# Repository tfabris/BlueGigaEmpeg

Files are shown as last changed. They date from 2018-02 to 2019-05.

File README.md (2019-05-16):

BlueGigaEmpeg
==============================================================================
&copy; 2018 by Tony Fabris

https://github.com/tfabris/BlueGigaEmpeg

BlueGigaEmpeg is a project to use a Silicon Labs BlueGiga WT32i Bluetooth
chip, combined with an Arduino Mega board, to act as an interface between an
empeg Car Mk2/2a MP3 player and a modern Bluetooth-equipped car.

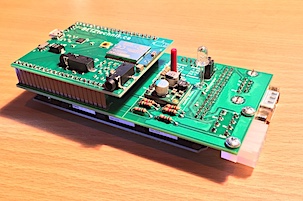
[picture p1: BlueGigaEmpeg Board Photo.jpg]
Board
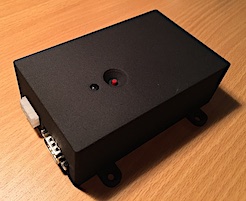
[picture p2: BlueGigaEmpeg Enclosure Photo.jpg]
Enclosure
 

------------------------------------------------------------------------------

Table of Contents
==============================================================================

- [Introduction                                                                    ](#introduction)
- [Installation                                                                    ](#installation)
- [Usage                                                                           ](#usage)
- [Troubleshooting                                                                 ](#troubleshooting)
- [Updating firmware                                                               ](#updating-firmware)
- [Technical Data                                                                  ](#technical-data)

------------------------------------------------------------------------------

Introduction
==============================================================================
- [Project Information                                                             ](#project-information)
- [Caveats                                                                         ](#caveats)
- [Acknowledgments                                                                 ](#acknowledgments)

Project Information
------------------------------------------------------------------------------
The empeg Car (small "e") player, also sold as the Rio Car, is an amazing
in-dash MP3 player made from 1999-2001 whose features are still, nearly 20
years later, better than any other in-car MP3 solution available. However, the
empeg Car didn't have Bluetooth since it wasn't in common use yet at the time.

Modern cars are becoming increasingly difficult to install aftermarket stereos
into, due to the car touchscreen dashboards and the high level of integration
of the stereo system into the other car systems. For owners of the empeg Car
player, it's a problem, because it makes it hard to install our beloved player
into our new cars. This project helps to solve this issue by adding digital
Bluetooth output to the empeg Car player, allowing it to be connected to a
modern car's factory stereo system, and integrate with its controls, in the
same way that you would connect a smartphone to your car.

The BlueGigaEmpeg interface works in two ways:

1. Bluetooth A2DP connection allows high quality digital audio from the empeg
   Car player to play on the modern car's stereo speakers without needing an
   Aux Input on the car stereo. This is useful because many cars no longer have
   an Aux Input available, yet most new cars have Bluetooth. 

2. Bluetooth AVRCP connection allows the empeg Car to receive commands such as
   "next", "previous", "pause", etc. from the Bluetooth connection, allowing
   the car stereo's touchscreen and steering wheel controls to be able to
   change tracks and control playback on the empeg. In addition, the same AVRCP
   channel allows track title and artist information to be displayed on the car
   stereo's touchscreen.

Demo video: https://www.youtube.com/watch?v=XS9U_ALc634

Some modification of the empeg Car is required in order for this to work. The
Molex connector on the empeg docking sled's wiring harness, which is normally
used for an external AM/FM tuner module, must be converted into a digital
audio interface for sending audio data to the BlueGigaEmpeg module. Make sure
to perform all modifications listed in the [Installation](#installation)
section of this document.

Caveats
------------------------------------------------------------------------------
- This project only works with the empeg Car Mk2 or the Rio Car player. It
  will not work with the empeg Car Mk1 player.

- At the time of this writing, I have tested this project on a very limited set
  of Bluetooth gear. So far, I have only tested it on:
  - My Honda Accord 2017 factory stereo.
  - Kenwood KDC-BT318U car stereo.
  - Plantronics Voyager Edge Bluetooth headset.
  - Onkyo TX-SR33 home stereo with Bluetooth input.
  - Etekcity EA-TR1 standalone Bluetooth receiver.
  - iHome Li-B33E7 toy Stardestroyer with a Bluetooth speaker.

- Some Bluetooth stereo playback devices do not have full functionality. For
  example, The Onkyo listed above does not display AVRCP track titles, and my
  2017 Honda does not have controls for Shuffle, Fast Forward, or Rewind. As
  far as I can tell, these are limitations of the devices themselves, not
  problems with the BlueGigaEmpeg: These same limitations exist when those
  devices are paired with smartphones, too.

- This implementation uses the default codec for A2DP audio, SBC (Sub Band
  Codec). This introduces a slight delay in the audio, meaning that the music
  coming out of your car stereo speakers will be slightly delayed from the
  visuals on the empeg screen.

- There are differences in Bluetooth implementation on various audio gear, and
  so there still might be bugs when using the BlueGigaEmpeg on your particular
  car stereo. This project is open source on GitHub, so that I can accept bug
  reports and code fixes from people with other brands of Bluetooth gear.

- This is not intended to replace the empeg front panel user interface. This
  only allows you to do things like press Next Track, Pause, and Play on your
  car stereo. The full menu and user interface of the empeg is still needed
  for all other features of the empeg, such as selecting playlists. So this
  module won't let you mount the empeg in your trunk, unless you also have a
  display extender kit from Eutronix.com as well, which would allow you to
  reach the empeg front panel from the driver's seat. Unfortunately,
  Eutronix.com isn't selling display extenders any more. I was lucky to get a
  display extender several years ago when they were still being sold, so I'm
  able to mount my empeg in my trunk with this. But if you don't have a
  display extender kit, you will still have to mount your empeg someplace
  where you can reach it from the driver's seat.
  - By the way, don't try rolling your own display extender by simply
    extending the wires. Special buffer circuitry is required in order to
    safely extend the empeg display, or you run the risk of damaging the empeg
    or its display.

Acknowledgments
------------------------------------------------------------------------------
Many thanks to the members of the empegBBS who helped with this so much. The
initial chip suggestion was by BBS member Elperepat, and even though I ended
up not using the particular chip that he suggested (I had trouble with that
chip), it was his suggestion that started me experimenting with Bluetooth. Big
thanks to Shonky who had many helpful suggestions and who pointed out the
WT32i chip that is the one that finally got used in this particular design.
Also particular thanks to Stuart Euans of Eutronix.com who created the empeg
Display Extender board, which was critical to me being able to get my empeg
mounted cleanly in my new Honda, since it doesn't have dash space for the
whole empeg. Big thanks to Peter Betz of Betztechnik, who made a convenient
and perfectly-sized breakout board containing the chip I wanted to work with,
and who was very helpful and responsive in emails, and even made another
manufacturing run with an updated design for me. And massive thanks to Mark
Lord who assisted me in countless ways with the design and implementation,
taught me a ton of important things, found my bugs, fixed issues with the
Arduino compiler, modified his Hijack kernel to support this project, and
pointed out all of my EE design flaws. And last but not least, thanks to the
entire empeg team who made such a fantastic car MP3 player that we are still
doing interesting things with it, nearly 20 years later.

Installation
==============================================================================
Installing the BlueGigaEmpeg module requires some modifications to your empeg
Car player. Make sure to go through each of the steps linked below.

- [Prerequisites                                                                   ](#prerequisites)
- [Modify empeg Car interior for I2S digital audio connection                      ](#modify-empeg-car-interior-for-i2s-digital-audio-connection)
- [Disconnect all tuner modules from all sleds you own                             ](#disconnect-all-tuner-modules-from-all-sleds-you-own)
- [Empeg Car configuration changes                                                 ](#empeg-car-configuration-changes)
- [Upgrade the empeg Car's Hijack kernel and set "Serial Port Assignment"          ](#upgrade-the-empeg-cars-hijack-kernel-and-set-serial-port-assignment)
- [Modify empeg's power connection to car                                          ](#modify-empegs-power-connection-to-car)
- [Connect BlueGigaEmpeg to empeg Car player                                       ](#connect-bluegigaempeg-to-empeg-car-player)
- [Mounting                                                                        ](#mounting)

Prerequisites
------------------------------------------------------------------------------
Make sure you have all of these things before working with the BlueGigaEmpeg:

####  Purchase:
| Item | URL |
|:---|:---|
| Empeg Mk2 or Rio Car player | http://empegbbs.com/ubbthreads.php/forums/11/1/For_Sale |
| BlueGigaEmpeg Interface | tfabris@gmail.com |

####  Download software (Windows PC or Windows VM required for some of these items):
| Item | URL |
|:---|:---|
| Hijack Kernel for empeg | http://empeg-hijack.sourceforge.net |
| Tony's Empeg Logo Editor | http://empegbbs.com/ubbthreads.php/ubb/download/Number/7067/filename/logoedit17.zip |
| Arduino standalone IDE | https://www.arduino.cc/en/Main/Software |
| Latest BlueGigaEmpeg Arduino firmware | Direct download latest project file: https://github.com/tfabris/BlueGigaEmpeg/archive/master.zip |
| | (Alternative) GitHub project for cloning, if you are using the Git tool: https://github.com/tfabris/BlueGigaEmpeg |

####  Important:

The BlueGigaEmpeg module works by connecting to the Molex connector on the
empeg Car's docking sled wiring harness. This connector was originally
intended for the empeg's external tuner module. The empeg must be modified so
that the tuner module connector becomes a digital audio connection instead.

Do not connect the BlueGigaEmpeg to the tuner module connector until after
completing the step in this document titled ["Modify empeg Car interior for
I2S digital audio connection"](#i2s). Also, once the I2S modification has been
completed, connect the Molex tuner module connector *only* to the
BlueGigaEmpeg, do not connect it to a tuner module, or to anything else.
Damage may occur if these instructions are not followed.

Be sure you are capable of safely making internal modifications to the empeg
Car player, and you are able to solder and shrink-tube electronic components.
I take no responsibility for damage incurred while you are dismantling and
modifying your empeg Car player.

Modify empeg Car interior for I2S digital audio connection
------------------------------------------------------------------------------
To perform this step, you must be comfortable with disassembling the empeg Car
player and removing the disk drive tray in such a way as to not cause damage
to the player. In particular, there is risk to the components on the back side
of the display board, and to the IDE header connector on the empeg
motherboard. Use extreme caution when disassembling the empeg player.

You will be modifying the interior of your empeg Car so that there can be
three wires coming out the docking connector which carry digital audio data
("I2S" aka "IIS") and can connect to the BlueGigaEmpeg unit. This is done by
hijacking three of the wires originally used for the empeg tuner module on its
Molex connector. This tuner module connector will instead plug into the
BlueGigaEmpeg electronic assembly, which contains the Bluetooth chip and the
Arduino.

The empeg tuner module will no longer work after this modification, and damage
may occur if you connect one to your player. If you have a tuner module, now is
a good time to disconnect it from the sled and put it away.

####  Disassembly of empeg Car:

Partially disassemble your empeg player by carefully removing the fascia, lid
and drive tray, as described below. You must do the disassembly gently, so as
not to damage the empeg. Make sure not to break any of the components sticking
off the back of the display board as you do this.

- Use a 2.5mm hex tool to carefully remove four hex bolts from the fascia.

- Gently remove fascia, buttons, rotary control, and colored lens.

- Extend the hinged pullout handle during the next step. This lowers the
  keeper hooks on the top of the player, which keep it hooked into the sled
  and which will also interfere with the lid removal if they aren't lowered.
  If you have trouble removing the lid in the next step, first double check
  that the handle is in the extended position.

- Remove lid by sliding it forward and upward over the tabs. This may be
  tricky on some players, requiring some gentle levering against the tabs with
  a screwdriver. You shouldn't need to bend or force anything, but it may be a
  bit of a tight fit as you remove it. Use caution not to slip and damage the
  components on the display board. As shown in this photo:
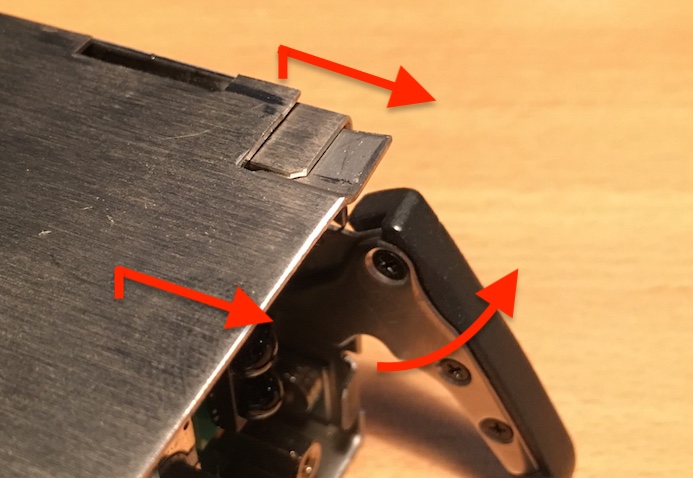
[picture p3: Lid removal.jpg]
Lid removal
  

- Do not remove the display board.

- Remove four Pozidriv screws on the outside sides of the player which are
  holding the disk drive tray in place. Be careful not to strip the screw
  heads by using the wrong size or type of screwdriver. Make sure to select a
  screwdriver which fits the heads of the screws good and tight. Information
  about Pozidriv screws can be found here:
  https://en.wikipedia.org/wiki/List_of_screw_drives#Pozidriv

- Gently lift out the drive tray. Make sure not to bump any of the
  components on the back of the display board. There are some particularly
  fragile components there, and it's really important that you don't bump
  them, or your empeg display will stop working entirely. They are really easy
  to hit, too, so be super careful.

- When lifting out the drive tray, take note of how the IDE cable is folded
  and routed so that you can put it back exactly as you found it. 

- Do not disconnect the IDE cable. You should be able to set the drive tray
  gently aside, without disconnecting the cable, and also without putting
  any stress on the cable.

####  Jumper the I2S pads to the docking connector wires:

Refer to the annotated photograph "I2S Wiring Modification Photo.jpg" to help
understand the wiring instructions below.

I2S Wiring Modification Photo.jpg:
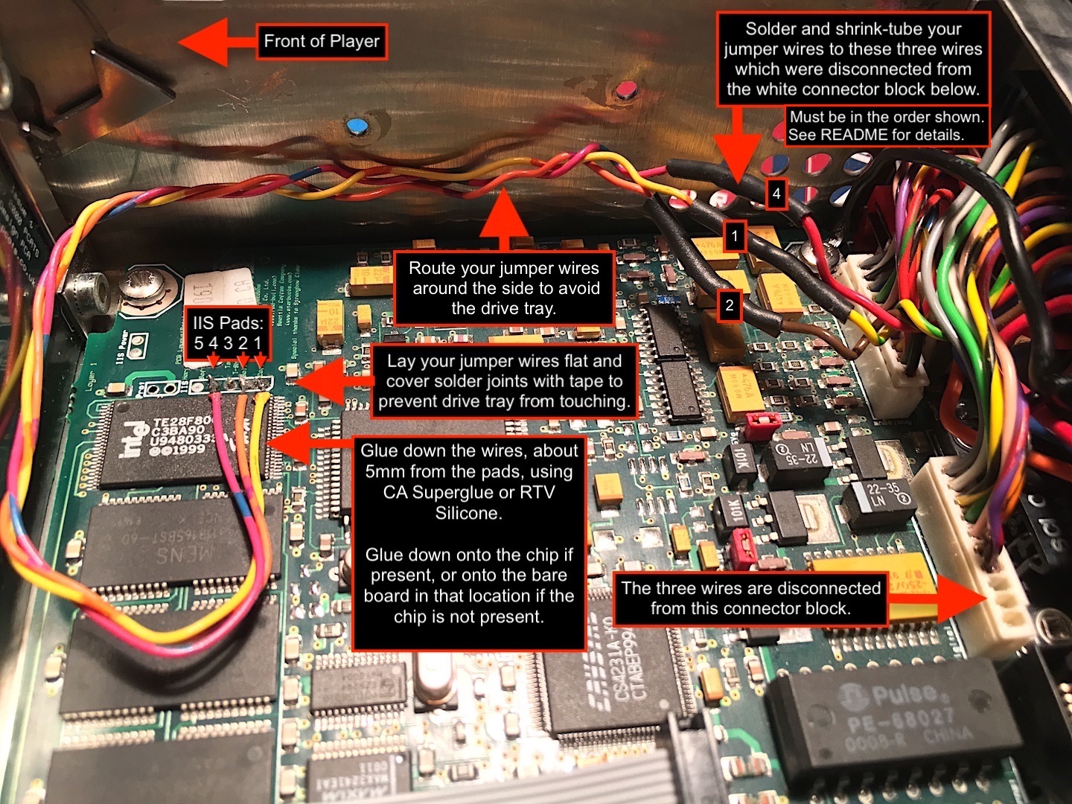
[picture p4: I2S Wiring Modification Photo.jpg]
Wiring Modification


Locate 5 blank I2S pads on the front left side of the empeg motherboard.
Pads are outlined in a white silkscreen rectangle with the letters "IIS" next
to the outline. White silkscreen rectangle will have one corner of it with a
small diagonal "snip" to the corner which will indicate pad number 1 of the
set of 5 pads. This diagonal snip will be towards the back of the empeg, and
the remaining pads continue towards the front of the empeg. Pads are not
individually labeled with numbers, but understand that they are logically
numbered 1 2 3 4 5 starting from the back and going towards the front of the
empeg. The pinouts of these five pads are:

      1 = IISC  aka  SCK     aka "serial clock"
      2 = IISW  aka  WS      aka "word select"
      3 = GND   aka  Ground  same as chassis ground of empeg
      4 = IISD1 aka  SD      aka "serial data" (1 of 2)
      5 = IISD2 aka  SD      aka "serial data" (2 of 2)

Carefully solder the three supplied jumper wires to pads 1,2, and 4, and you
must keep track of which wires are soldered to which pads.

Note: The coloring of the supplied jumper wires is random and arbitrary. They
are each colored differently, so that you can tell which ones were soldered
to which I2S pads, but their particular colors are not intended to match
anything.

When soldering, make sure the jumper wires and the solder joints are flat to
the board instead of sticking upwards. The disk drive tray gets close to that
location when mounted, so make sure they don't have a chance to contact the
tray.

After soldering, cover the solder points with tape or some other insulator to
prevent them from shorting out on the drive tray.

Locate the two white connectors on the back part of the empeg motherboard
which connect two groups of small colored wires to the docking connector
assembly. Locate the rightmost of the two connectors nearest the Ethernet port
on the back of the empeg. Unplug this connector, and using a tiny flat tool
such as the tip of a jeweler's screwdriver, lift up the small white tabs and
gently disengage and pull out the pins. Pull out only the rightmost three pins
nearest the Ethernet connector to free up those three wires. These wires are
colored, going from left to right, yellow+green, red, and brown. The brown
wire is the one on the right end closest to the Ethernet connector, the red
wire is the second from the end, and the yellow+green wire is the third from
the end.

With the three wires disconnected from the white connector, plug the white
connector back into place with the remainder of its wires still connected.
You should now have three wires inside the empeg, each with one end still
connected to the docking connector assembly, and their other ends loose with
small pin connectors on the ends of them.

Carefully solder and shrink-tube your three jumper wires directly to these pin
connectors in the exact order described below. Shrink tubing has been
supplied with the BlueGigaEmpeg. Don't forget to put the shrink tubing onto
the jumper wires before you solder them.

Solder your jumper wires to the empeg interior wires in this order:

- IIS Pad 1 (IISC): jumpered to the yellow+Green wire which was originally the
  third wire the from end of the white connector.
- IIS Pad 2 (IISW): jumpered to the brown wire which was originally the end
  wire on the white connector.
- IIS Pad 4 (IISD1): jumpered to the red wire which was originally the second
  wire from the end of the white connector.

After you have done this, your empeg's I2S pads will, when docked, now be
carried out the back of the empeg, via the docking sled, into the Molex tuner
module connector.

Make sure that your jumper wires are carefully tucked down around the left
side of the empeg and out of the way of the disk drive tray assembly as shown
in the photo linked above.

Glue down your jumper wires near the I2S pads so that they do not wiggle and
rip away the I2S pads. Some empeg Car units will have a chip at that location
that you can glue onto, others will have a blank area of the PCB in that
location that you can glue onto. Use RTV silicone or cyanoacrylate superglue
to glue them down. Use a small amount of glue, and make sure the blob of glue
does not "stick up", since the disk drive tray gets very close to that
location.

After the glue is fully dry, carefully reassemble the player. Reassemble in
the reverse order of disassembly. Make sure to put everything back where you
found it, in particular, make sure the IDE cable is folded and routed the same
way as it was when you disassembled the player.

When reassembling, be careful not to overtighten the hex bolts which hold the
fascia in place, they should only be finger-tight. If you overtighten them,
you may crack the fascia and/or prevent the buttons from working correctly.

Final wiring positions and colors:
                                                                                                                                                                
| Empeg IIS pads | Int. empeg wires * | Int. white conn pos **  | Sled Tuner Plug | BlueGigaEmpeg Tuner Plug | Bluetooth Chip | Usage |
|---|---|---|---|---|---|---|
|  1 IISC |  Yellow+Green wire |  Third from end |  7 Purple |  7  SCK |  30  PCM_CLK |  Serial Clock |
|  2 IISW |  Brown wire |  Right end |  2 Grey |  2  WS |  29  PCM_SYNC  |  Word Select aka Sync |
|  4 IISD1 |  Red wire |  Second from end |  1 Pink |  1  SDIN |  27  PCM_IN |  Serial Data aka PCM Audio Data  |
| | | |  4 Black |  4  GND | GND |  Universal Ground |
| | | |  8 Blue |  8  12vPower | |  Power to voltage regulator |

    *  (These are the interior wires running between the docking sled and the
        white connector on the empeg motherboard.)
    
    ** (Original positions of these wires on the white connector near the
        Ethernet plug, now disconnected from that connector.)

Disconnect all tuner modules from all sleds you own
------------------------------------------------------------------------------
After completing the I2S wiring modification, the external empeg tuner module
will no longer work. Also, damage may occur if you connect a tuner module to a
modified empeg.

To prevent problems, make sure to disconnect any tuner modules from any
docking sleds that you own, and pack them away somewhere safe. After making
the I2S wiring modification to the empeg, do not use a tuner module any more.

Label your empeg with the supplied stickers, which tell your future selves
not to use this particular empeg with tuner modules any more.

Empeg Car configuration changes
------------------------------------------------------------------------------
The following configuration changes are required for BlueGigaEmpeg to work
correctly.

####  Player firmware version:

I have tested the BlueGigaEmpeg with version 2.00 of the empeg Car software.
It is designed to work with version 2.00 Beta 13 or version 2.00 Final. I have
not tested it with the 3.0 Alpha version of the empeg Car software, but
theoretically it should work.

#### Edit the config.ini on the player:

Using the Emplode or Jemplode software, edit the empeg Car's config.ini as
follows.

If you are using Emplode on Windows, you must first edit the Microsoft Windows
registry before it will allow you to alter the config.ini. First, run
REGEDIT.EXE in Windows and modify the following key:

     HKEY_CURRENT_USER
       Software
         SONICblue
           emplode
             2.0
               Settings
                  (Inside the "Settings" key, create a new DWORD value named:)
                    allow_edit_config
                      (with a value of)
                        1              

Then restart the Emplode software. Emplode will now have a menu option
which allows you to edit the config.ini on the player.

Change the settings in config,ini as follows (adding new section headers such
as [hijack] only if that section does not already exist):

    [hijack]
    suppress_notify=2
    
    [output]
    notify=1
    
    [serial]
    car_rate=115200

These settings are case-sensitive. Make sure to synchronize with the player
after changing the config.ini settings.

Upgrade the empeg Car's Hijack kernel and set "Serial Port Assignment"
------------------------------------------------------------------------------
The latest version of Hijack is required in order for BlueGigaEmpeg to work
correctly. Install the latest Hijack Kernel onto the empeg Car player if it is
not already installed. Link to the Hijack kernel is found in the
[Prerequisites](#prerequisites) section of this document. Make sure it is
Hijack version 524 or later.

In order to install the latest Hijack Kernel onto the empeg, you must connect
the empeg directly to your computer's RS-232 serial port, or to a USB-to-
RS-232 adapter cable if your computer does not have an RS-232 serial port.
Make sure the serial port drivers are installed and that you can see the empeg
bootup messages correctly through a serial terminal program.

To install the Hijack kernel, run Tony's Empeg Logo Editor. Link to the Logo
Editor program is found in the [Prerequisites](#prerequisites) section of this
document. This program is a Windows program, but it should also work correctly
on a virtualized version of Windows. For example, I have used it successfully
running under Parallels on a Mac. On the File menu of the logo editor program,
select "Kernel Flash Utility" and follow the instructions.

Once Hijack is installed, open up the Hijack kernel settings on the player via
a long-press on the player's rotary encoder dial. Change "Serial port
assignment" to "Player uses serial port" and follow the on-screen instructions
to reboot the player.

Modify empeg's power connection to car
------------------------------------------------------------------------------
I recommend that for this installation, you connect the empeg's wiring harness
to your car differently than if it were a standard car installation. It might
not be required for your installation, but it was required for mine, so doing
this now could save you time and hassle later.

This BlueGigaEmpeg is designed to turn the empeg into a secondary Bluetooth 
input into a modern car stereo, rather than being the car's main stereo 
system. In this situation, the empeg's sleep mode, the empeg's "memory" power 
connection, the way the BlueGigaEmpeg module gets its power from the empeg 
tuner connector, and the way the car stereo issues Bluetooth commands when 
you shut off the ignition, all combine to cause some interesting problems with
power state transitions.

I found that if I connected the empeg to my car's power via the regular method
(i.e., car accessory power to the orange ignition wire on the sled, and car
constant 12v power to the yellow memory wire on the sled), then there were
certain unusual states that it could get into. Sometimes I would shut off my
car, but the empeg would come back up out of sleep mode and play tracks
silently to an unconnected Bluetooth module, draining my car's battery.

To prevent this problem from happening to you, I recommend connecting power
between the car and the empeg like this instead:

- Orange "ignition" wire from empeg: Connect to car 12v accessory power.
  - "Acessory Power" is the power that is only on when your car ignition is
    on, or your key is set to the "accessory" position so that your car
    stereo is turned on. Or the pushbutton equivalent of that, if your car
    doesn't have a physical key.

- Yellow "memory" wire from empeg: *Also* connect to car 12v accessory power
  (instead of the usual constant power).

- Do *not* connect your car's constant 12v power to any part of the empeg.

- White "lights on" wire from empeg: Connect to car dash illumination power.

- Black "ground" wire from empeg: Connect to car ground.

- Tuner module and serial plug connectors: Connect to BlueGigaEmpeg module.

That should be all you need. No analog audio or amplifier connections, because
the Bluetooth takes care of that now. No cellphone mute wire, because the
Bluetooth takes care of that now. No amp remote wire, because there is no amp
connected directly to the empeg.

When connected this way, the empeg does not receive a 12v constant power
source. Instead, it will completely lose all power when you turn off the
ignition, rather than going into sleep mode. The empeg and its attached
BlueGigaEmpeg module will always power on and off at the same time as the car
stereo, and nothing will get confused about power state. You might lose the
date/time information on the empeg sometimes, but your modern car likely has a
perfectly functional clock of its own. The empeg is already designed to save
its playback position when it unexpectedly loses power, so it will continue to
work correctly in this wiring scheme.

In a normal car install, with analog audio and an amplifier connected to the
empeg, the wiring scheme described above would cause a pop sound when turning
off the ignition. But with the BlueGigaEmpeg, all audio is digital, and goes
through the Bluetooth connection, so there will not be a pop sound.

By the way, I'm using a set of "Add-a-circuit" fuse adapters to connect my
empeg to the car's power at the car's fuse panel. This let me avoid the hassle
of trying to tap into the factory stereo wiring. If you use this method, make
sure to research to find the correct size for your car. For example, mine are
the "low profile mini fuse" type. Some helpful links:
- https://en.wikipedia.org/wiki/Fuse_(automotive)
- https://www.google.com/search?q=Add-a-circuit+Fuse+Adapter

Connect BlueGigaEmpeg to empeg Car player
------------------------------------------------------------------------------
Only do this step after completing the prior step in this document titled
["Modify empeg Car interior for I2S digital audio connection"](#i2s).

If the I2S wiring modification has been completed, connect the tuner module
connector from the empeg Car player docking sled to the tuner connector on the
BlueGigaEmpeg module. This plug carries 12v power to the BlueGigaEmpeg module
and also carries I2S audio data.

Connect the RS-232 serial plug from the empeg Car player docking sled directly
to the serial port on the BlueGigaEmpeg module. This plug carries the
play/pause/next control commands from the BlueGigaEmpeg to the empeg Car
player software, and also carries the track metadata (title/artist/etc) from
the empeg Car player software to the BlueGigaEmpeg module.

####  USB Connector:

The USB "type B" connector on the outside of the BlueGigaEmpeg module
enclosure is left disconnected during normal operation. It is only used for
debugging, and for uploading the latest Arduino sketch to the BlueGigaEmpeg
module. However, if you are mounting your BlueGigaEmpeg module permanently in
a hard-to-reach location in your car, make sure to run a USB cable from this
port to a reachable location, so that you can connect a laptop to it later.
See the section of this document titled ["Debug Bluetooth Connection if
needed"](#debug) for more details on how to use the USB connector for
debugging.

Mounting
------------------------------------------------------------------------------
The BlueGigaEmpeg module can be permanently mounted to the car if needed. Four
mounting tabs are included on the casing for this purpose, though Velcro or
other methods can work too. It can also be simply stuffed in somewhere with
the rest of the attachment wiring, as long as it's not "dangling" and putting
stress on the attachment cables.

When mounting:

- Try to leave the BlueGigaEmpeg's recessed RESET/PAIR button reachable
  somehow. You won't need to use it very often, but when you do, it's super
  nice to be able to reach it. If you can't make the button reachable, then
  the USB cable will also allow you to pair, but the button is much more
  convenient.

- Make sure to leave the BlueGigaEmpeg's USB debug port accessible for
  firmware updates and debugging. If you have mounted the BlueGigaEmpeg in a
  hard-to-reach location, then my best recommendation is to find a long USB
  type-A-to-type-B cable (It's a standard USB printer cable, you probably
  have a few extras of these lying around already), attach it to the
  BlueGigaEmpeg's USB debug port, and route it somewhere in your car that can
  be reached with a laptop.

- Make sure the empeg itself is mounted so that its front panel is still
  visible and accessible from the driver's seat. The BlueGigaEmpeg isn't a
  replacement for the empeg's user interface.

Usage
==============================================================================
- [Pairing                                                                         ](#pairing)
- [Normal operation                                                                ](#normal-operation)

Pairing
------------------------------------------------------------------------------
Turn on your car's ignition to apply power to the empeg. This should also
apply power to the connected BlueGigaEmpeg module via the tuner module
connector. Make sure the empeg is not in "sleep" mode, since power to the
tuner module connector is turned off in sleep mode.

The first time you use the BlueGigaEmpeg, you will need to pair it with your
Bluetooth car stereo. The BlueGigaEmpeg has a recessed RESET/PAIR button
for this purpose.

####  Pairing Procedure:

- Turn the volume level on your car stereo down to a low level, so that you're
  not blasted when the pairing process is complete.

- If your car stereo has a feature that lists existing Bluetooth pairings, and
  if there is an existing entry for "empeg Car" from an earlier pairing (for
  example, if you need to pair a second time), make sure to delete that
  earlier entry from the car stereo, because its security key will become
  invalid when you press the RESET/PAIR button in the next step.

- Press the recessed RESET/PAIR button on the BlueGigaEmpeg module. You do
  *not* need to hold down the button, a single click is all it needs. The
  adjacent LED should light up blue for about 60 seconds or so.
  
  - If you can't reach the RESET/PAIR button, then it is also possible to
    initiate pairing from the USB debug connection, via a connected laptop, by
    typing a Z followed by pressing the Enter key in the Arduino Serial
    Monitor. See ["Debug Bluetooth connection if needed"](#debug) for more
    information.

- On the car stereo, initiate its pairing mode while the blue LED on the
  BlueGigaEmpeg module is lit. If the stereo offers you a list of devices to
  pair with, then look for the device "empeg Car" and pair it.

  - Some car stereos will allow you to pair without needing to press the 
    recessed RESET/PAIR button on the BlueGigaEmpeg. For stereos with this
    capability, you will be able to see and select the "empeg Car" from the
    list of nearby devices, even when the blue LED on the BlueGigaEmpeg is not
    lit. If this is the case, it is still OK to press the button, the pairing
    should succeed whether you press the button or not.

- Your car stereo might put up a random number on the screen and prompt you to 
  confirm that number on the device. If it does, the BlueGigaEmpeg will
  automatically confirm that number for you.
  
- Your car stereo might prompt you to press a button to confirm or finalize
  the pairing process, or it might prompt you to choose the connection type.
  For instance, on my Honda, its touchscreen will prompt me to choose
  whether to pair it as a music device, a phone device, or both. If you get
  a prompt like this, choose the music device option.

- If the pairing still doesn't work, try sleeping the empeg (long press on top
  button), then waking it up again with another button press. This will reboot
  the BlueGigaEmpeg module.

- If pairing still doesn't work, try turning off the car stereo completely
  (turn off car ignition), turn on the car ignition again, sleep and wake the
  empeg, and try again from the top. This ensures that both devices have been
  fully rebooted.

- When the pairing is completed, set the volume. With the car stereo volume
  still turned down to a low level, turn the volume on the empeg Car front
  panel all the way up to 0.0 db. Then gently increase the volume on the car
  stereo to the desired listening level. From now on, control the the overall
  volume level from the car stereo controls and leave the empeg set to 0.0 db.
  Note that there are features in the Hijack kernel for setting the volume
  level on startup, so if the empeg keeps booting into a low volume mode,
  check the Hijack kernel settings for "Volume Level on Boot" and set it to
  "Previous".

Car and empeg should be playing nicely together now, assuming everything else
is working correctly. Audio from the empeg comes out of your car stereo's
speakers, the car stereo's track change controls will change tracks on the
empeg, and the track titles will appear on the car stereo's screen.

See [Troubleshooting](#troubleshooting) if you encounter any problems.

Normal operation
------------------------------------------------------------------------------
After you have successfully paired with your car stereo once, you should not
need to pair it again each time you get in the car. It should automatically
reconnect each time you start your car.

Some car stereos will let you pair your phone and the empeg at the same time.
Not all car stereos will have this feature. My Honda allows me to do this, and
it works like this: When pairing, the car's touch screen lets me choose
whether the paired device is a phone device, a music device, or both. I choose
to pair my phone as a phone, and the empeg Car as a music device. Then, each
time I start my car, they both pair up correctly. I can use the steering wheel
controls to initiate a speakerphone call, which automatically pauses playback
on the empeg, and resumes playback after I hang up the call.

The empeg Car should automatically pause its playback when you turn off the
car stereo. It should also pause when you switch to another input source on
your car stereo, such as switching to the radio or to the CD player. It should
automatically resume playback when you turn the stereo on, or switch back to
the Bluetooth input.

The empeg Car should automatically pause its playback immediately after its
boot sequence is complete, then it will wait until there is a successful
Bluetooth connection, then it will resume playback after Bluetooth is
connected. If Bluetooth is already connected by the time that the empeg boot
sequence is complete, it will resume playback when it is done booting up. This
prevents the empeg from playing music silently while it waits for your car
stereo to boot up. This is needed for some cars whose stereos have long boot
times which exceed the empeg boot time. My Honda has a stereo like that, it
takes about 25 seconds to boot up and be able to play Bluetooth music, more
than twice as long as the empeg takes to boot up. Without this feature, there
would be about 15 seconds' worth of song "lost" (played silently) each time I
started my car.

The BlueGigaEmpeg implements a specific set of Bluetooth controls. Not all car
stereos support all of these controls. For instance, my Honda does not do
Fast Forward or Rewind with any Bluetooth device, so those particular features
don't work on my Honda.

####  Implemented:
 - Pause
 - Play
 - Previous Track
 - Next Track
 - Rewind
 - Fast Forward
 - Stop
   - Pressing Stop on the car stereo should pause the empeg.
 - Shuffle
   - Shuffle is implemented as a toggle on/off command. If your stereo has a
     feature to display the current shuffling state (displaying whether
     shuffle is currently turned on or turned off), it will not be correctly
     indicated on your stereo's screen. The empeg car does not report its
     shuffle state to the serial port, so the BlueGigaEmpeg cannot report the
     correct state of shuffle to the car stereo. Pressing the shuffle button
     on the car stereo should still toggle the empeg's shuffle on and off,
     regardless of the indicated state. Since the empeg has different types
     of shuffle, toggling shuffle from the car stereo will send the "%" 
     command to the serial port on the empeg, which I believe will toggle
     back and forth between "shuffle off" and "shuffle using the last shuffle
     type that you previously selected".

####  Not implemented:
The items below are not implemented on the BlueGigaEmpeg, but you can still do
them on the empeg's front panel.
 - Music search or playlist/track browsing
 - Menu selection and navigation
 - Repeat mode (repeat all tracks, repeat one track, etc.)
 - Volume up/down/mute (set empeg to 0.0db and use car stereo volume instead)
 
####  Sleep mode:
The empeg tuner connector only supplies power to the BlueGigaEmpeg module if
the empeg is awake. If you put the empeg into sleep mode via a long press on
the top button, it will go to sleep, but that also means the Arduino+Bluetooth
assembly stops receiving power. This is actually good: you want to be able to
turn the Bluetooth on and off and reboot it sometimes, and it's easy to do
that just by sleeping and waking the empeg from its front panel.

Most of the time, leave the player in "awake" mode. When you shut off the car
ignition, the player fully shuts down. When you start the car again, the empeg
starts up in "awake" mode and immediately supplies power to the BlueGigaEmpeg
module, which then automatically connects to the car stereo head unit.

Troubleshooting
------------------------------------------------------------------------------
- [Reboot the Bluetooth module                                                     ](#reboot-the-bluetooth-module)
- [Always use the latest firmware                                                  ](#always-use-the-latest-firmware)
- [Pairing issues                                                                  ](#pairing-issues)
- [Other issues                                                                    ](#other-issues)
- [Set Bluetooth PIN code if needed (most likely not needed)                       ](#set-bluetooth-pin-code-if-needed-most-likely-not-needed)
- [Test AVRCP behavior and set serial port crossover jumpers if needed             ](#test-avrcp-behavior-and-set-serial-port-crossover-jumpers-if-needed)
- [Debug Bluetooth connection if needed                                            ](#debug-bluetooth-connection-if-needed)

Reboot the Bluetooth module
------------------------------------------------------------------------------
Some problems can be solved by rebooting the Bluetooth module. Simply sleep
the empeg by pressing and holding the top button, then wake it up again with
another button press. This bounces power to the tuner module connector where
the BlueGigaEmpeg gets its power.

Always use the latest firmware
------------------------------------------------------------------------------
When troubleshooting, always start with the most recent versions of the
BlueGigaEmpeg firmware and Hijack Kernel.

- To update the BlueGigaEmpeg firmware, see the section titled ["Updating
  firmware"](#updating-firmware).

- To update the Hijack kernel, see the section titled ["Upgrade the empeg
  Car's Hijack kernel and set Serial Port Assignment"](#hijack).

Pairing issues
------------------------------------------------------------------------------
When you press the recessed RESET/PAIR button on the BlueGigaEmpeg, it does
the following:

 - Erases all previous Bluetooth pairings and security keys from the Bluetooth
   chip.
 
 - Resets the Bluetooth chip to default settings.

 - Looks for Bluetooth devices to pair with for about 60 seconds, and pairs
   automatically with the first one that it sees. Starting with version 1.1.5
   of the BlueGigaEmpeg sketch, it will alternate between searching for
   devices and listening for devices during pairing mode.

 - The blue RESET/PAIR LED is lit during this pairing mode, and will turn
   off once pairing is complete, or once the 60 seconds has run out.

Paired devices share a set of security keys with each other. Pressing the
recessed RESET/PAIR button on the BlueGigaEmpeg module erases previous
pairings, thus erasing those keys from the WT32i chip. This is important if
your car stereo remembers an onscreen list of existing paired Bluetooth
devices and gives you the option to manage those devices: The empeg Car's
entry in that list becomes invalid when you press its RESET/PAIR button. So
you will need to delete the empeg Car from that list before trying to pair
it a second time. Conversely, if you delete the empeg Car from your car
stereo's list of paired devices, you'll also need to clear the security key
from the Bluetooth chip by pressing the RESET/PAIR button on the
BlueGigaEmpeg module.

Sometimes Bluetooth devices can get into odd states which require a reboot to
fix. If you're having pairing troubles, try rebooting the BlueGigaEmpeg by
sleeping and waking the empeg with a long press on the top button of the
front panel, followed by another button press to wake it. If that doesn't
work, try rebooting both devices: Reboot the car stereo by turning the
ignition off and on again, and also reboot the BlueGigaEmpeg by sleeping and
waking the empeg.

When trying to pair, turn off any nearby Bluetooth devices which are in
"discoverable" mode or "pairing" mode. The BlueGigaEmpeg has no user
interface, so it has no way to pick and choose which device it's trying to
pair with. It will attempt to pair with the first one it sees, so if there's
more than one pairable device in the immediate vicinity, it might not get the
one you think it's getting.

If necessary, experiment with different positioning of the BlueGigaEmpeg
module in relation to your car stereo. The Bluetooth chip is located near the
top center of the unit, near the recessed RESET/PAIR button. It will work best
if it has line of sight to your car stereo and/or is physically close to it.

Other issues
------------------------------------------------------------------------------
If there is good audio, but commands such as next/previous track and
play/pause don't work, and if track titles do not display on your car stereo,
See the section titled ["Test AVRCP behavior and set serial port crossover
jumpers if needed"](#test-avrcp-behavior-and-set-serial-port-crossover-jumpers-if-needed).

Check to make sure that the wires for the serial port connection (or any other
connection for that matter) have not pulled out of the back of the docking
connector on the empeg sled. This is a common problem. See here for the
correct wiring scheme: http://empegbbs.com/ubbthreads.php/topics/370309/

If AVRCP commands and track titles fail to work intermittently, and it has
occurred after you have uploaded a new version of the BlueGigaEmpeg firmware
to the Arduino, then check to make sure that your Arduino IDE's compiler files
have the corrected values for the serial port buffers as described in the
[Updating firmware](#updating-firmware) section.

If you have trouble with the empeg waking up after you shut off the car
ignition, see the section here: ["Modify empeg's power connection to
car"](#power).

If you notice that there is a slight delay between the visuals on the empeg
screen compared to the sound coming out of the car stereo speakers, this is
normal. The Bluetooth chip uses the Sub Band Codec (SBC) which is the default
codec for A2DP audio, and that codec has a slight latency.

Check to see if the issue you're encountering is a known bug or a
previously-closed bug:

- Open bugs: https://github.com/tfabris/BlueGigaEmpeg/issues

- Closed bugs: https://github.com/tfabris/BlueGigaEmpeg/issues?q=is:issue+is:closed

If you have other problems not listed here, see this section: ["Debug
Bluetooth connection if needed"](#debug).

Set Bluetooth PIN code if needed (most likely not needed)
------------------------------------------------------------------------------
BlueGigaEmpeg does not usually require a PIN code to successfully pair. Before
trying to modify the PIN code, simply try pairing first.

Some stereos will prompt with a random set of digits on the screen and ask you
to confirm those digits on the Bluetooth device with a Yes/No prompt. This is
not the same thing as a PIN code. In those cases, the BlueGigaEmpeg will try
to automatically answer this prompt with a "yes" answer so that no user
interaction will be needed.

In rare cases where a special PIN code is is needed, there is a place in the
"BlueGigaEmpeg.ino" source code file where you can modify the PIN to something
other than "0000". Find the line in the sketch that defines the variable
"btPinCodeString". That line contains the "0000" default PIN code. Change it
to your correct PIN code for your stereo and re-upload the sketch to the
Arduino. It can accept PIN codes up to 16 digits long.

Test AVRCP behavior and set serial port crossover jumpers if needed
------------------------------------------------------------------------------
If you are lucky, the empeg will respond to commands from your car stereo's
controls for play, pause, next track, etc., and the car stereo will display
track titles on its touchscreen. This is done via the Bluetooth Audio Video
Remote Control Profile ("AVRCP"), and the serial port connection to the empeg
Car.

However, if the Bluetooth pairs successfully and streams music, but you are
unable to play/pause/next the empeg via the car stereo's controls, and the
track titles don't show up on the car stereo's screen, then try the following.

- First check to make sure that your car stereo even has the features you're
  trying to use. For example, try pairing your smartphone to the car stereo
  and see if you get play/pause/next/previous commands, and track titles,
  with that.

- If AVRCP commands work with your smartphone, but not with the empeg, double
  check that the serial port is actually working on the empeg docking sled,
  and that none of its wires have pulled out of the docking connector.

- Verify that you get good serial port messages from the empeg when you
  connect the RS-232 serial cable directly from your computer to the empeg
  docking sled serial port connection (with the BlueGigaEmpeg out of the
  picture), and verify that they are coming in correctly at 115200 BPS.

- If the serial port is good, but you still get no joy with AVRCP commands or
  track titles, then make sure that you correctly upgraded your player to the
  latest Hijack kernel as described [here](#hijack), and that you performed
  the changes listed in
  ["Empeg Car configuration changes"](#empeg-car-configuration-changes).

- If the above things are verified as good, then use [debug mode](#debug),
  temporarily enable the "displayEmpegSerial" feature in the Arduino sketch,
  upload the sketch to the Arduino, cycle the power on the empeg, and watch
  to make sure that serial output from the empeg appears on the screen. If
  no serial port messages from the empeg appear in the debug console with
  "displayEmpegSerial" enabled, then there is a chance that the serial
  wiring is crossed over. Try changing the crossover jumper block inside
  the BlueGigaEmpeg module:

  - The crossover jumpers exist because I have seen empeg sleds with
    different wiring on the RS-232 plug. Some are wired straight, some are
    wired crossover. I added the jumpers so that you can set the
    BlueGigaEmpeg board as straight or crossover to compensate for this. The
    BlueGigaEmpeg ships with its jumpers in the crossover configuration by
    default, in order to compensate for the situation where the empeg sled
    serial plug is wired as straight through. I think/hope this is the most
    common configuration.

  - To change the jumpers, open the BlueGigaEmpeg enclosure with a 2.5mm hex
    tool and lift out the electronic board assembly. Look near the button
    and LED, and you'll see the RS-232 Crossover jumper block, with
    silkscreened instructions on the board to describe how to change the
    setting. Set the RS-232 Crossover jumper block to the opposite setting.

  - Place the board assembly back into the BlueGigaEmpeg enclosure so that
    the recessed RESET/PAIR button and the LED fit into their corresponding
    holes on the enclosure. If the LED got bent, straighten it carefully so
    the LED fits into its hole in the casing.

  - You should not need to force the BlueGigaEmpeg board assembly back into
    its casing, but it is a very precise fit so that it doesn't rattle. You
    might have to nudge and coax it a bit into its final position, but it
    should fit perfectly without forcing it. When placing the lid back onto
    the enclosure, the lid should fit gently and perfectly, and should close
    completely, without forcing it down. If you feel like you need to force
    the lid closed, then you either have the lid backwards, or you haven't
    gotten the board assembly seated back into the casing correctly, so try
    again.

  - When reassembling the BlueGigaEmpeg enclosure, make sure to put the
    screws back in carefully. If you're using a powered screwdriver, use a
    slow speed, so that friction and heat don't melt the 3D printed plastic,
    thus stripping the screw holes. Make sure not to overtighten the screws,
    which would also strip the screw holes. Just make them tight enough to
    keep the casing cleanly shut.

  - Recheck and see if this fixed the issue, then return the variable
    "displayEmpegSerial" back to its original state, and re-upload the sketch
	to the Arduino.

- If changing the crossover jumpers does not make the empeg's serial port
  messages appear on the Arduino debug console with "displayEmpegSerial"
  enabled, then you've still got a serial port problem. Put the crossover
  jumpers back to their original setting, and re-diagnose from the top.

Debug Bluetooth connection if needed
------------------------------------------------------------------------------
Everything hopefully will work perfectly, but there may be bugs in the Arduino
code because this was not tested with a wide range of Bluetooth gear. If you
need to debug the connection, here are some helpful tips.

####  Debug mode with Arduino

The BlueGigaEmpeg module is an Arduino command+control board, sandwiched to a
custom interface board, connected to a BlueGiga WT32i Bluetooth chip. The
firmware running on the Arduino allows for a terminal debug interface to the
Bluetooth chip. This is automatically invoked when you connect a USB cable
from your computer to the Arduino's USB connector, which is the USB-B
connector accessible on the outside of the BlueGigaEmpeg casing. Once
connected, a USB-serial port will appear as a device on your computer through
the UART chip built into the Arduino.

Installing device drivers for the Arduino's USB-serial UART will be needed. To
install the device drivers and get the Arduino Serial Monitor working, install
the Arduino IDE by following the instructions in the section ["Updating
firmware"](#updating-firmware). This will also ensure that you are updated to
the latest BlueGigaEmpeg firmware before trying to debug any problems.

Once the device drivers are working for the Arduino's USB-serial UART, then
the "Serial Monitor" feature built into the Arduino IDE program will work as
the debug console. To run it, do the following:

- Make sure the empeg is powered off or is in sleep mode.

- Connect the USB cable between the computer and the Arduino port (the USB
  "type B" connection which is accessible on the outside of the BlueGigaEmpeg
  casing).

- Launch the Arduino IDE that you installed as part of ["Updating
  firmware"](#updating-firmware).

- Select the "Tools" menu, select "Board" and select "Arduino/Genuino Mega or
  Mega 2560".

- Select the "Tools" menu, select "Processor" and select "ATmega2560
  (mega2560)".

- Select the "Tools" menu, select "Port" and select the correct serial port
  that represents the connected Arduino (this will be different on each
  system and each USB port on the computer).
  
  - If the correct serial port for the Arduino is not in the list, check to
    make sure you have connected the cables in the correct order in relation
    to powering on the devices. See the note about startup order
    [here](#startuporder).

- Select "Tools" then "Serial Monitor", or press the magnifying glass icon
  in the upper right corner of the window. The serial monitor will appear.
  Set it to 115200 BPS and set line endings to "both NL & CR".

- Keep in mind that the BlueGigaEmpeg interface module will reboot (the
  Arduino code will restart) each time you open the serial monitor, and the
  WT32i Bluetooth module will be automatically rebooted at that time.
  
- Apply power to the empeg. You should see the message "empeg player boot
  process has started" appear in the Serial Monitor.
  
- If you disconnect and reconnect the USB cable from the Arduino, you will
  need to close and reopen the Serial Monitor again. If you connect to a
  different USB port on the computer, you will also need to select a
  different port from the "Tools" menu in the Arduino IDE. Also keep in mind
  the required startup order, as described [here](#startuporder).

When connected to this serial terminal interface, everything you type is sent
to the Bluetooth chip as a command, and all of the chip's responses are shown
on your screen. You will also see all commands that the Arduino sends to the
Bluetooth chip automatically, and see all of the chip's responses to them.

You may also type certain specific commands to the serial port to control the
empeg. Type a single character followed by pressing the Enter key. The
following commands are supported:
- "N"   - Next track.
- "P"   - Previous track.
- "C"   - Play (think "continue").
- "W"   - Pause (think "wait").
- "F"   - Begin fast forwarding.
- "B"   - Begin rewinding (think "backwards").
- "A"   - Stop fast forwarding or rewinding (think "abort").
- "%"   - Toggle Shuffle on or off.
- "+"   - Increase the volume of the empeg by one notch.
- "-"   - Decrease the volume of the empeg by one notch.
- "Z"   - Place the BlueGigaEmpeg module into pairing mode for approx. 60 seconds.

####  Power up sequence (startup order) for Arduino debugging:

The BlueGigaEmpeg module can connect to any of these power sources:

- It can obtain power from the tuner module connector on the empeg's docking
  sled wiring harness. This is the default way for it to get its power during
  normal operation.

- It can obtain power from the USB plug, the Arduino USB "type B" port
  accessible on the BlueGigaEmpeg casing. This allows you to upload new
  Arduino firmware to the BlueGigaEmpeg module while it is disconnected from
  the empeg's docking sled.

- Both of the above can be connected at the same time during a debugging
  session, and the BlueGigaEmpeg will get its power from either one.

Because both power sources can be connected at the same time during debugging,
if you are using the USB cable for debugging mode, the sequence order of
connecting the cables and applying power is important.

If you connect the BlueGigaEmpeg to the empeg docking sled and power it up,
and then attach the Arduino USB cable to the computer afterward, then the
Arduino USB port communications with the PC are not initialized (power from
the tuner connector came first) and so the USB connection will not identify
itself to the computer. This causes a problem: The computer cannot find the
Arduino's USB UART and is unable to connect to the debug port.

So, to successfully debug via the Arduino USB debug cable, you must connect
the USB cable to your computer *first*, with the computer on, before applying
power to the empeg (or before waking the empeg from sleep). Meaning, if you
are debugging in the car, you should  connect the USB cable first, and then
turn on the ignition. If you are debugging indoors, connect the USB cable
first, then connect the AC adapter to the empeg.

If you are doing debugging/troubleshooting indoors, it's possible to use the
empeg's 12v AC adapter, connected to the player's AC adapter input. The
BlueGigaEmpeg module works in both AC/Home mode and DC/Car mode. However, a
sled wiring harness is still needed in AC/Home mode, because the BlueGigaEmpeg
still needs the tuner and serial connectors on the harness in order to
function.

####  Sending a bug report:

- Turn on the computer and connect the USB cable from the computer to the
  Arduino debug port (the USB-B connector on the outside of the BlueGigaEmpeg
  casing).

- Run the Arduino Serial Monitor as described above.

- Set the Serial Monitor program to 115200 baud, with line endings set to the
  "Both NL & CR" setting.

- Apply power to the empeg. You should see a debug message appear on the
  serial monitor program's console which says "empeg player boot process has
  started".

- Reproduce the problem, so that the commands and responses show up on the
  monitor's output while the problem is occurring.

- After the problem is reproduced, pause the empeg player from its front
  panel.

- Type the "set" and "list" commands into the serial monitor, pressing the
  Enter key after each one. Their output results should show up on the screen.
  "Set" should show all basic settings of the Bluetooth module, and "list"
  should show the currently-paired device, and which transport channels are
  being used (such as A2DP and/or AVRCP).

- Copy and paste the output of the serial monitor into a text document.

- Submit bug reports this way:
  - Create an account at http://www.GitHub.com if you don't already have one.
  - Search through existing bugs to see if your issue is related to them.
    - Open bugs: https://github.com/tfabris/BlueGigaEmpeg/issues
    - Closed bugs: https://github.com/tfabris/BlueGigaEmpeg/issues?q=is:issue+is:closed
  - If yours is a new issue, then go to https://github.com/tfabris/BlueGigaEmpeg/issues
    and press "New Issue".
  - In the bug report, describe:
    - Model of Bluetooth device. What kind of car stereo do you have?
    - Frequency of the occurrence of the issue, and the conditions under which
      it occurs. Does it happen every time, sometimes, only when it's cold out,
      only in a leap year?
    - Steps to reproduce the issue. Please give as much detail as possible.
    - Expected behavior, versus actual behavior.
    - Things you've already tried doing to diagnose or narrow down the
      problem. For example, do you encounter the same issue when you pair your
      smartphone to your car stereo?
  - Attach your serial monitor output file to the bug report.

- When you are done with the debug session, disconnect the USB cable from the
  computer. It should be left disconnected during normal operation of the
  BlueGigaEmpeg module.
  
####  Variables in the Arduino sketch:

There are some flag variables in the BlueGigaEmpeg.ino sketch file, defined at
the top of the sketch, which can be modified if you need them when debugging.
Change them as you see fit, and re-upload the sketch to the Arduino. See the
["Updating firmware"](#updating-firmware) section for information on uploading
the sketch to the Arduino.

Remember to change flag variables back to their default values when you are
done debugging, as some of them can slow down the responses on the
BlueGigaEmpeg and cause the Bluetooth communication to malfunction
intermittently.

The most common flags you might want to change are these. Search for these
flags in the BlueGigaEmpeg.ino sketch file. Refer to the code comments
accompanying these flags in the file to understand what they do.

      displayEmpegSerial
      displayTracksOnSerial
      logLineByLine
      PerformUtf8Conversion

####  Useful debugging commands in the BlueGiga WT32i iWrap command language:

Typing any of these into the serial monitor should send these commands to the
Bluetooth chip directly. Many will echo a response. The Bluetooth chip will
respond with "SYNTAX ERROR" if there is a problem with any command.

      SET
      Displays Bluetooth module's current settings.

      LIST
      Displays a list of current actively connected devices, including all
      AVRCP and A2DP channel details.

      SET BT PAIR
      Displays Bluetooth module's current list of paired devices.

      SET BT PAIR *
      Deletes all saved Bluetooth pairings on the Bluetooth module. The
      asterisk is important, it's the part that does the deleting.

      SET CONTROL RECONNECT *
      Turns off automatic reconnection attempts on the Bluetooth module until
      the next time it pairs up with something.

      RESET
      Reboots the Bluetooth module, saving current settings. Does not erase
      any existing saved Bluetooth pairings nor change any settings.

      SET RESET
      Resets the Bluetooth chip itself to its factory defaults. Does not
      remove existing pairings, those are still kept. Note: you should restart
      the Arduino after using "SET RESET" in order to have it apply its
      customized default settings to the Bluetooth chip again.

See the iWrap 6.x command reference and the AVRCP command reference documents,
linked in the ["Resources"](#resources) section, for more details on the
incredibly rich and complex command language of this Bluetooth chip.

A note about response ordering in the debug console:

Sometimes the responses from the Bluetooth module do not show up on the screen
immediately, because the main input loop in the Arduino sketch might not have
caught up and read all the responses from the serial port yet. So, for
example, a bad command might be issued several lines back, but the "SYNTAX
ERROR" response doesn't appear until later. So don't assume that any
command/response pair will always appear together on the debug console screen.

Updating firmware
==============================================================================
Instructions for updating the firmware on the BlueGigaEmpeg module.

- [Modify your Arduino compiler for larger buffer size                             ](#modify-your-arduino-compiler-for-larger-buffer-size)
- [Compile and upload the latest version of BlueGigaEmpeg.ino to the Arduino       ](#compile-and-upload-the-latest-version-of-bluegigaempegino-to-the-arduino)

Modify your Arduino compiler for larger buffer size
------------------------------------------------------------------------------
The firmware on the BlueGigaEmpeg module resides in an Arduino chip which is
part of the BlueGigaEmpeg assembly. To update to the latest BlueGigaEmpeg
firmware on the Arduino, you will be uploading the sketch to the Arduino
("sketch" is the name for an Arduino program).

But there is a modification that you must perform first: You must increase the
default size of the Arduino serial port buffers. This can only be done by
modifying the compiler's files directly. If this isn't done, then after you
upload new firmware to the Arduino, there will be intermittent errors in the
BlueGigaEmpeg operation, such as commands sometimes being missed and track
titles sometimes not working or being incomplete.

#### Download and install the compiler:

Download the Arduino IDE, linked from the [Prerequisites](#prerequisites)
section of this document. Make sure to download and install the standalone
version of the Arduino IDE; do not try to use the Arduino web editor. Though
the web editor is convenient, it won't work for this project because it
doesn't have the capability of changing the header files to increase the size
of the serial port buffers.

Install the Arduino IDE. It will be a different installation procedure for
different operating systems.

#### Edit compiler file to increase serial port buffer size:

Once it is installed, you'll need to edit one of the compiler's files to
increase the size of the Arduino's serial port buffers. The file that you need
to edit will be the same on all operating systems, but the location of the
file will be different depending on which OS you're using. The location will
also be affected by whether or not you're using an update to the Arduino's
"Boards" files, or if your Arduino IDE is a stock installation without any
Boards updates.

#### Locate the correct file to edit:

We're looking for a file called "HardwareSerial.h", but there may be more than
one copy of the file on your hard disk, and it's hard to tell which one that
the Arduino compiler is going to use. The quickest way to reliably find the
right file is to get a certain example document opened, fish up the directory
tree to find the right parent folder, and then fish down again to find the
right subfolder. This procedure looks a little crazy, but it works.

- Run the Arduino IDE program that you just installed.

- Select the "Tools" menu, select "Board" and select "Arduino/Genuino Mega or
  Mega 2560".

- With the correct board configured, select the menus "File", "Examples",
  "SPI", "BarometricPressureSensor". At this point an example document will
  open.

- With the "BarometricPressureSensor" example document window
  selected/focused, select the menu items "Sketch", "Show Sketch Folder". A
  folder window will open. This folder will be slightly different on various
  systems and installation types. Examples of places it might be (version
  numbers and parent folders may vary):

     ```
     C:\Program Files\Arduino\hardware\arduino\avr\libraries\SPI\examples\BarometricPressureSensor
     or 
     Macintosh HD/Applications/Arduino.app/Contents/Java/hardware/arduino/avr/libraries/SPI/examples/BarometricPressureSensor
     or
     Macintosh HD/Users/(your username)/Library/Arduino15/packages/arduino/hardware/avr/1.6.21/libraries/SPI/examples/BarometricPressureSensor
     etc.
     ```

- Fish up the directory tree from that location until you find a file called
  "boards.txt", most likely it will be in the either the "avr" folder a few
  levels up from the "BarometricPressureSensor" example document, or perhaps
  in a version-numbered folder if you have installed a "Boards" update for
  the Arduino compiler. For instance, you might find it in:

     ```
     C:\Program Files\Arduino\hardware\arduino\avr\boards.txt
     or
     Macintosh HD/Applications/Arduino.app/Contents/Java/hardware/arduino/avr/boards.txt
     or
     Macintosh HD/Users/(your username)/Library/Arduino15/packages/arduino/hardware/avr/1.6.21/boards.txt
     etc.
     ```

- The folder that contains "boards.txt" will also have a subfolder beneath
  it called "cores". Open that folder.

- The "cores" folder will have an "arduino" subfolder beneath it. Open that.

- You will locate the desired HardwareSerial.h file there. The final location
  of the desired file will be something like the following, but the parent
  folder names and version numbers may differ:

     ```
     C:\Program Files\Arduino\hardware\arduino\avr\cores\arduino\HardwareSerial.h
     or
     Macintosh HD/Applications/Arduino.app/Contents/Java/hardware/arduino/avr/cores/arduino/HardwareSerial.h
     or
     Macintosh HD/Users/(your username)/Library/Arduino15/packages/arduino/hardware/avr/1.6.21/cores/arduino/HardwareSerial.h
     etc.
     ```

- You have now located the correct "HardwareSerial.h" file to edit.

- Close the "BarometricPressureSensor" example document window, but leave
  the folder window open with the correct "HardwareSerial.h" file in it.

#### Perform the edit:

Open the "HardwareSerial.h" file in your favorite quick text editor program.
Once you have it open, locate the following code lines:

             #if !defined(SERIAL_TX_BUFFER_SIZE)
             #if ((RAMEND - RAMSTART) < 1023)
             #define SERIAL_TX_BUFFER_SIZE 16
             #else
    -->      #define SERIAL_TX_BUFFER_SIZE 64
             #endif
             #endif
             #if !defined(SERIAL_RX_BUFFER_SIZE)
             #if ((RAMEND - RAMSTART) < 1023)
             #define SERIAL_RX_BUFFER_SIZE 16
             #else
    -->      #define SERIAL_RX_BUFFER_SIZE 64
             #endif
             #endif

Now edit the "64" lines indicated above, and change the "64's" to these new
numbers instead:

       #define SERIAL_TX_BUFFER_SIZE 128
       
       #define SERIAL_RX_BUFFER_SIZE 256

In other words, you are making the larger of the two possible transmit buffer
sizes even larger (changing 64 to 128) and the larger of the two possible
receive buffers even larger (changing 64 to 256).

Leave the "SERIAL_xx_BUFFER_SIZE 16" lines alone. Only modify the ones that
were originally set to "64" and increase them as described above.

Save the file.

Note: If you reinstall or upgrade the Arduino IDE program, or if the Arduino
prompts you to update your "Boards", you will need to re-locate the correct
file again, and perform this edit again, before uploading a new version of the
BlueGigaEmpeg sketch to the Arduino.

Compile and upload the latest version of BlueGigaEmpeg.ino to the Arduino
------------------------------------------------------------------------------
Obtain the BlueGigaEmpeg.ino Arduino project file from GitHub, linked in the
[Prerequisites](#prerequisites) section of this document. In the GitHub
project web site for BlueGigaEmpeg, find the button titled "Clone or download"
and obtain the repository. Most people will select "Download Zip" to download
the zip file, though if you are a Git user, feel free to clone the repository
or select "Open in Desktop". If you are downloading the zip file, unzip the
entire project into a folder named "BlueGigaEmpeg" on your computer's hard
disk. This will likely require renaming the folder to "BlueGigaEmpeg" after
unzipping the file.

####  Important:

The folder in which the BlueGigaEmpeg.ino file resides must be named
"BlueGigaEmpeg" and not, for example, "BlueGigaEmpeg-Master", because the
Arduino IDE won't recognize it as an Arduino project file unless the parent
folder name is the same as the ".ino" file name. If you're synchronizing with
the BlueGigaEmpeg repository on GitHub via the "Git" tool, then the folder
will automatically be named correctly, but if you are downloading and unzipping
the zip file, you will likely have to rename the folder after unzipping it.

####  Connection order special instructions:

The Arduino is located inside the enclosure of the BlueGigaEmpeg module, and
you upload the sketch to it ("sketch" is the name for an Arduino program) via
the USB connector on the end of the BlueGigaEmpeg casing. Uploading the sketch
to the Arduino may be done with the BlueGigaEmpeg module disconnected from the
empeg Car. No external power source is required in this case, the Arduino gets
its power from the computer via the USB cable in this situation. When
connecting the Arduino to the computer via the USB cable, if that's the only
connection, then no special connection order is needed.

In some cases, though, you may also want to upload the sketch to the Arduino
while the BlueGigaEmpeg module is connected to the empeg Car. This is possible
to do, however, special connection instructions are needed if you do this:

- Do not connect the BlueGigaEmpeg module to the empeg Car until after
  completing the step in this document titled ["Modify empeg Car interior for
  I2S digital audio connection"](#i2s). Damage may occur if you connect it
  before making the modification.
  
- The computer will not "see" the USB connection to the Arduino if it receives
  power from the empeg first. So before connecting the USB cable between the
  computer and the Arduino, make sure that the empeg is not powered up, or that
  it is in sleep mode, or it is not connected to the BlueGigaEmpeg module. See
  [here](#startuporder) for more details about this.

####  Upload the sketch:

Connect the USB cable from the computer to the Arduino USB connector. The
Arduino USB connector is the USB "type B" plug which is exposed on the end of
the BlueGigaEmpeg enclosure.

When first plugging the Arduino into the computer, it may need to install
device driver files for the USB/serial connection to the Arduino. In theory,
the installer for the Arduino IDE should have taken care of installing these
drivers for you. If not, search for help documents online about getting
drivers for the "Arduino Mega 2560" chip working.

Once the device drivers are installed and working, do the following:

- Launch the Arduino IDE that you installed earlier.

- Select the "Tools" menu, select "Board" and select "Arduino/Genuino Mega or
  Mega 2560".

- Select the "Tools" menu, select "Processor" and select "ATmega2560
  (mega2560)".

- Select the "Tools" menu, select "Port" and select the correct serial port
  that represents the connected Arduino (this will be different on each
  system and each USB port on the computer).

- Select "Tools" then "Serial Monitor", or press the magnifying glass icon
  in the upper right corner of the window. The serial monitor will appear.
  Set it to 115200 BPS and set line endings to "both NL & CR".

You should see some serial port output from the Arduino. If you don't already
see this, try closing and re-opening the Serial Monitor.

If the Serial Monitor is working, then you are ready to compile and upload the
sketch to the Arduino Mega board. Do the following:

- Select "File", "Open" and open the BlueGigaEmpeg.ino project file in the
  folder that you obtained and unzipped earlier.

- Compile and upload it by selecting "Sketch", "Upload", or by pressing the
  Upload button in the main window. the Upload button is the green circle
  with the arrow inside it.

- It will take several seconds to upload.

- Look at the Arduino IDE and make sure that there is no red text or other
  error messages near the bottom of the window which would indicate a problem
  compiling or uploading the sketch. If it is good, there will be a very small
  piece of text on the IDE, on the green bar between the code pane (top) and
  the console pane (bottom), saying "done uploading".

- After the latest version of the BlueGigaEmpeg.ino sketch is successfully
  uploaded to the Arduino, look at the output in the Serial Monitor again.
  The top section of the output should list the RX and TX buffer sizes near
  the beginning, and indicate that they are good. An error message will
  appear if the serial port buffer sizes are not good.

Close the Arduino IDE and disconnect the USB cable from the computer. The USB
cable should be left disconnected from the computer during normal operation of
the BlueGigaEmpeg module. It is safe to leave a USB cable attached to the
BlueGigaEmpeg module as long as you don't have the other end always hooked up
to a computer. For example, if the BlueGigaEmpeg module is permanently mounted
in a hard-to-reach place in your car, you should leave a USB cable attached to
it which extends to a reachable location. This will make future firmware
updates and debugging easier by bringing a laptop computer into your car.

Technical Data
==============================================================================
All sections below are for developer reference, and should not be needed by
end-users of the BlueGigaEmpeg module unless performing repairs or other
maintenance.

- [Bluetooth Chip Firmware Upgrade                                                 ](#bluetooth-chip-firmware-upgrade)
- [Set jumpers and switches                                                        ](#set-jumpers-and-switches)
- [Low Latency Codec (APT-X LL) information                                        ](#low-latency-codec-apt-x-ll-information)
- [Hardware interface information and notes (internal board connections)           ](#hardware-interface-information-and-notes-internal-board-connections)
- [Resources                                                                       ](#resources)
- [Test, packing, and shipment checklist                                           ](#test-packing-and-shipment-checklist)

Bluetooth Chip Firmware Upgrade
------------------------------------------------------------------------------
Note: This is only for developer reference. This should only be needed if you
are getting a replacement board directly from BetzTechnik, or you are
performing some type of maintenance or debugging.

The firmware upgrade is done with a USB-A-to-micro-USB cable.

Steps:

 - Make sure the Bluetooth breakout board is fully separated and disconnected
   from the BlueGigaEmpeg board.

 - Make sure that jumper JP4 on the BetzTechnik WT32i Bluetooth board is
   connected. It comes connected by default, but it may have been cut after
   upgrading the firmware. All units built up until May 2019 had the jumper
   cut. In any case, the jumper needs to be connected any time you do firmware
   updates to the WT32i chip.

 - The firmware upgrade must be performed from a Windows computer, since the
   upgrading software is Windows software. Virtualized Windows works, too, for
   example, I was successful with doing this in Parallels on a Mac computer.

 - Download and unzip the "iWRAP-Firmware-Releases.zip" file linked in the
   [Resources](#resources) section of this document.

 - Connect your Windows computer to the Bluetooth device via a USB micro cable
   connected to the "UART" port on the BetzTechnik WT32i breakout board. (If
   you are running a Windows VM, you may need to assign this device to the
   USB of the virtual machine. For example, if running Parallels on Mac, it
   will prompt you to do so when you plug it in while Parallels is running.)

 - The red LED on the BetzTechnik board will dimly pulse, indicating that the
   chip is asleep. Move the power switch on the BetzTechnik board into the
   "on/up" position in order to turn on the board and make the LED blink
   brightly and randomly.

 - Run Windows Device Manager. This can be found in the Windows control panel,
   by searching from the Start menu, or by running the program "DEVMGMT.MSC".

-  Look in Windows Device Manager to see if the USB connection has made a new
   serial port appear as a device under the heading "Ports (COM & LPT)".

 - If there is no new serial port there, look for a little yellow boo boo icon
   in the USB section instead. If there is a little yellow boo boo icon
   instead of a serial port, then you must install the necessary FTDI drivers
   for the USB-serial connection to the board. Links to these drivers are in
   the [Resources](#resources) section of this document.

 - Now, plugging in the Bluetooth breakout board into the PC with the USB
   micro cable makes a serial port appear in the Windows Device Manager.

 - In Windows Device Manager, right click on the serial port and select
   "Properties". Set the speed of the serial port to 115200 bps with 8 data
   bits, no parity, 1 stop bit, no flow control (aka "8N1").

 - Once that's sorted, run the "SerialDFU.exe" tool found in one of the
   folders of the unzipped "iWRAP-Firmware-Releases.zip" file. In the folder
   of unzipped files, the full path is:
   
       iWRAP_Firmware_Releases
         Firmware
          DFU
           SerialDFU
            SerialDFU.exe

 - Note: The serial port settings in the SerialDFU tool will show "8E1" for
   its BCSP settings instead of "8N1". There will be two sets of serial port
   settings on the screen. The first one will say "8E1" and the second one
   will say "8N1". This is OK and must remain that way for the upgrade
   process to work. 

 - Make sure the "Get Device Type" button works, and shows your device
   information for your WT32i chip. It will say it is a "WT32i-A" chip and
   give its Bluetooth address.

 - Select the options to upgrade your chip with the most recent WT32i file
   among the unzipped files. Do this by pressing the "Browse" button on the
   "Select DFU file" field and browsing to the correct ".dfu" file found here:
   
       iWRAP_Firmware_Releases
         Firmware
          DFU
           SerialDFU     (SerialDFU.exe is the upgrader tool in this folder)
            DFU_Images
              WT32i
                ai-6.2.0-1122_aptxll.bc5.dfu        (firmware file)

 - Note: When upgrading, there is a checkbox on the screen in the
   SerialDFU.exe utility which says "Factory Restore All". Make sure to CHECK
   that checkbox when doing the firmware upgrade.

 - Make sure the upgrade completes successfully (a message box should say so).

 - After the upgrade is successful, unplug the USB cable from the board and
   computer, and close the Serial DFU Tool software.

 - Make sure to set the power switch on the BetzTechnik board to the down/off
   position, as described in the next step.

Set jumpers and switches
------------------------------------------------------------------------------
Note: This is only for developer reference. This is only needed if you have
received a replacement board from BetzTechnik or you are doing other
maintenance work.

On the BlueGigaEmpeg PCB:

Set the jumpers to "Crossover" position as shown on the silkscreen printing
on the board.

On the BetzTechnik WT32i Breakout board:

Set the power switch "U5" on the BetzTechnik board to the "down" position
(looking at the board so that the board's large silkscreen name is readable)
which is the "off" position for this switch. 

Low Latency Codec (APT-X LL) information
------------------------------------------------------------------------------
I have abandoned attempts to get the WT32i chip working with a low-latency
codec (APT-X LL) because:

- The APT-X LL codec is not supported by my Honda, so I don't have a good
  testbed for it.

- I wasn't able to get a clear answer from Silicon Labs as to exactly how
  to purchase the extra licenses for the APT-X LL codec.

- The process of installing the third party license for the APT-X LL codec
  onto the Bluetooth chip is onerous, requires a specialized piece of chip
  programming hardware, and some non-user-friendly software tools. I was
  able to get a developer test license working on one of my chips (this is
  how I know), but it took way too much work, and when it was done, there
  was no benefit.

- There is not widespread support for the APT-X LL codec on all car
  stereos, so it would be of no benefit to most users. It's also not always
  clear which stereos support APT-X LL and which ones do not, so you might
  not even be able to tell if it will be worth going to all that trouble.
  You might complete the work, only to discover that the codec isn't
  supported by your stereo.

I have made extensive notes on the specialized hardware and software, and the
required programming steps, needed to install APT-X LL, and I can discuss
this with anyone who needs this information.

Hardware interface information and notes (internal board connections)
------------------------------------------------------------------------------
The BlueGigaEmpeg interface board from Pad2Pad implements everything described
below. The information below is for developer reference only, and you should
not need to do any of the connections below yourself, unless you are
developing your own interface board.

Arduino must be the "Mega" model with three hardware serial ports built in. I
tried it with an "Uno" model using software serial ports, and it had problems
where characters sometimes got dropped, and it could not keep up with the data
rates that I wanted.

####  Links to Schematics and CAD files:

- [BlueGigaEmpeg PCB Schematic                                                  ](https://github.com/tfabris/BlueGigaEmpeg/blob/master/BlueGigaEmpeg%20Schematic.pdf)
- [BlueGigaEmpeg PCB CAD file (Pad2Pad)                                         ](https://github.com/tfabris/BlueGigaEmpeg/blob/master/BlueGigaEmpeg%20-%20Rev%207%20-%20PII%20Cleaned.pcb)
- [BlueGigaEmpeg Enclosure CAD file (Blender)                                   ](https://github.com/tfabris/BlueGigaEmpeg/blob/master/BlueGigaEmpeg%20Enclosure%2030%20-%20Version%2002%20exportable.blend)
- [BlueGigaEmpeg Enclosure CAD file (STL for Shapeways)                         ](https://github.com/tfabris/BlueGigaEmpeg/blob/master/BlueGigaEmpeg%20Enclosure%20-%20Version%2002.stl)
- [Arduino Mega 2650 Breakout Board Schematic                                   ](https://github.com/tfabris/BlueGigaEmpeg/blob/master/Arduino%20Mega%202560%20Breakout%20Board%20Schematic.pdf)
- [BetzTechnik WT32i Breakout Board Schematic                                   ](https://github.com/tfabris/BlueGigaEmpeg/blob/master/BetzTechnik%20WT32i%20Breakout%20Board%20Schematic.pdf)

####  Arduino and RS-232 port, critical connections:

Arduino serial port 1 (Tx1/Rx1) connects to the empeg's RS-232 port, but it
must go through an RS-232 converter circuit based on a MAX232 chip. This is
necessary because you can't connect an actual RS-232 cable directly to an
Arduino, the voltage and signaling are different. So it must go through the
MAX232.

The RX/TX crossover configurations for the MAX232 and the RS-232 plug on the
BlueGigaEmpeg can be confusing. The empeg Car sled serial port may or may not
be already wired into a crossover configuration. I have seen both cases. There
are jumpers on the BlueGigaEmpeg PCB to swap the RX/TX configuration to the
serial port as needed. Default shipping configuration is "Crossed" to
compensate for a straight connection coming out of the sled.

I am using a TI MAX232E for this implementation. The connections for the
MAX232 are as follows:

    MAX232 Pin 1 and 3 aka C1+/C1- - Bridge with a 2.2uf ceramic capacitor
    MAX232 Pin 4 and 5 aka C2+/C2- - Bridge with a 2.2uf ceramic capacitor
    MAX232 Pin 2 aka V+ - Connect to Arduino +5v via a 2.2uf ceramic capacitor
    MAX232 Pin 6 aka V- - Connect to GND via a 2.2uf ceramic capacitor
    MAX232 Pin 11 aka TTL-I1 - Connect to Arduino Mega Board 18 aka Tx1 
    MAX232 Pin 12 aka TTL-O1 - Connect to Arduino Mega Board 19 axa Rx1
    MAX232 Pin 13 aka 232-I1 - Connect to RS-232 plug pin 3 aka Tx via jumpers
    MAX232 Pin 14 aka 232-O1 - Connect to RS-232 plug pin 2 aka Rx via jumpers
    MAX232 Pin 15 aka GND - Connect directly to GND
    MAX232 Pin 16 aka VCC - Connect directly Arduino +5v output.
    MAX232 Pin 16 aka VCC - Also connect to 0.1uf ceramic capacitor which
                            then connects to GND. (Pin 16 is two connections,
                            one to Arduino +5v and then also to the smoothing
                            capacitor which bridges across 5v and GND. Place
                            this cap as close to pin 16 as possible.)
    Note:
    
    The illustration below has some jumpers between pins on the RS232 plug.
    For example, it shows pin 6 jumpered to pin 4, and pin 7 jumpered to pin
    8. Do not implement those particular jumpers, leave those pins
    disconnected.
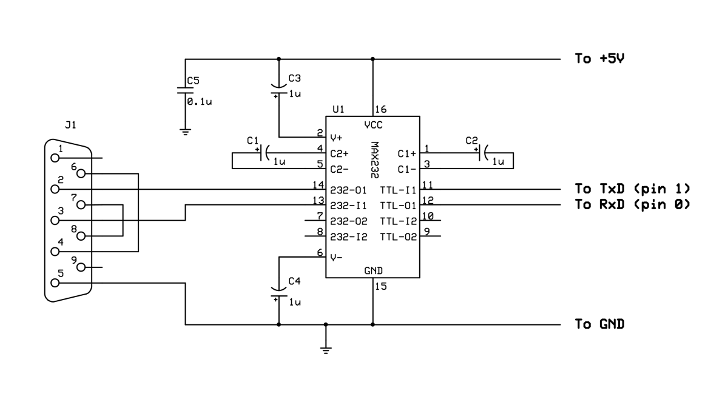
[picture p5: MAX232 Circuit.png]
MAX232 Circuit


The empeg tuner connector is used to supply power to the Pololu step-down
transformer power supply, and from there, on to the rest of the assembly. Blue
wire on tuner connector connects to the voltage input pin on Pololu, and the
black wire on the tuner connector connects to the Pololu ground input pin.

Arduino "Vin" pin is connected to the 7.5v output rail from the Pololu
step-down transformer power supply circuit.

Grounding: Multiple Arduino GND pins connected to the output ground rail of
the Pololu power supply.

Arduino and Button: Arduino pin 52 digital I/O pin, connected to one of the
ground legs of button. This same line (or the other ground leg of the button)
also goes through a 10k pulldown resistor to ground. One of the + legs of the
button connects to +5v coming from the Arduino 5v pin. Follow examples on the
Internet of how to implement a simple temporary pushbutton on an Arduino:
https://www.arduino.cc/en/Tutorial/Button

Note: The BlueGigaEmpeg printed circuit board, Rev. 6, has the position of the
10k button resistor labeled on the wrong side of the PCB. It will work on
either side, but I discovered after manufacturing the Rev. 6 boards that there
is better clearance from the Arduino components if you move it to the other
side of the board. Rev. 7, not yet manufactured at the time of this writing,
has it corrected in the CAD file already.

Arduino and Pair mode indicator LED: Arduino pin 50 digital I/O pin, connected
to +LED through a resistor. Then, -LED connect to GND. The value of the
resistor is determined by an online LED resistor calculator and the LED spec
values. Example: If using a blue LED with a 3.2v forward voltage and 20ma
current, and the Arduino analog power supply from the analog pins will be 5
volts, then use a 100 ohm resistor for this value. An online LED resistor
calculator can be found here: http://led.linear1.org/1led.wiz

LED soldering height: To fit into the hole in the casing well, the top of the
diode assembly itself inside the LED lens (the metal part) should top out at
the same height as the top of the button plastic. Lens will protrude higher
than the button by vaguely 2mm or so.

LED anode: The positive/anode pin is the long lead. The positive pin is the
side with the smaller metal bit visible inside the lens. The positive/anode
pin goes into the hole on the PCB with the round pad. The negative/cathode pin
goes into the hole on the PCB with the square pad. The triangle/bar symbol on
the PCB silkscreen is this:

       positive  >|  negative

####  BlueGiga Bluetooth WT32i chip+board, critical connections:

BetzTechnik Bluetooth chip+board "Smd_2_pole_switch" or "U5" switch is set to 
the "off" position.

Bluetooth chip+board "5v" power pin NOT connected to anything.

Bluetooth chip+board "3v3" or "VDD_IO" pin connected to the 3v output coming
from the Arduino.

Bluetooth chip+board "ENA" or "VREG_ENA" pin connected to the 3v output coming
from the Arduino.

Bluetooth chip+board "BATT" pin connected to the 3v output coming from the
Arduino.

Bluetooth chip+Board "Gnd" pin connected to the ground rail.

Bluetooth chip+board serial port "RX/TX" pins connected to the "TX2/RX2" pins
(serial port 2) of Arduino. Note: This is a crossover connection, i.e., RX
from the Arduino is connected to TX on the Bluetooth chip and vice-versa.
Since this is at TTL level, you don't need to go through a MAX232 circuit.
However, the Arduino is running at 5v TTL, and the BlueGiga chip runs at 3.3v.
So you must voltage match them. Decrease the voltage for the Arduino TX2
output, by running it through a simple 50% voltage divider to step 5v TTL from
Arduino down to 2.5v for the BlueGiga chip. The BlueGiga chip's transmit pin
can stay at 3.3v and the Arduino will still read it just fine, so no changes
are needed for that line. Schematic:

    ARDUINO TX2-----VVVVV----+----VVVVV-----GND
                   10Kohm    |    10Kohm
                             |
                             +--------------WT32i Rx

    ARDUINO RX2-----------------------------WT32i Tx

Bluetooth chip+Board three I2S pins PCM_CLK, PCM_SYNC, PCM_IN connected to
empeg IISC, IISW, IISD1 via a special modification to the empeg tuner module
connector, as described in the section of this document titled ["Modify empeg
Car interior for I2S digital audio connection"](#i2s).

Each one of the three I2S lines will need to be reduced from 5v to 2.5v, to
prevent frying the WT32i chip (I fried two chips this way until we figured
this out). The I2S lines need to come in through a set of resistors arranged
in a 50% voltage divider configuration, two 1.5k resistors for each one of the
three lines. 1.5k is used instead of 10k to improve the S/N ratio on the I2S
lines at the expense of more current draw from the SA7705H DSP chip on the
empeg Car. This fixes GitHub issue #69. Example of one line (repeat a total of
three times, one for each of the I2S connections):

    EMPEG IISC-----VVVVV----+----VVVVV-----GND
                  1.5Kohm   |   1.5Kohm                    (3x) 
                            |
                            +--------------WT32i PCM_CLK

Note: The BlueGigaEmpeg printed circuit board, Rev. 6, still has the old 10k
value for the I2S voltage divider resistors silkscreened onto the board. The
correct value for the I2S voltage divider resistors is 1.5k. Also, these are
silkscreened onto the wrong side of the board. Theoretically they should work
on either side of the board, but if you put them on the opposite side, then
there's more clearance from the Arduino. Rev. 7, not yet manufactured at the
time of this writing, has them corrected in the CAD file already.

Resources
------------------------------------------------------------------------------
####  Purchase:
| Item | Url |
|:---|:---|
| Empeg Car player | http://empegbbs.com/ubbthreads.php/forums/11/1/For_Sale |
| Arduino MEGA 2560 R3 Board | https://www.amazon.com/gp/product/B01H4ZLZLQ |
| BetzTechnik WT32i Breakout | http://www.betztechnik.ca/store/p3/WT32i_breakout_board.html |
| BlueGigaEmpeg Interface PCB (Pad2Pad) | https://github.com/tfabris/BlueGigaEmpeg/blob/master/BlueGigaEmpeg%20-%20Rev%207%20-%20PII%20Cleaned.pcb |
| BlueGigaEmpeg Enclosure (Shapeways) | https://github.com/tfabris/BlueGigaEmpeg/blob/master/BlueGigaEmpeg%20Enclosure%20-%20Version%2002.stl |

####  Download software:
| Item | Url |
|:---|:---|
| Arduino IDE | https://www.arduino.cc/en/Main/Software |
| BlueGigaEmpeg sketch | https://github.com/tfabris/BlueGigaEmpeg |
| Hijack Kernel for empeg | http://empeg-hijack.sourceforge.net/ |
| Tony's Empeg Logo Editor | http://empegbbs.com/ubbthreads.php/ubb/download/Number/7067/filename/logoedit17.zip |
| WT32i iWrap Firmware Upgrade | https://www.silabs.com/documents/login/software/iWRAP-Firmware-Releases.zip |
| FTDI USB driver | http://www.ftdichip.com/FTDrivers.htm |

####  Bluetooth information, schematics, and command references:
| Item | Url |
|:---|:---|
| iWrap Commands | https://www.silabs.com/documents/login/reference-manuals/iWRAP6-API-RM.pdf |
| iWrap AVRCP Commands | https://www.silabs.com/documents/login/application-notes/AN986.pdf |
| Dev Board User Guide | https://www.silabs.com/documents/login/user-guides/UG215.pdf |
| Dev Board Data Sheet | https://www.silabs.com/documents/login/data-sheets/WT32i-DataSheet.pdf |
| Dev Board Reference Design  | https://www.silabs.com/documents/login/reference-designs/Reference-Design-DKWT32i.pdf |
| Dev Board Full Schematic | https://www.silabs.com/documents/login/reference-designs/DKWT32i-v2.2.zip |
| Bluetooth A2DP specs | https://www.bluetooth.org/docman/handlers/downloaddoc.ashx?doc_id=8236 |
| Bluetooth AVRCP specs | https://www.bluetooth.org/docman/handlers/DownloadDoc.ashx?doc_id=292286 |
| BetzTechnik Schematic | http://www.betztechnik.ca/uploads/2/5/6/7/25674051/wt32i.pdf |
| Pololu V.Reg #2853 Pinout | https://a.pololu-files.com/picture/0J5779.1200.jpg |
| Arduino Mega Pin Map | https://www.arduino.cc/en/uploads/Hacking/Atmega168PinMap2.png |
| Arduino Mega Standalone | https://www.arduino.cc/en/Main/Standalone |
| ClassOfDevice generators | http://bluetooth-pentest.narod.ru/software/bluetooth_class_of_device-service_generator.html  |
| | http://www.ampedrftech.com/cod.htm |
| MAX232 circuit for Arduino  | https://github.com/tfabris/BlueGigaEmpeg/blob/master/MAX232%20Circuit.png |
| TI MAX232E datasheet | http://www.ti.com/lit/ds/symlink/max232e.pdf |
| BlueGiga Forum | https://www.silabs.com/community/wireless/bluetooth |
| Empeg BBS thread | http://empegbbs.com/ubbthreads.php/topics/370217/1 |
| Designing low noise PCBs | http://www.ti.com/lit/an/szza009/szza009.pdf |

####  Upgrade firmware on the WT32i:
| Item | Url |
|:---|:---|
| Firmware Update Guide | https://www.silabs.com/documents/login/user-guides/UG216.pdf |
| Page containing firmware | https://www.silabs.com/documents/login/data-sheets/WT32i-DataSheet.pdf |
| Link to firmware zip file | https://www.silabs.com/documents/login/software/iWRAP-Firmware-Releases.zip |
| Prolific PL2303 USB driver  | http://www.prolific.com.tw/US/ShowProduct.aspx?p_id=225&pcid=41 |
| FTDI USB driver | http://www.ftdichip.com/FTDrivers.htm |

####  Parts list used in BlueGigaEmpeg interface board:
| Item | Qty | Url |
|:---|:---|:---|
| BlueGigaEmpeg PCB (Pad2Pad) | | https://github.com/tfabris/BlueGigaEmpeg/blob/master/BlueGigaEmpeg%20-%20Rev%207%20-%20PII%20Cleaned.pcb |
| Pololu 7.5v V.Reg #2853 | | https://www.pololu.com/product/2853 |
| TI MAX232E | | https://www.digikey.com/product-detail/en/texas-instruments/MAX232EIN/296-27963-5-ND/1511027 |
| RS-232 connector | | https://www.digikey.com/product-detail/en/assmann-wsw-components/A-DS-09-A-KG-T2S/AE10968-ND/1241804 |
| Molex tuner connector | | https://www.digikey.com/product-detail/en/molex-llc/0039295083/WM3923-ND/356037 |
| Molex connector screws | Qty:2 | https://www.digikey.com/product-detail/en/b-f-fastener-supply/MPMS-003-0008-PH/H743-ND/274954 |
| M3 hex bolts (for case) | Qty:4 | https://www.amazon.com/gp/product/B00SN36C6M |
| LED | | https://www.digikey.com/product-detail/en/cree-inc/C503B-BCN-CV0Z0461/C503B-BCN-CV0Z0461-ND/1922945 |
| Reset button | | https://www.digikey.com/product-detail/en/e-switch/TL1105LF250Q/EG2506-ND/378972 |
| Jumpers 0.10 pitch | Qty:2 | https://www.digikey.com/product-detail/en/te-connectivity-amp-connectors/2-382811-0/2-382811-0-ND/1864296 |
| Male conn. headers, 3x2 | | https://www.digikey.com/product-detail/en/molex-llc/0010897060/WM9874-ND/3068084 |
| Male conn. headers, 18x2 | | https://www.digikey.com/product-detail/en/3m/961236-6404-AR/3M9466-36-ND/2071927 |
| Male conn. headers, 22x1 | Qty:2 | https://www.digikey.com/product-detail/en/3m/961122-6404-AR/3M9457-22-ND/2071905 |
| Male conn. headers, 10x1 | | https://www.digikey.com/product-detail/en/3m/961110-6404-AR/3M9457-10-ND/2071896 |
| Male conn. headers, 8x1 | Qty:2 | https://www.digikey.com/product-detail/en/3m/961108-6404-AR/3M9457-08-ND/7104637 |
| Fem. conn. headers  22x1 | Qty:2 | https://www.digikey.com/product-detail/en/3m/929850-01-22-RA/929850E-01-22-ND/1094203 |
| 2.2uf Ceramic Capacitors | Qty:4 | https://www.digikey.com/product-detail/en/murata-electronics-north-america/RCER71H225K2K1H03B/490-11889-ND/4277808 |
| 0.1uf Ceramic Capacitor | | https://www.amazon.com/gp/product/B071VVTC7Z/ref=oh_aui_detailpage_o04_s00 |
| 1.5k ohm resistors | Qty:6 | https://www.amazon.com/gp/product/B077FMSR86/ref=oh_aui_detailpage_o00_s00 |
| 10k ohm resistors | Qty:3 | https://www.amazon.com/gp/product/B0185FIOTA/ref=oh_aui_detailpage_o02_s00 |
| 100 ohm resistor | | https://www.digikey.com/product-detail/en/stackpole-electronics-inc/CF18JT100R/CF18JT100RCT-ND/2022718 |
| Jumper Wires 9.5 inches | Qty:3 | (lying around) |
| 3M Command Strips (hold down Vreg) | Qty:1 | (lying around) |

Test, packing, and shipment checklist
------------------------------------------------------------------------------
The following things are verified before packing and shipping a BlueGigaEmpeg:

- BetzTechnik board upgraded to version 6.2.0 build 1122.
- BetzTechnik board power switch is in the down/off position.
- Jumpers on BlueGigaEmpeg board are set to the "crossover" configuration.
- Arduino contains current version of Github code, check version at bootup.
- Arduino displays good serial buffers, check messages at bootup.
- WT32i reports version "(6.2.0 build 1122)" when booted.
- Powering up empeg displays a message on debug console (empeg messages work).
- Pairing button and LED works, pairing mode pairs with the playback device.
- Play/pause works on Bluetooth playback device (AVRCP+empeg commands work).
- Audio playback quality is good.
- Touch-check for no hot components after playing music for a few minutes.
- LED is straight.
- Place assembly into enclosure, make sure fit is perfect, LED is in the hole.
- Make sure pair button works with the enclosure closed up.
- Screw in the enclosure bolts slowly, and in three stages, to prevent heat stripping.
- Can remove and reinsert enclosure bolts without stripping the plastic.
- Box includes baggie with USB cable, jumper wires, stickers, shrink tubing.
- Printout of one-pager instruction sheet is included in the box.

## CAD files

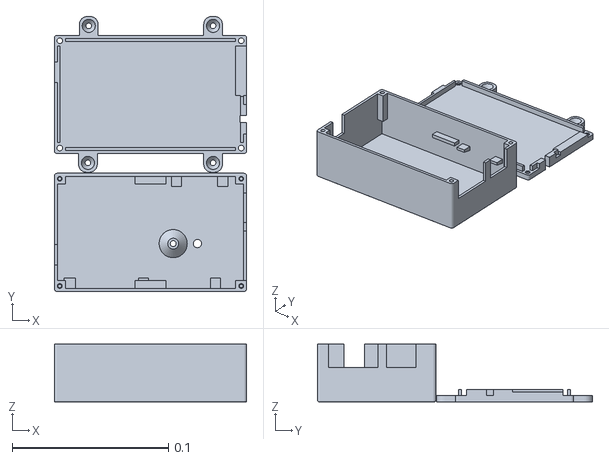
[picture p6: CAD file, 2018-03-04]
BlueGigaEmpeg Enclosure - Version 02.stl
0.123 x 0.176 x 0.037

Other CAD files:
BlueGigaEmpeg Enclosure 30 - Version 02 exportable.blend

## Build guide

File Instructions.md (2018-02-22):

BlueGigaEmpeg Instructions
===============================================================================

Congratulations to you, owner of a shiny new BlueGigaEmpeg module!

Your full detailed instructions are located online here:

- https://github.com/tfabris/BlueGigaEmpeg/blob/master/README.md

Please carefully go through the installation section of that document, the
required modifications to your empeg are detailed there. In the meantime,
please remember this:

- Do not plug the BlueGigaEmpeg module into the empeg Car docking sled until
  the modifications described in README.md have been completed. Damage may
  occur if you plug it in before everything is ready.

Also feel free to look through the existing known issues here:

- Open bugs: https://github.com/tfabris/BlueGigaEmpeg/issues

- Closed bugs: https://github.com/tfabris/BlueGigaEmpeg/issues?q=is:issue+is:closed

Thank you, and enjoy your new toy!

Tony

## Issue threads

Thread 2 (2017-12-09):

Some kind of reset caused track titles to stop updating

tfabris, 2017-12-09:
Keep an eye out for a recurrence of this bug:

- I placed car into reverse. This should not have had an effect on the stereo so maybe it was just a timing coincidence. I have had this bug happen 3 times and only one of the times was when reversing.
- While reversing, the audio cut out for a moment, very briefly.
- When the audio came back on, it was still playing the same song.
- When the audio came back on, it was still allowing me to send track change commands via the steering wheel.
- When the audio came back on, there were no more track title changes at all, it was stuck on the screen at the prior song title.

Theories: Some kind of quick reset of one of the components but not all of the components (not sure which one) where the arduino code no longer knows the correct registration value for the track change notifications. Try to force a repro of this by poking at things.

I have attempted some mitigations in the code based on my theories but without a strong repro I am unable to be sure if my mitigations have helped or not. Look out for a repro of this to see if it recurs.

tfabris, 2017-12-09:
Possibility: Consider the chance that somehow the Arduino randomly resets itself sometimes. The reset is enough to make it reissue the startup commands to the bluetooth chip from the routine "SetGlobalChipDefaults". This causes a brief hiccup in the audio without actually disconnecting the bluetooth. But at this point the Arduino has forgotten its PDU registration codes while the bluetooth chip thinks they're fine. This might indeed cause a problem where things sorta kinda work but not everything works, such as pause/play/next working but the track metadata failing to work. Not certain about this. But if that's the case then we have no choice but to reset the bluetooth chip each time the Arduino starts up. There is some code (currently commented out) that will do this but I don't want to enable it unless I have to.

tfabris, 2017-12-10:
Update: Had a repro of this issue and also a few minutes prior I had a repro of the OPPOSITE issue: The track titles were updating fine but the steering wheel controls were not working.

Will be attempting to work around this temporarily by enabling the feature which resets the bluetooth chip if the Arduino happens to reset itself.

If this works, and if you encounter a situation where the system resets itself just while you're driving along, consider implementing a write protect switch for the Arduino so that it doesn't auto-reset itself due to random floating information on the USB serial port. You did this on your earlier Butterfly project and that worked well.

tfabris, 2017-12-14:
I haven't had this repro since I added the code that forces the Arduino to reset the bluetooth chip after its initial startup. Closing issue until I get a repro again.

Closed 2017-12-14.

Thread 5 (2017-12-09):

Track title updates are slower than they used to be.

tfabris, 2017-12-09:
Before Hijack V522, the act of switching to a new track usually caused a fairly quick update to the track title on the car stereo's touchscreen. Now there is a more noticeable delay, on the order of possibly 500ms or so.

I had to fully rewrite the track metadata parser at that time, so it's possible that I introduced a slowness bug of some kind. Not sure.

I don't expect that Hijack itself made things slower, though we should investigate that just in case.

Although Hijack is now outputting more/new data such as the track duration and the album title, there was also a new change which reduced the number of total characters coming out on the serial port by removing the "serial_notify.cpp" text from every single line. With this change, I expect that the total amount of data on the serial port should have been REDUCED overall, not increased.  Should double check this assumption to make sure it's true.

tfabris, 2017-12-11:
Update: This has nothing to do with Hijack.

It is because for some unknown reason the headunit is asking for new track data in a continuous repeated loop and the BlueGiga has to keep responding to it.

Investigating.

tfabris, 2017-12-12:
Updates:

I have observed two states in the debug console:

1. Good: Host stereo queries with AVRCP 1 GET_ELEMENT_ATTRIBUTES 01 01? etc for the track metadata once or twice and then stops re-querying, in favor of only asking for AVRCP 1 GET_PLAY_STATUS every second.

2. Bad: Host stereo queries for all of the above once per second: All of the track elements as well as the play status... every second.

The initial connection messages don't seem different between the two. Though I did notice this difference:

Good: A2DP CODEC SBC JOINT_STEREO 44100 BITPOOL 2-53
Bad:   A2DP CODEC SBC JOINT_STEREO 48000 BITPOOL 2-53

I don't see how that's relevant though.

One thing that I did when I got the repro was: There host stereo had connected to my phone instead of the empeg. After I went to the car stereo's touch screen and reconnected to "empeg Car" then it connected successfully (all the messages looked right) but then I got the bad "2" state of the repeating track metadata queries.

When this occurs the remedy is to power cycle the bluetooth (you can simply sleep/wake the empeg to make this happen). Maybe there is a way to detect the issue when it recurs (say, for example, more than three GET_ELEMENT_ATTRIBUTE call groups within a few seconds without the track number having been changed), and then if that happens just do a quick reset. Think about that.

tfabris, 2017-12-12:
The time that I most reliably reproduced this problem was in the following situation:

- Start the car.
- Car headunit paired with my iPhone first.
- Then I used the car's touchscreen menu to select pairing with the empeg.
- I got the repro right away.

This might be a bug in the head unit. I believe the long term fix will be to make sure that the empeg always connects first. Working on that part of it still, since it causes some problems of its own being dealt with in other bugs and workarounds.

tfabris, 2017-12-14:
Primary slowness of track title updates is now determined to be caused by Hijack but with an explanation. Each time that a new track title comes out, Hijack now has to fish up the FID of the track to go get the album title that I wanted. When the empeg is playing this can sometimes be a bit slow. It's faster when the empeg is paused. Not sure why, Mark expects that it's due to drive spinup but if that were true it'd be the opposite. Notified mark of this.

tfabris, 2017-12-15:
This has improved in Hijack V524. I think it is at an adequate speed now... Not perfect, but acceptable.

Closing as "Fixed" - open a new bug if you see any place where this can be optimized farther.

Closed 2017-12-15.

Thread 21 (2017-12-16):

Some stereos don't ask for "GET_CAPABILITIES 3" so AVRCP does not work.

tfabris, 2017-12-16:
Some stereos (Jen's Onkyo system is one that I've seen) does not send the "GET_CAPABILITIES 3"
command so I never get the chance to respond with "AVRCP RSP 1 2" response to tell it that I can notify it of track changes. This means the AVRCP stuff never works on the system.

There was a point in time when this once worked on that Onkyo system so there must be a mistake somewhere in my query/reponse systems which would kick this thing into gear so that it does all the AVRCP stuff correctly.  Perhaps it's the Class Of Device or something. Investigate this and see if you can make it work.

tfabris, 2017-12-16:
Attaching log of conversation with Onkyo system.

[Bug repro - Some stereos do not ask for GET CAPABILITIES 3.txt](https://github.com/tfabris/BlueGigaEmpeg/files/1565174/Bug.repro.-.Some.stereos.do.not.ask.for.GET.CAPABILITIES.3.txt)

tfabris, 2017-12-18:
Onkyo system the play/pause/FF commands work for brief shining moments when it's the Onkyo stereo doing the connection request as opposed to the BlueGiga doing the connection request.

I had a think where I'd paired the Onkyo with the BlueGiga a long long time ago and it was still in the list of devices on the Onkyo, But I'd erased pairing on the BlueGiga. No matter, the Onkyo paired right up after I powered it on, since I have this thing in "just works" mode all the time.  (Note: I had just disconnected the bluetooth headset a moment prior, this might have been a factor.)

Immediately after the onkyo did RING at my BlueGiga and paired up, for a short time until I reset the BlueGiga, the Onkyo play/pause worked on my empeg.

tfabris, 2017-12-25:
Tried all these different CoDs and they did not fix the problem:
  //  0x200420 =
  //  - Major service class: Audio
  //  - Major device class:  AudioVideo
  //  - Minor device class:  CarAudio
  // 0x280428 =
  //  - Major service class: Audio and Capturing
  //  - Major device class:  AudioVideo
  //  - Minor device class:  HiFi Audio
  // 0x200428 =
  //  - Major service class: Audio
  //  - Major device class:  AudioVideo
  //  - Minor device class:  HiFi Audio and Car Audio

tfabris, 2017-12-25:
Tried AVRCP PDU 31 1 and AVRCP PDU 31 2 and those didn't help. They were the wrong direction.

tfabris, 2017-12-25:
Tried AVRCP PDU 10 3 and it didn't help.

tfabris, 2017-12-25:
Tried a few variations on sending AVRCP NFY (either interim or changed) and they didn't help since there was no transaction label pair to work from.

tfabris, 2017-12-25:
Things to think about:
- The onkyo doesn't seem to be connecting in Stereo, there are only two connection channels, one AVRCP and one A2DP, so maybe it isn't getting the stereo channels.
- The onkyo when first pairing gets a security error on channel 3. Maybe that's part of the problem. Here's a transcript.

0000001 --- INQUIRY 30
0000004 Empeg state..................................PLAYING  >
0000011 Empeg state..................................PAUSED   ||
0000002 Empeg state..................................PAUSED   ||
0021954 INQUIRY_PARTIAL 00:09:b0:9c:87:9b 240400
0000002 ------------------------------------
0000001    Pairing buddy device address:
0000001 00:09:b0:9c:87:9b
0000000 ------------------------------------
0000004 --- PAIR 00:09:b0:9c:87:9b
0000053 INQUIRY 1
0000017 INQUIRY 00:09:b0:9c:87:9b 240400
0004614 PAIR 00:09:b0:9c:87:9b OK
0000002 --- CALL 00:09:b0:9c:87:9b 19 A2DP
0000044 CALL 0
0000699 CONNECT 0 A2DP 19
0000001 --- CALL 00:09:b0:9c:87:9b 17 AVRCP
0000053 CALL 1
0000151 CONNECT 1 AVRCP 17
0000057 CONNECT 2 A2DP 19
0000001 --- A2DP STREAMING START
0000002 --- CALL 00:09:b0:9c:87:9b 17 AVRCP
0000070 CALL 3
0000012 A2DP STREAMING START 0
0000001 --- Sending to empeg: C
0000001 Empeg state..................................PLAYING  >
0000017 AUDIO ROUTE 0 A2DP LEFT RIGHT
0000001 Detected: Pairing Mode is Complete.
0000001 --- SET CONTROL RECONNECT 4800 0 0 7 0 A2DP A2DP AVRCP
            STORECONFIG
0000255
0000000 --------------------------------------
0000001         Pairing process ended.
0000000 --------------------------------------
0000001
0000136 Empeg state..................................PLAYING  >
0000002 Empeg state..................................PLAYING  >
0000003 Empeg state..................................PAUSED   ||
0000374 A2DP CODEC SBC JOINT_STEREO 44100 BITPOOL 2-40
0000026 NO CARRIER 1 ERROR 0
0000028 NO CARRIER 3 ERROR 9003 L2CAP_CONNECTION_REJ_SECURITY
0000110 Empeg state..................................PLAYING  >

tfabris, 2017-12-25:
Yes and no. I fixed the bug in pairing where I accidentally sent too many CALL 17 AVRCP commands, causing it to try to set up an AVRCP channel while the host stereo was in the middle of trying to establish its second (stereo) A2DP channel. That is what was causing the messages NO CARRIER 1 ERROR 0 and NO CARRIER 3 ERROR 9003 L2CAP_CONNECTION_REJ_SECURITY.

But now I've fixed those, the Onkyo pairs in Stereo correctly, and there are no error messages.

But still no query for GET CAPABILITIES 3 from the Onkyo. Sigh.

tfabris, 2018-01-12:
Added an additional place where it does a CALL {0} 17 AVRCP so see if this improves things on the Onkyo.

tfabris, 2018-01-14:
Jen’s Onkyo now works for the AVRCP commands for pause, play, ff, rew, etc.

It still does not get track titles but I don’t think that’s my fault. I think my code is working correctly for this now.

Closed 2018-01-14.

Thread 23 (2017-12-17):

Fix editor issues in dev envronment

tfabris, 2017-12-17:
Drag and drop text editing is enabled in your dev environment. Kill that annoyance.

Double spacing inserts a period in your dev environment. Kill that annoyance.

tfabris, 2017-12-17:
Fixed:
Drag and drop text editing: Sublime Text, Preferences, Settings, add ""drag_text": false," to your user settings file.

Fixed:
Double space: Mac preferences, keyboard, text, untick the appropriate tickybox.

Closed 2017-12-17.

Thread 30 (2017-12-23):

Desynch’d visuals: Investigate low latency codec.

tfabris, 2017-12-23:
The visuals on the empeg screen are way ahead of the audio coming out of the speakers.

There is an option to unlock a low latency codec feature on the Bluetooth chip (APTX?) if you buy a license. Investigate this.

tfabris, 2017-12-24:
More information:
- Requires different firmware version on the Bluetooth chip, and the licenses installed.
- Will need to contact Sales for Sierra Wireless to get licensing pricing, and if acceptable, get firmware download.
- Don't know if they'll sell me a limited number of licenses (a few as opposed to thousands).
- Might not be worth the effort, but keep in mind it's possible.

tfabris, 2017-12-27:
Note: I tried the AAC codec and it had troubles. It produced no sound on my Honda stereo, though it did seem to make some kind of a connection. AVRCP worked. However, it resulted in the system querying for new track data in a continuous loop, slowing down the system and causing problems.

tfabris, 2017-12-28:
Hmmm. Looking at the firmware file that I installed, it appears as though the file already includes APTX in the file name, so perhaps the firmware is already there. Next, I need to investigate to see how much a license is and how to install it.

tfabris, 2017-12-30:
Type the command at the console:

aptxll

to see if the license key for APTX Low Latency codec is installed.

tfabris, 2018-01-01:
Update:
The APTX version of the firmware is indeed installed.

Note that you cannot just type APTX or APTXLL by itself in the normal mode of the BlueGigaEmpeg. You must first reset it to factory defaults with SET RESET. Then after you have done that then you can type APTX or APTXLL to see if you have a license.

My chip did not come with a license for it, I get:

APTX
0004907 APTX
0000064 APTX LICENSE KEY IS MISSING OR INVALID!
APTXLL
0004023 ⸮APTXLL
0000057 APTXLL LICENSE KEY IS MISSING OR INVALID!

So we could theoretically talk to their tech support to see about buying an APTXLL license key.

tfabris, 2018-01-04:
Support ticket opened to find out the APTX_LL pricing.

tfabris, 2018-01-12:
Support responded with detailed instructions.

I have to install a test license key they gave me which is tied to a specific MAC address, then use a tool called PSTOOL which allows me to edit the chip's MAC address to spoof and allow the license to work for test purposes.

Problem is, PSTOOL doesn't work on the Betz board. It works on the BlueGiga development board but that one has a fried chip.

To do: see if PSTOOL works on my next Betz board replacement, and if not, I'll give up on this idea.

tfabris, 2018-01-19:
Forget the low latency codec for now. The thought of having to contact their sales team makes my skin crawl.

tfabris, 2018-03-04:
Reopening this issue. I'm coming back to this to see if it solve issue #72 as well.

I have ordered the necessary programming tool, a "CSR USB-SPI" programming converter part, and I need to roll my own interface pinouts to the Betz board. I have taken copious notes on this process. Awaiting programmer to arrive so I can try this.

tfabris, 2018-03-13:
I was able to get APT-X-LL working on one of my boards , using the CSR-USB-SPI programming tool device. It was only with a test license, though, I can't enable it for all boards without going through the process of purchasing the licenses and programming the license into the ROMs of every board using that special programming tool.

Results so far:

- APT-X-LL worked great when paired with the Etekcity Bluetooth  receiver. It definitely solved the problem of desynchronized visuals.

- However it did not work when paired with my main target device, my Honda factory car stereo.  It dropped back to the SBC codec; I can tell because the visuals are still desynchronized. My guess is that APT-X-LL is not supported by the Honda, though I want to triple check that to make sure it's not a problem with the programming of the BGE module.

- I had two repros of issue #70 (crackling chipmunk playback) in a very short time, almost back-to-back but not quite, on the Honda stereo, with the APT-X-LL turned on. I don't know if it's related, but I could imagine that the process of trying the unsupported codec and then dropping back to SBC might cause the handshaking process of the initial connection steps to be flakier and might "let the iPhone in the door" causing the problem.

Since the APT-X-LL codec is not supported by my factory Honda car stereo, this is now a complete non-starter since it's not supported on my main target system. I will not pursue this further, though I am very curious about whether it solves a couple of other problems, so I'm going to check those before closing out this bug.

To do:
- Find out how to tell, from the command line, whether APT-X-LL is currently the codec in use during the current session. This would be helpful in certain indoor debugging mode situations. Not sure if this is possible or not.

- Triple check on Honda support. Make absolutely sure that the BGE is programmed correctly and has the correct priority settings for the various codecs, and that your car stereo has the best possible chance to make use of the APTXLL codec. See if you can find out, by searching online, whether the Honda is expected to support it at all.

- Find out if issue #72 (very quiet passages are beneath the Bluetooth "floor") is fixed by APTXLL. You'll need to check your specific test tracks against this in very controlled circumstances.

tfabris, 2018-03-13:
Done:
- Did everything I could to check to make sure the Honda truly does not support APT-X-LL. I can't get APTXLL to work on the Honda at all. Did a bunch of different things to try.

- It seems to increase the frequency of issue #70 repro: I got two more repros, though I don't yet have enough data to be sure I wasn't just lucky.

To do:
- Search for command line command to check if APTX-LL is being used at the current time.

- Check if it fixes issue #72 (quiet bluetooth floor).

tfabris, 2018-03-13:
Closing this issue:
- I'm not going to pursue APTXLL any farther because it doesn't work on my Honda.
- Issue #70 is covered under its own bug. This may or may not increase that bug's repro frequency, but it's not the cause of it.
- Issue #72 is being tracked under its own bug and I will experiment with it there.

Closed 2018-03-13.

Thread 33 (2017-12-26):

Update circuit board design.

tfabris, 2017-12-26:
Update C5 instructions to be 0.1uf (make sure your C1-C5 identifiers match the schematic too).

Update for Vdivs on I2S pins.

Update for reset line with Vdivs and diode. Note on first resistor to not install if not using reset line.

tfabris, 2017-12-26:
You have a completed design for Rev 4.

You have a routed ground plane version which routed well.

You have a detail version with all your silkscreen updates which inexplicably didn't route well, despite being the same layout as the ground plane version which routed well.

Reconcile those two versions.

tfabris, 2017-12-26:
You have completed this task. Rev 4 is ready once the prototype circuits for the voltage dividers on the I2S and Reset lines have been tested successfully on your Rev3 prototype.

Closed 2017-12-26.

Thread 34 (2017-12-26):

Create 3D printed enclosure.

tfabris, 2017-12-26:
Need a 3D printed enclosure design.

tfabris, 2018-01-16:
Design is complete, need to print it and test it.

tfabris, 2018-01-16:
Note to self: enlarge button hole to 3.5mm

tfabris, 2018-01-16:
Also re-measure and reconsider overall height to be sure.

tfabris, 2018-01-18:
Remaining to do: Smaller lid mounting screw holes, and more thickness trimming to get Shapeways price down.

tfabris, 2018-01-19:
First Shapeways order placed. Also final Rev 6 board order placed.

Closed 2018-01-19.

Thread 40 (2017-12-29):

Issues with crossover wiring and additional lines on sled serial plug - Different from Empeg to Rio.

tfabris, 2017-12-29:
Your original serial 00013 sled seems to be in crossover configuration and now you're not sure if that was even correct to begin with. You designed your boards to follow this style and then discovered the Rio Car sled was straight configuration. So you pulled the pins to cross it.

See if you can reverse RX/TX connectors on your boards, then put  both sleds back to straight configuration.

tfabris, 2018-01-04:
It's worse than that. I had a weird serial port issue on the Rio Car sled wiring.

Issue is caused because there is something significantly different about the Rio Car sled serial port than the Empeg 600013 serial port. The serial port sends data when booting but then stops sending data as soon as the player app starts running. There are other wires connected to the serial port above and beyond the usual, including an amp remote power wire, and as such the player's Sleep LED is always lit when the serial port is plugged in. Something is fishy here, you need to get to the bottom of how the serial port wiring evolved on these things.

tfabris, 2018-01-04:
The only difference between the expected wiring and the actual wiring that you found was the possibly crossed over RX/TX lines. You will deal with this my making jumpers on the BlueGigaEmpeg for crossing over the connection. You have also posted an updated wiring diagram on the FAQ section of the EmpegBBS. Closing this bug as "Done".

There is a separate issue with the Red player not outputting @@ messages on the serial port. That does not appear to be wiring related.

Closed 2018-01-04.

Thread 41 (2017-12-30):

RX/TX serial port garbage dependent on voltage on Betz board.

tfabris, 2017-12-30:
Pre-conditions:
- BlueGigaEmpeg board assembly is connected to both the the WT32i chip and to the Arduino.
- Using the BetzTechnik WT32i breakout board connected to the BlueGigaEmpeg board.
- Monitoring the debug console of the Arduino with the Arduino Serial Monitor program.

Symptom:
- Some of the strings of communication data from the Betz board are interspersed with occasional garbage characters.
- This causes some intermittent command/response pairs between the BlueGigaEmpeg code and the WT32i to fail.
- This is not the same thing as an RS-232 buffer overflow, I can tell what those look like now. This is something different. This is characters being read, but they are coming out of the WT32i serial ports every once in a while as garbage characters.

Repro:
- Connect to Arduino with Serial Monitor.
- In the Serial Monitor, repeatedly type the following command and press ENTER after each one:
  set
  set
  set
  set
     (etc.)
- Expected: You should always get a perfect screen full of perfect uncorrupted data.
- Actual: Sometimes the characters are incorrect, such as question mark characters or wrong characters. Look closely.

Conditions in which it repros:
- JP4 on Betz board is cut so that the UART is not powered.
- Arduino cable is connected to Arduino and computer and you are monitoring with Serial monitor (so Arduino is getting 5v from its USB port).
- BlueGigaEmpeg is also fully connected to the empeg docking sled Tuner/Power/I2S plug.
- Therefore BlueGigaEmpeg is also getting its power from the Pololu 5v power supply.

Conditions in which it does NOT repro:
- Using the BlueGiga dev board instead of the Betz board.
- OR...
- JP4 on Betz board is NOT cut and so the UART is powered (also have to locate and cut the traces for the RX/TX lines between the UART and WT32i for this arrangement to work).
- OR...
- The empeg is not connected to the BlueGigaEmpeg module and so it is not receiving power from the Pololu power supply (power is only coming from the Arduino USB port).

Unknown condition:
- Powered only from the empeg+Pololu, with no USB cable connected to the Arduino at all. Since I cannot directly observe the bug unless I'm using that cable, I have no idea if this fixes the issue or not. The repro is intermittent and the outwardly noticeable problems caused by this are even more intermittent. So I don't know if having a "single power source" is the correct solution or not.

tfabris, 2017-12-30:
Possible: Voltage from Betz TX to Arduino RX might be too small. Try a pullup resistor as suggested by Mark Lord on EmpegBBS.

tfabris, 2017-12-31:
2k pullup resistor on arduino RX2 line seems to work. Closing issue. Reopen if you see more problems.

tfabris, 2018-01-11:
Later, removed the pullup resistor because we converted the Betz board to 3.3v and it worked to fix the garbage.

Closed 2018-01-01.

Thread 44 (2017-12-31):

Create 2k pullup circuit on PCB

tfabris, 2017-12-31:
New pullup circuit on Arduino RX2 line, described in README.txt, needs to be added to Rev 4 of the Pad2Pad printed circuit board.

tfabris, 2018-01-04:
Closing this as "Won't Do". Changing the Betz board to 3.3v solved the issue and we don't need the pullup any more.

Closed 2018-01-04.

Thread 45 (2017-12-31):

Initial boot and connect problem on Honda

tfabris, 2017-12-31:
There is an intermittent problem where initial car start and boot power up of the empeg and Honda stereo where they do not connect properly and there is random behavior.

When it works well it is good but when it goes bad it’s really bad. Sometimes empeg goes into infinite restart loop.

Possibly related to my iPhone and the empeg fighting for who’s first to connect.

tfabris, 2017-12-31:
One particular side issue of this is, when it happens, the empeg keeps playing silently while the stereo is either disconnected or playing  from the iPhone. This is also unacceptable and relates to a need for an additional detection message as to when we are disconnected from Bluetooth and need to pause the player.

tfabris, 2018-01-01:
Here is a bad state with the honda. It didn't do the reboot loop but it has most of the other bad symptoms. No track data.

0000000 Built in Arduino Serial has been started.
0000001 BlueGiga Serial has been started.
0000001 Empeg Serial has been started.
0000000 --^ Sending to empeg: W
0000002 BlueGigaEmpeg Version 1.0.47
0000003 Arduino chip type: AT Mega 2560 - Good.
0000004 Serial receive buffer size: 256 - Good.
0000004 Serial xmit buffer size:    128 - Good.
0000004 Physically resetting bluetooth module with RST line - Begin.
0000208 Physically resetting bluetooth module with RST line - Complete.
0000729   IGNORED: WRAP THOR AI (6.2.0 build 1122)
0000001 Pausing empeg for convenience while setting global chip defaults.
0000001 --^ Sending to empeg: W
0000001 Setting Defaults.
0000002 --^ SET CONTROL ESCAPE - 00 0
0000004 --^ SET CONTROL ECHO 5
0000002 --^ SET CONTROL BATTERY 0 0 0 0
0000004 --^ SET CONTROL CONFIG 0000 0000 0000 5100
0000004 --^ SET CONTROL CODEC SBC JOINT_STEREO 44100 0
0000005 --^ SET BT CLASS 280428
0000003 --^ SET PROFILE SPP
0000003 --^ SET PROFILE A2DP SOURCE
0000003 --^ SET PROFILE AVRCP TARGET 3
0000003 --^ SET BT NAME empeg Car
0000003 --^ SET BT SSP 1 0
0000002 --^ SET BT AUTH * 0000
0000003 --^ SET CONTROL AUDIO INTERNAL I2S_SLAVE EVENT KEEPALIVE 16
0000006 --^ SET CONTROL PREAMP 0 0
0000003 --^ SET CONTROL MICBIAS 0 0
0000003 --^ SET CONTROL GAIN 9 0
0000003 Done Setting Defaults.
0000002 --^ Sending to empeg: W
0000003 Performing soft reset of bluetooth module.
0000005 --^ RESET
0000002 Clearing global variables.
0000005   IGNORED: Copyright (c) 2003-2017 Silicon Labs Inc.
0001165   IGNORED: WRAP THOR AI (6.2.0 build 1122)
0000004 Copyright (c) 2003-2017 Silicon Labs Inc.
0000118 READY.
set
0001616 SET BT BDADDR 00:07:80:fa:9a:73
0000012 SET BT NAME empeg Car
0000019 SET BT CLASS 280428
0000015 SET BT AUTH * 0000
0000043 SET BT IDENT BT:47 f000 6.2.0 Bluegiga iWRAP
0000017 SET BT LAP 9e8b33
0000026 SET BT PAGEMODE 4 2000 1
0000033 SET BT PAIR 48:f0:7b:57:15:20 6c6d67e3ea292e50532962ee841ed68a
0000001 ------------------------------------
0000001    Pairing buddy device address:
0000001 48:f0:7b:57:15:20
0000003 ------------------------------------
0000012 SET BT POWER 6 6 6
0000026 SET BT ROLE 0 f 2580
0000035 SET BT SCO a 1 4d d 2 48
0000027 SET BT SNIFF 0 20 1 8
0000013 SET BT SSP 1 0
0000018 SET BT MTU 667
0000039 SET CONTROL AUDIO INTERNAL I2S_SLAVE EVENT KEEPALIVE 16
0000028 SET CONTROL BAUD 115200,8n1
0000037 SET CONTROL CD 00 0
0000031 SET CONTROL CODEC SBC JOINT_STEREO 44100 0
0000036 SET CONTROL CONFIG 0000 0000 0000 5100
0000015 SET CONTROL ECHO 5
0000028 SET CONTROL ESCAPE - 00 0
0000021 SET CONTROL GAIN 9 0
0000025 SET CONTROL MICBIAS 0 0
0000043 SET CONTROL MSC DTE 00 00 00 00 00 00
0000027 SET CONTROL PIO 00 00 00
0000020 SET CONTROL PREAMP 0 0
0000021 SET CONTROL READY 00
0000027 SET CONTROL VREGEN 0 00
0000065 SET CONTROL RECONNECT 4800 0 0 0007 00000000-0000-1000-8000-00805f9b34fb A2DP A2DP AVRCP
0000009 SET PROFILE A2DP SOURCE
0000052 SET PROFILE AVRCP TARGET 03
0000001 SET
0008725 --------------------------------------
0000001 empeg player boot process has started.
0000000 --------------------------------------
0012318 -------------------------------------
0000001 empeg player application has started.
0000001 -------------------------------------
0000000 Detected empeg bootup sequence completion, sending pause command to player.
0000008 --^ Sending to empeg: W
0000111 Empeg state..................................PAUSED   ||
  0000031 ---------------------------------------------------
  0000001 61
  0000008 I Still Haven't Found What I'm Looking For
  0000002 U2
  0000003 The Joshua Tree
  0000002 278573
  0000002 Rock
  0000000 ---------------------------------------------------
0000001 Empeg state..................................PAUSED   ||
  0000002 ---------------------------------------------------
  0000005 61
  0000006 I Still Haven't Found What I'm Looking For
  0000002 U2
  0000002 The Joshua Tree
  0000002 278573
  0000002 Rock
  0000000 ---------------------------------------------------
0000003 Empeg state..................................PAUSED   ||
0000007 First timestamp received from empeg Car - Not performing play-pause state change code just yet.
0000007 empegStartPause feature activated. Pausing player on first timestamp after boot up.
0000008 --^ Sending to empeg: W
0000043 Empeg state..................................PLAYING  >
0000011 Empeg state..................................PAUSED   ||
0000002 Empeg state..................................PAUSED   ||
0015863 RING 0 48:f0:7b:57:15:20 19 A2DP
0000110 RING 1 48:f0:7b:57:15:20 17 AVRCP
0000002 --^ A2DP STREAMING START
0000182 RING 2 48:f0:7b:57:15:20 19 A2DP
0000023 AVRCP 1 GET_CAPABILITIES 2
0000001 --^ AVRCP RSP
0000009 A2DP STREAMING START 0
0000001 --^ Sending to empeg: C
0000016 AUDIO ROUTE 0 A2DP LEFT RIGHT
0000002 --^ SET CONTROL RECONNECT 4800 0 0 7 0 A2DP A2DP AVRCP
            STORECONFIG
  0000387 ---------------------------------------------------
  0000001 61
  0000057 I Still Haven't Found What I'm Looking For
  0000002 U2
  0000003 The Joshua Tree
  0000001 278573
  0000002 Rock
  0000001 ---------------------------------------------------
0000001 Empeg state..................................PLAYING  >
0000002 Empeg state..................................PLAYING  >
0000007 Empeg state..................................PAUSED   ||
0000427 Empeg state..................................PLAYING  >
0003185 A2DP CODEC SBC JOINT_STEREO 44100 BITPOOL 2-53
0015741 AVRCP PLAY PRESS
0000001 --^ Sending to empeg: C
0000001 --^ A2DP STREAMING START
  0000135 ---------------------------------------------------
  0000001 61
  0000006 I Still Haven't Found What I'm Looking For
  0000003 U2
  0000003 The Joshua Tree
  0000002 278573
  0000002 Rock
  0000000 ---------------------------------------------------
0000001 Empeg state..................................PLAYING  >
0000002 Empeg state..................................PLAYING  >
0020370 AVRCP FORWARD PRESS
0000001 --^ Sending to empeg: N
  0000088 ---------------------------------------------------
  0000001 62
  0000026 In the Black
  0000002 Marian Call
  0000002 Got to Fly
  0000002 301901
  0000002 Folk
  0000000 ---------------------------------------------------
0000001 Empeg state..................................PLAYING  >
0019928 AVRCP FORWARD RELEASE
0020042 AVRCP FORWARD PRESS
0000001 --^ Sending to empeg: N
  0000061 ---------------------------------------------------
  0000000 63
  0000417 Waitress
  0000002 Tori Amos
  0000003 Under the Pink
  0000002 190410
  0000002 Rock
  0000000 ---------------------------------------------------
0000001 Empeg state..................................PLAYING  >

tfabris, 2018-01-01:
Candidate fix checked in and I need to test it over time.

Don't do as many unneccesary "A2DP Streaming Start" commands. These might be confusing and inducing bugs in the host stereo's bluetooth operating system. One of the first things that happens after initial connection is that the host stereo sends a play command to the player, and it's possible that the extra "streaming start" is causing undefined behavior at that crucial time.

This is just a theory that needs to be borne out over time/testing.

tfabris, 2018-01-02:
Candidate fix did not solve the problem. Need to get another repro on the USB debug cable.

tfabris, 2018-01-02:
I got some repros but I don't see any particular problems with them.

Ideas to try:

- See if it's a temperature problem with the betz board. The problem seems to go away the more I fiddle with it, and the Betz board had some issues with Vias that didn't work and stuff. Maybe there is something that is losing connection when it's cold and makes connection when it's warm.

- Does the AVRCP RSP <blank> command for the "get capabilities 2" require a parameter even though the docs say it doesn't?

tfabris, 2018-01-02:
More ideas to try:

- Many initial boot connection attempts contain the line:
L2CAP_CONNECTION_REJ_RESOURCES
It frequently recovers from this but see what resource is being rejected and how to work around this.

- Things seem to work well when my card connects to the head unit instead of vice versa. In other words the messages contain "CONNECT 0" instead of "RING 0". Find out how to make it so that I'm the one doing the connecting instead of the head unit?

- Or possibly try the opposite. The bad place happens frequently when "CONNECT 0" and "RING 1" are mixed on top of each other. What happens if I take out Autoconnect altogether?

tfabris, 2018-01-02:
Issue is that the Betz board keeps shutting down on its own. Try checking all it’s traces and try maybe upping its voltage regulator.

tfabris, 2018-01-03:
I upped its voltage regulator to one of my digikey ones. The 2.5v on the 3v3 pin is now 2.6v and some of the boot problems went away but not all of them. Consider going higher, or just skipping it altogether and going for the 3v from the Arduino straight into the 3v3 pin on the Betz board.

tfabris, 2018-01-03:
I'm getting garbage on the serial port input from the bluetooth module again with the new voltage regulator. Need to figure out if the pullup is enough, or too much.

tfabris, 2018-01-03:
Pullup resistor calculator is here:
https://ben.artins.org/electronics/pullup-resistors/?

tfabris, 2018-01-04:
Problems solved by converting module to run on 3.3v instead of 2.5v like Betz had it running.

Closed 2018-01-04.

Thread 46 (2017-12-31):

Externally visible LED on Betz bt module.

tfabris, 2017-12-31:
Diagnosis of problems with bt chip would be easier if I could see Betz module red LED outside case.

tfabris, 2018-01-01:
The LED0 pin on the BT chip is not routed to an external pin on the Betz board so investigate to see if you can drive this reliably with one of the PIO pins. The issue is that maybe the information you want can only be seen directly from the LED0 pin. So maybe this isn't easily doable from the betz board.

tfabris, 2018-01-01:
Forget the PIO pins. All I need is a window in the housing so I can see the existing Betz board LED.

If I am continuing to use the Betz board, look for a clear buttoncap or light pipe rod or something like that from Digikey that I can incorporate into the casing.

If I end up rolling my own direct chip connection and skipping the Betz board altogether, then I'll implement my own exterior casing LED directly on the LED0 pin.

tfabris, 2018-01-04:
Closing this as "Won't Do". The LED on the Betz board doesn't work at 3.3v.

If we implement our own board for the Bluetooth chip instead of Betz' board then we'll roll our own LED instead.

Closed 2018-01-04.

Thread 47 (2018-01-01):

Flip the button and the blue LED to the other side of the board.

tfabris, 2018-01-01:
If you are going to implement a visible window for the Betz board LED, then your reset/pair LED and button should be on the same side of the board. You've checked it and there's room.

- Test it by flipping them on your prototype.
- Change the PCB design in Pad2Pad to indicate mounting positions correctly.
- If they are on the other side of the board in the Pad2Pad design, then they can be placed closer to the middle of the board instead of the edge, since there's space now that way.

tfabris, 2018-01-04:
Closing this as "Won't Do" - When doing 3v for the Betz board, the LED stops working so it's not needed to be visible any more. So we can leave the button and LED where they are.

tfabris, 2018-01-05:
Reopening this issue.

Move the blue LED and button to the other side of the board because the place where you velcro it in your trunk causes the BT chip to be buried behind the empeg and against the trunk wall. Flip the button and board around so that when it's mounted the BT chip *AND* the other stuff is facing out.

tfabris, 2018-01-08:
I've done this on my prototype board, still need to do it in the Pad2Pad layout.

tfabris, 2018-01-11:
Done on the Pad2Pad design Rev 6. Still need to optimize positioning. Will likely also move Pololu too.

Closed 2018-01-11.

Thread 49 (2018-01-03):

Attempt to power BT chip with 3v of your own and see if that solves many problems?

tfabris, 2018-01-03:
It's possible that if you disconnect the 5V supply to the Betz board you might be able to power 3v into its 3v3 pin.

Check to make sure that your 3v output pin from the Arduino is really generating 3v and see if that works. Make sure it works in all modes.

Make sure not to power 5v and 3v at the same time into the Betz board.

Check your temperature.

tfabris, 2018-01-03:
Will need to:
- Rev3 board: Cut 5v trace in two places to prevent the 5v supply from the pololu to reach anything.
- Rev3 board: Jumper 5v from pololu to VIN on the arduino.

At this point verify and test that you get 5v and 3v in the expected places coming out of the Arduino. Then you can:

- Rev3 board: Cut 5v trace running to the Betz 5vin pin. -OR- cut the jumper on the Betz of CHG_ENA. Both will result in the same thing. Maybe one is safer than the other? Dunno.
- Jumper 3v from Arduino to Betz 3v3 pin.
- Jumper 5v from Arduino to Arduino Button.
- Jumper 5v from Arduino to other possible places 5v is needed such as the RS232 chip.
- Investigate and learn more on the schematic and data sheet about the function of VREG_ENA which is connecteted to the ON switch and/or the reset button and/or the voltage regulator. The BATT voltage is used for all of those. IS any of the BATT voltage needed for anything if I'm powering my chip directly from the 3v3 pin and issuing my own RESET line command?
- Think and look carefully for other places.

If the above works, check chip temperature and serial output. Is there serial garbage?

- Possibly adjust or remove the pullup resistors on the Arduino RX.

tfabris, 2018-01-03:
Possibly supply 3v to the following pins:
- 3v3 (VDD_IO)
- BATT
- VREG_ENA
And slide the switch to the "down/right" or "off" position.

Awaiting post on EmpegBBS with Mark's opinion on this.

tfabris, 2018-01-03:
- Also see if it's possible to remove the RESET line implementation with this kind of voltage supply.

tfabris, 2018-01-04:
Works, continuing to test. I think the below is true:

Reset line removal:  Yes.
2k pullup removal: Yes.

3v to all three:
- 3v3 (VDD_IO)
- BATT
- VREG_ENA

Pololu to VIN: Yes
5v out from arduino to the rest: Yes

tfabris, 2018-01-04:
This seems to have solved a lot of problems. Closing issue.

Closed 2018-01-04.

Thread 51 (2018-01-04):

A physical jolt will reboot the module.

tfabris, 2018-01-04:
Physically bonking the BlueGigaEmpeg prototype unit will make it reboot. Including going over a bump in the car.

I don't know which element is causing it: Arduino, BlueGiga module, power, pololu, USB, what.

But this doesn't make sense because I've made sure there's nothing loose in the assembly.

I've checked and it's not the reset button accidentally getting triggered.

It wasn't the interim wiring on the module as far as I know.

Need to find the root cause of this  before we commit to a final PCB design.

tfabris, 2018-01-04:
Consider the possibility that this is caused by the two halves of a cut PCB trace just being too close together (the places where you cut traces when you converted from 5v to 3v).

See if opening up those gaps a little more fixes the issue.

tfabris, 2018-01-04:
Unable to repro on test bench.

See if issue recurs while in the car.

tfabris, 2018-01-05:
This might be related to issue #55.

tfabris, 2018-01-06:
Issue #55 has been solved and I'll bet it'll solve this one too. Closing this issue because I'm betting I'll never see it again. If the issue recurs, reopen this card.

tfabris, 2018-02-25:
This issue has recurred once or twice since I’ve had things in their final mounting locations with final electronics and with good boards without jumper wires. Does not happen for small hits on the module, but does happen when car hits a big bad bump.

Consider that it might be the empeg rebooting because it pops out of the sled a bit.

Next time it happens see if you can see if the battery icon appears on empeg display screen. If so it’s the empeg and not the BGE, so you can re-close this issue.

tfabris, 2018-03-15:
I recently found that my Empeg had one of its sled hooks broken and the hook part was rattling around inside my empeg's casing. My bet is that the physical jolt caused this thing to be touching something bad briefly, and rebooting the empeg. Since I haven't had a repro in quite a while, I'm closing this bug again, and assuming that it was due to an empeg reboot all along.

Reopen this issue if you get another repro where you have visually confirmed (by looking for the battery icon on the empeg screen) that it's not an empeg reboot that caused the issue.

Closed 2018-03-15.

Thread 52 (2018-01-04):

Possible problem with Betz board availability, may need to implement your own.

tfabris, 2018-01-04:
Your current design depends on the Betz board being available. You fried one, and the replacement took longer than expected. You'd ordered two replacements and he was only able to send one of them. When you emailed him to ask about the second one, and the possible availability of more, you received no reply.

Consider the possibility that you might have to redesign your BlueGigaEmpeg PCB, sourcing bare WT32i chips yourself, including having to do the tedious surface-mount soldering you were trying to avoid, and also do all the same for an FTDI serial port chip and a USB plug for firmware updates.

tfabris, 2018-01-10:
Peter got back to me and will have at least 10 boards available shortly, so we should be good. Closing issue.

Closed 2018-01-10.

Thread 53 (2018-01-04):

Update PCB design with new 3v voltage design.

tfabris, 2018-01-04:
- Make a new V5 PCB design.
- No longer use 5v rail from pololu for everything. Pololu goes into Arduino VIN only.
- Arduino 5v out supplies all 5v objects (button, MAX232).
- Betz board 5vin is no longer used, it must be disconnected.
- Update description of switch position on silkscreen part of board.
- Arduino 3v pin supplies voltage to Betz board in three places:
-- 3v3 (VDD_IO)
-- ENA (VREG_ENA)
-- BATT
- Remove the reset line implementation, no longer needed.

Look for other possible changes.

tfabris, 2018-01-04:
Update:
- Arduino supplies 5v to button, but
- Pololu supplies 5v to MAX232.

(Ran into problem where in some cases the MAX232 didn't get enough voltage coming off the Arduino 5v pin).

tfabris, 2018-01-05:
I have completed a Rev 5 design including the 3v changes and the RS-232 crossover jumpers.

Closed 2018-01-05.

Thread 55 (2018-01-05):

Cold boot problems (literally)

tfabris, 2018-01-05:
I am running into an issue where the BlueGigaEmpeg module does not boot and pair properly in a cold "first thing in the morning in the winter" situation.

The behavior mimics the issues I was having before moving to 3.3v: initial pairing/connection does not work well, unit doesn't show up in a search, it pairs but then reboots, it pairs but only audio and no AVRCP, etc.

These issues didn't occur when everything was warmed up, when I brought the module out to the car from the test bench in the warm house.

Expectation is that there are additional problems with the vias and traces on the Betz board like I encountered before, where I needed to make jumpers on the Betz board to make things work.

Try:
- Make more jumpers on the Betz board to tie 3.3v directly to the necessary pins on the chip, including the RX and TX serial lines.

If that works to fix the issue, then:
- Move forward with rolling your own board and throw away the Betz board altogether, as described in issue #52.

tfabris, 2018-01-05:
Looking at the log output when the bug repros, I see that the problem is that the module is powering down and up again and rebooting itself.

tfabris, 2018-01-06:
Soldering jumpers from the side pins to VDD_BATT, VDD_IO, VREG_ENA and RX/TX seemed to fix the issue. Closing bug in favor of instating general order #52.

tfabris, 2018-01-06:
Issue still occurs, though it occurs less frequently now and it recovers sooner as the unit warms up.

Reopening issue so that I can do another soldering pass with more jumpers, including to the 470 capacitor which might be important.

tfabris, 2018-01-08:
Removed the 470 cap. See if that does the trick?

tfabris, 2018-01-08:
Possible:

when the issue is occurring, powering the arduino straight from the USB plug seems to work and the BT chip seems to be OK while powering the arduino from VIN from the pololu does not. Also, trying to do both at the same time (VIN from pololu AND from usb) does not work, but only when the issue is occurring; normally everything works fine even when double powered).

To do: look to see various options for powering the Arduino.

tfabris, 2018-01-08:
When experimenting with 5v power options on the arduino, consider that the pulldown resistor on the reset/pair button might be dragging down the voltage there. See what happens if you temporarily disconnect that button.

tfabris, 2018-01-09:
Have what I believe to be a temporary solution: Feed Pololu 5v into the USB 5v input pin on Arduino. Works on test bench, will see if it survives the "cold start".

If this works, investigate using a Pololu 7v converter instead, and re-doing everything to power off of Arduino 5v+3v again.

tfabris, 2018-01-09:
Changing the type of power did not solve the issue.

Experimenting with 10k/10k voltage divider instead of 4.7k/10k. Works on the test bench, see if it works in the morning cold.

tfabris, 2018-01-09:
Problem fixed by the 10k/10k voltage dividers. Closing issue!

Closed 2018-01-09.

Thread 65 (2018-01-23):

Couldn’t change tracks on empeg after starting car and using Siri (rare)

tfabris, 2018-01-23:
Had a rare situation where AVRCP was definitely working, audio worked, and track titles were updating, but thge empeg didn’t respond to the "next track" command or any other command for that matter.

It occurred after I had made a text message using Siri Voice Recognition on my iPhone which was also paired to bluetooth at the time. It was at the start of a drive and I needed to send a text and complete it before I started moving. I pressed the steering wheel button for Siri and the car switched over to Siri, muting/pausing the empeg in the process. After completing the text and Siri disconnected, then the Empeg was no longer responding to any of the steering wheel or touch screen controls.

The interesting part was that the track titles on the car stereo screen were still working. I could press an empeg front-panel button and the track text would change on the car stereo touchscreen. So AVRCP was working, it was receiving data *from* the empeg successfully still. It was only commands which should have been sent *to* the empeg which were not working.

Sleep/wake empeg (reboot bluetooth module by bouncing the power by sleeping/waking the empeg) fixed the issue. So it wasn’t a physically bad serial connection such as loose wires or loose plug.

Suspicion: somehow the BGE missed the line of the empeg output that told it the player was runnIng.

Possible fix: the detection of the player being awake and running needs to have more messages that it can use to perform that detection. Not just the prolux message.

tfabris, 2018-01-23:
Looked at the existing code and it’s not due to the code mischaracterizing the player state.  The code already has a feature for this.

My next guess is an avrcp mixup with registrations and message sequence ids. However I can’t currently imagine a scenario where this could occur.

Attempted repro of issue with Siri engagement and it didn’t repro.

tfabris, 2018-01-24:
Got a repro. Conditions (not sure which conditions are required):

- car is cold.
- car in Work garage.
- start car.
- Bluetooth pairs successfully with empeg and with phone.
- empeg plays music gud
- no toucha da empeg
- no toucha da next track buttonz
- press hold Siri button on steering wheel and make a phone call.
- empeg successfully pauses during phone call
- when done phone Call hangs up by itself.
- after back at main screen try next track button.
- no worky
- press next on empeg front panel, worky, new track title worky
- steering wheel and touchscreen no worky
- switch to FM radio and back still no worky
- press stereo off button and empeg does not pause as it should do

tfabris, 2018-01-24:
Sleep wake empeg (reboot Bluetooth) = worky

tfabris, 2018-01-24:
Sleep wake empeg reboot Bluetooth then try Siri call = no repro, worky

tfabris, 2018-01-24:
Power off car completely power on car without engine running

Same steps as before

No repro, worky

tfabris, 2018-01-27:
I’ve tried several attempts to repro on the debug cable and can’t get a repro.

I don’t think I’m Heisenberging it with the debug cable. Since the repro is rare and intermittent I think it’s just coincidence. I’ve tried many repros both with and without the debug cable and I’ve only had two repros so far, both of them off-cable.

tfabris, 2018-01-31:
I had a third repro. It was unfortunately without the debug connection, and was just a short time after I had attempted a repro with the debug connection connected.

My recollection of this repro was that it did NOT require engaging Siri. It was just getting in the car turning it on, cold start. All other symptoms were the same.

tfabris, 2018-02-10:
I got a fourth repro of this (also not on the debug cable) but something interesting this time:

- Issue occurred immediately after starting car. Engaging Siri was not required to cause the bug to reproduce.
- Track title changes definitely still worked correctly; I could change tracks on the empeg front panel and they changed on the car stereo screen. Yet still I could not change tracks or play/pause with the touchscreen or steering wheel.
- But here's what's interesting. *After* I had confirmed the above behaviors and I had a repro, *THEN* I engaged Siri with the Siri button on my car steering wheel. And you know what happened? THE EMPEG PAUSED.

This tells me that the car stereo headunit has no problem sending commands to the BlueGigaEmpeg when it feels like it wants to do so. All the messaging and handshaking *WORKS* as designed. The only issue is that sometimes my car stereo boots up and it doesn't feel like sending commands to my empeg.

I think this is a Honda bug and there's nothing I can do about it. Closing bug until I think of some way that the above thing could possibly be my fault.

Closed 2018-02-10.

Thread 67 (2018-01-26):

Silent playback after cold boot (rare)

tfabris, 2018-01-26:
On extremely rare occasions, I encounter silent playback after a cold boot up on starting the car.

Note: This might be related to issue #70 - Perhaps it is the same root cause with a slightly different manifestation.

Avrcp works fully (track change commands, track titles, etc.), and everything is connected, but there is no audio coming out of the Honda stereo despite the fact that the empeg is playing songs and its volume is turned up.

I vaguely remember a situation once before where this happened when I was on the debug cable, and I think that, at the time, it did not help to issue a "streaming start" command to the Bluetooth chip at that time. Though I feel like I need to double check this. Will need to repro this with debug connected.

In the meantime, a power cycle of the Bluetooth will definitely fix it (long press on top button puts empeg to sleep which removes power from the Bluetooth chip which forces a reboot).

To try, if it repros:
- Use the power button on my Honda car stereo to put the car stereo to sleep and then wake it up again. This does not reconnect Bluetooth; it stays connected when you do this. However if that fixes the problem, it might help narrow it down.
- See if switching to a different input and back again, or engaging and disengaging Siri from the steering wheel, clears up the issue.
- If you catch it with the debug cable connected, try issuing a Streaming Start command. And also save off the logs and look closely at the log to find out which part of the Bluetooth handshaking process got missed.

tfabris, 2018-02-28:
CORRECTION: This is fixed by an "A2DP STREAMING START" command. I repro'd it on the debug cable and issued a streaming start command and it worked and the audio came back. Need to investigate places where I can better add streaming start commands.

Here is a debug output, note where you hand-issued streaming start. The audio worked after issuing the streaming start.

0000001 Built in Arduino Serial has been started.
0000000 BlueGiga Serial has been started.
0000001 Empeg Serial has been started.
0000001 --^ Sending to empeg: W
0000001 BlueGigaEmpeg Version 1.0.96
0000003 Arduino chip type: AT Mega 2560 - Good.
0000005 Serial receive buffer size: 256 - Good.
0000004 Serial xmit buffer size:    128 - Good.
0000004 Pausing empeg for convenience while setting global chip defaults.
0000006 --^ Sending to empeg: W
0000002 Setting Defaults.
0000003 --^ SET CONTROL ESCAPE - 00 0
0000004 --^ SET CONTROL ECHO 5
0000002 --^ SET CONTROL BATTERY 0 0 0 0
0000004 --^ SET CONTROL CONFIG 0000 0000 0000 5100
0000005 --^ SET CONTROL CODEC
0000003 --^ SET CONTROL CODEC SBC JOINT_STEREO 44100 0
            SET CONTROL CODEC APT-X_LL
            SET CONTROL CODEC APT-X
            SET CONTROL CODEC AAC
0000016 --^ SET BT CLASS 280428
0000001 --^ SET PROFILE SPP
0000002 --^ SET PROFILE A2DP SOURCE
0000003 --^ SET PROFILE AVRCP TARGET 1
0000003 --^ SET BT NAME empeg Car
0000003 --^ SET BT SSP 1 0
0000002 --^ SET BT AUTH * 0000
0000003 --^ SET CONTROL AUDIO INTERNAL I2S_SLAVE EVENT KEEPALIVE 16
0000007 --^ SET CONTROL PREAMP 0 0
0000003 --^ SET CONTROL MICBIAS 0 0
0000003 --^ SET CONTROL GAIN 9 0
0000002 Done Setting Defaults.
0000003 --^ Sending to empeg: W
0000002 Performing soft reset of Bluetooth module.
0000005 --^ RESET
0000001 Clearing global variables.
0002651 WRAP THOR AI (6.2.0 build 1122)
0000001 Clearing global variables.
0000002 Unable to send command to empeg, the empeg player application is not yet running: W
0000004 Copyright (c) 2003-2017 Silicon Labs Inc.
0000112 READY.
0007069 -------------------------------------
0000001 empeg player application has started.
0000001 -------------------------------------
0000000 Detected empeg bootup sequence completion, sending pause command to player.
0000007 --^ Sending to empeg: W
0000479 Pausing player on first timestamp after boot up.
0000001 --^ Sending to empeg: W
0008875 CONNECT 0 AVRCP 17
0000279 NO CARRIER 1 ERROR 9004 L2CAP_CONNECTION_REJ_RESOURCES
0000081 AVRCP 0 GET_CAPABILITIES 2
0000003 --^ AVRCP RSP 02FF
0000035 NO CARRIER 0 ERROR 0
0000003 --^ Sending to empeg: W
0000009 SYNTAX ERROR
0004059 CONNECT 0 AVRCP 17
0000141 AVRCP 0 GET_CAPABILITIES 2
0000002 --^ AVRCP RSP 02FF
0000079 AVRCP 0 LIST_APPLICATION_SETTING_ATTRIBUTES
0000004 --^ AVRCP RSP 3
0000059 NO CARRIER 1 ERROR 9004 L2CAP_CONNECTION_REJ_RESOURCES
0000039 NO CARRIER 0 ERROR 0
0000003 --^ Sending to empeg: W
0005340 CONNECT 0 AVRCP 17
0000274 NO CARRIER 1 ERROR 9004 L2CAP_CONNECTION_REJ_RESOURCES
0000103 AVRCP 0 GET_CAPABILITIES 2
0000002 --^ AVRCP RSP 02FF
0000037 NO CARRIER 0 ERROR 0
0000002 --^ Sending to empeg: W
0000008 SYNTAX ERROR
0004980 CONNECT 0 AVRCP 17
0000174 AVRCP 0 GET_CAPABILITIES 2
0000004 --^ AVRCP RSP 02FF
0000090 AVRCP 0 LIST_APPLICATION_SETTING_ATTRIBUTES
0000003 --^ AVRCP RSP 3
0000039 CONNECT 1 A2DP 19
0000178 CONNECT 2 A2DP 19
0000054 AVRCP 0 LIST_APPLICATION_SETTING_VALUES 3
0000004 --^ AVRCP RSP 1 2
0000069 AVRCP 0 GET_APPLICATION_SETTING_VALUE 01 03?
0000004 --^ AVRCP RSP 1
0000053 AVRCP 0 GET_CAPABILITIES 3
0000003 --^ AVRCP RSP 1 2
0000080 AVRCP 0 PDU_REGISTER_NOTIFICATION 5 PLAYBACK_STATUS_CHANGED 0
0000004 --^ AVRCP NFY INTERIM 5 1 2
0000082 AVRCP 0 PDU_REGISTER_NOTIFICATION 6 TRACK_CHANGED 0
0000004 --^ AVRCP NFY INTERIM 6 2 1
0000064 AVRCP 0 GET_PLAY_STATUS
0000003 --^ AVRCP RSP 297765 76000 2
0000065 AVRCP 0 GET_ELEMENT_ATTRIBUTES 01 01?
0000004 --^ AVRCP RSP 1 1 "Scattering Seeds on the Pomegranate Tour"
0000107 AVRCP 0 GET_ELEMENT_ATTRIBUTES 01 02?
0000003 --^ AVRCP RSP 1 2 "Mary Crowell"
0000106 AVRCP 0 GET_ELEMENT_ATTRIBUTES 01 03?
0000005 --^ AVRCP RSP 1 3 "Scattering Seeds on the Pomegranate Tour"
0000102 AVRCP 0 GET_ELEMENT_ATTRIBUTES 01 04?
0000004 --^ AVRCP RSP 1 4 "53"
0000091 AVRCP 0 GET_ELEMENT_ATTRIBUTES 01 05?
0000004 --^ AVRCP RSP 1 5 "4474"
0000081 AVRCP 0 GET_ELEMENT_ATTRIBUTES 01 06?
0000004 --^ AVRCP RSP 1 6 "Folk"
0000095 AVRCP 0 GET_ELEMENT_ATTRIBUTES 01 07?
0000004 --^ AVRCP RSP 1 7 "76000"
0000080 AVRCP PLAY PRESS
0000003 --^ Sending to empeg: C
0000041 AVRCP 0 GET_ELEMENT_ATTRIBUTES 01 01?
0000005 --^ AVRCP RSP 1 1 "Scattering Seeds on the Pomegranate Tour"
0000113 AVRCP 0 GET_ELEMENT_ATTRIBUTES 01 02?
0000004 --^ AVRCP RSP 1 2 "Mary Crowell"
0000081 AVRCP 0 GET_ELEMENT_ATTRIBUTES 01 03?
0000004 --^ AVRCP RSP 1 3 "Scattering Seeds on the Pomegranate Tour"
0000105 AVRCP 0 GET_ELEMENT_ATTRIBUTES 01 04?
0000004 --^ AVRCP RSP 1 4 "53"
0000081 AVRCP 0 GET_ELEMENT_ATTRIBUTES 01 05?
0000004 --^ AVRCP RSP 1 5 "4474"
0000027 --^ AVRCP NFY CHANGED 6 2 1
0000002 --^ AVRCP NFY CHANGED 5 1 1
0000002 Empeg state..................................PLAYING  >
0000078 AVRCP 0 GET_ELEMENT_ATTRIBUTES 01 06?
0000005 --^ AVRCP RSP 1 6 "Folk"
0000077 AVRCP 0 GET_ELEMENT_ATTRIBUTES 01 07?
0000004 --^ AVRCP RSP 1 7 "76000"
0000077 AVRCP PLAY RELEASE
0000033 AVRCP 0 GET_PLAY_STATUS
0000003 --^ AVRCP RSP 297765 76000 1
0000079 AVRCP 0 PDU_REGISTER_NOTIFICATION 9 TRACK_CHANGED 0
0000005 --^ AVRCP NFY INTERIM 9 2 1
0000070 AVRCP 0 PDU_REGISTER_NOTIFICATION a PLAYBACK_STATUS_CHANGED 0
0000004 --^ AVRCP NFY INTERIM a 1 1
0000069 AVRCP 0 GET_ELEMENT_ATTRIBUTES 01 01?
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
tfabris, 2018-03-15:
I think the ultimate solution would be to find out how to prevent other folks from ringing us up (a previously paired host stereo doing a successful RING command against us). Then we would depend entirely on our autoReconnect to initiate the reconnect. However I can't figure out how to do this. The SET BT LAP command does not work for this. So continue to test workarounds for this.

To do:

- Try to test your theory that this is caused by a them-rings-you-up problem by turning off auto reconnect temporarily. Force the other guy to ring you up and see if the repro frequency goes up.

- Try to find a later spot in the code for issuing an A2DP STREAMING START command and see if that fixes the issue.

tfabris, 2018-03-15:
I got another repro on the debugger but it took a hella long time. I was using the disc/reco steps from the Honda front panel (trying to repro issue #70) and stumbled onto a repro.

Issuing an A2DP streaming start didn't instantly fix it, but doing the A2dp streaming start a couple of times and then pressing some play pauses on the empeg front panel did get it working again.

Need to analyze the attached debug log in more detail.

Note: the repro is near the END of this log. Earlier in the log will be my attempts at reproing issue #70 and might in fact be some issue #70 repros in the log. You want to look towards the end to see the issue #67 repro.

[Issue 67 Silent Playback - Another repro from disco-reco from Honda front panel.txt](https://github.com/tfabris/BlueGigaEmpeg/files/1816873/Issue.67.Silent.Playback.-.Another.repro.from.disco-reco.from.Honda.front.panel.txt)

tfabris, 2018-03-16:
You had a theory that it was caused by a too-early "streaming start".

Currently experimenting:
- Increase the lowest number where you perform an A2DP STREAMING START on either the RING or the CONNECT messages.
- Instead of doing it on 1,2,3 just do it on 2,3.
- See if that works on all test systems (I'm particularly concerned about Onkyo).
- If it works on all of them, leave it in place and see if that gets rid of the problem.

tfabris, 2018-03-16:
Tested the 2,3 instead of 1,2,3 fix so far on:
- Honda
- Kenwood
- Plantronics
- Etekcity

Still need to test on:
- Onkyo
- iHome

tfabris, 2018-03-17:
Okay, can't do the "2,3" fix because that induces bug #70 (chipmunk).

I have found that if I issue Streaming Start too early, i.e., if you issue it on "0" while the A2DP channels are still getting set up, then you get silence. GUESS: one of the A2DP channels is a data channel and the other is audio. If this first of the two A2DP channels that connects is the data channel, and you issue the Streaming Start too soon before the second one is set up, then you get no audio because you didn't issue the Streaming Start command after there was an audio channel to start.

Whereas there is some weird thing with the Honda where issuing streaming start too late causes the chipmunk bug. So that's a separate issue.

Working on some custom code now to hopefully handle this permanently. Stay tuned.

tfabris, 2018-03-18:
Custom code which does intelligent triggering of the A2DP STREAMING START command only on the second A2DP message has been implemented in version 1.1.8, and is awaiting some more testing before final PR into Master branch.

tfabris, 2018-03-18:
I believe this is fixed with version 1.1.8 with commit aa4714e16631d2e00532451237b136d01a93c956. Closing for now, can reopen if the issue recurs.

tfabris, 2018-03-18:
Version 1.1.10, commit f2c327aff62d75fea7e1c0d55417f86586be0323, reverts the "streaming start" behavior back to pre-1.1.8 behavior, which is a "dumb" table that may occasionally induce this bug.

Re-opening this bug because it will still recur on rare occasions and I need to fully understand the correct timing with which to induce the Streaming Start command on all devices universally to avoid all possible issues.

tfabris, 2018-03-18:
Idea:

If the issue is caused when the RINGs come out of order like this:

RING 1 48:f0:7b:57:15:20 19 A2DP
--^ A2DP STREAMING START
RING 0 48:f0:7b:57:15:20 17 AVRCP
CONNECT 2 A2DP 19

... Then maybe what I need to do is simply wait for the second and third ones regardless of their number and regardless of whether they're AVRCP or A2DP and just issue the streaming starts in those cases.

This would end up behaving as sort of a hybrid between the "dumb" method and the prior failed attempt at the "smart" method.

That might possibly fix this without inducing additional repros of issue #70.

tfabris, 2018-03-18:
No, I have a log of a second repro (above) where the RING commands came in in order and so I don't know the root cause of this one any more. Back to the drawing
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

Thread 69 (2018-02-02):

Intermittent crackling static on I2S developed recently.

tfabris, 2018-02-02:
Yesterday the I2S audio developed an occasional intermittent crackle sound. Like a digital version of dust on an LP record. This is after weeks of perfect operation.

The crackles are each a single digital "pop" sound that happens approximately once every 10 seconds, but it's very random, so sometimes 30 seconds or more will go by without a crackle, and sometimes you will get several crackles over the span of a few seconds.

The crackles happen in either the left channel or the right channel and it's random as to which channel they occur on. This tells me that it is a digital bitstream error that is very very small and localized, perhaps a single bit error which causes a given byte of audio data to have the wrong number in it, causing the pop.

Originally I had everything working fine on my Rev3 PCB for the BlueGigaEmpeg with the 7.5v Pololu regulator. Everything worked fine for weeks without crackles. Then I got the Rev6 boards in for BlueGigaEmpeg and soldered one together. It worked perfectly for a day with no crackles. Then I left it in the car overnight, and when I started the car up again the next morning there were crackles.

The crackles are mostly noticeable when the music is quiet, but, they are there all the time as long as there is digital music data to send. If you turn the volume on the Empeg front panel all the way down to -infinity (ie all sound is all zero bytes) then the crackles go away. But as soon as there's even the slightest amount of audio data to transmit, the crackles come back.

Best repro steps are:
- Turn volume way down on the empeg front panel but but not all the way down. Do not turn down to "-infinity DB". Turn down to, say, about-40db.
- Then on your bluetooth playback device, turn its  volume up to a decent listening level so that you can hear the music faintly from the empeg.
- Play songs on the empeg, there must be songs playing.
- Wait for a minute or so and listen intently to the output. Listen for pops that sound like dust on an LP record. They will randomly switch back and forth between left and right channel.

I have checked all voltages and done a ton of diagnosis, including ruling out the Empeg, the wiring, the Arduino, and my new Rev 6 board. My current theory is that either the chip or my current Betz board is going bad.

This is troubling because I've fried chips before, and I thought I had solved all those problems. Another Betz board is on its way, and if that one doesn't crackle then I'll have to think about whether I need to look at power issues AGAIN.

tfabris, 2018-02-03:
Tried all of these, did NOT fix:
- Different Empeg
- Different Betz board and WT32i chip
- Different Arduino
- Different Bluetooth output devices (Honda, Plantronics, etc.)
- Different wiring harness
- Fiddling with wiring proximity and twisting of I2S wires on wiring harness
- Different resistor values of voltage dividers (lowering voltage to below 2.5v by two different amounts)
- Various changes to the I2S parameters in the BlueGiga code (removing keepalive, changing bit depth value, changing event parameter, etc.
- Disconnecting serial port
- Removing power from the MAX232 device
- Removing the Pololu power supply and running the Arduino off of 12v.

Tried this and it SEEMED to fix the problem briefly at first but then later, tried again and got the crackling back again:
- Different BlueGigaEmpeg PCB (rev3 with handmade voltage divs versus Rev6 with built in divs)

What does seem to fix the crackling:
- Switching to analog audio. Though I didn't try it with actual sound on the analog channel (didn't have the right cable connector) so I should try that again with actual sound on the analog audio channel. In any case, it doesn't help really, but I think it confirms that the issue is in the I2S and not in the Bluetooth.

TO DO:
- Try lowered voltage pololu (try back to 5v or 6v maybe)
- Try yet another different Betz board
- Try analog audio except this time actually pump some audio through that connection
- Try changing routing of I2S audio wires on the BlueGigaEmpeg board to look for possible proximity interference

mlord, 2018-02-06:
Could it be a grounding issue?  Eg.. run a wire from GND on the empeg (eg, the chassis) to GND on the Betz board, and see if problem goes away.

tfabris, 2018-02-06:
Thanks @mlord, I will definitely try that! I have high hopes for putting the C16 470uf cap back as well, I'm about to try that right now.

tfabris, 2018-02-06:
Tried the following, unfortunately did not work:
- Adding additional grounding between bluetooth board and the empeg chassis as @mlord suggested.
- Adding additional grounding to the AGND line on the bluetooth board.
- Removing grounding to the AGND and cutting the AGND jumper on the bluetooth board.
- Adding back the 470uf cap at C16.

Tried the following which seemed to maaaaaaybe help:
- Used long standoffs to separate the Betz board from the BlueGigaEmpeg board by about an inch or two. This seemed to reduce the crackling but did not eliminate it.

TO DO:
- Working on the theory that this is some kind of proximity interference, try rerouting the I2S connections on the BlueGigaEmpeg board completely and see if their positioning affects the outcome.
- Working on the theory that adding back the C16 470uf cap was the right idea, but that all my Betz boards now have a damaged internal regulator inside the WT32i chip because I removed the cap, await the arrival of the new set of Betz boards from China and see if leaving the cap in place on a new board solves the problem.

tfabris, 2018-02-06:
Works:
- Handmade test, running the I2S connections and the voltage divider resistors outside/away from the board assembly.

This tells me that the problem is some kind of interference, but what/how. Why did the R3 board have less of it than the R6 board?

Things to think about:
- R3 board had hand-made voltage dividers with slightly more separation between their lines than the R6 one has on its copper traces.
- R3 board had those voltage dividers positioned over two layers of ground plane, and that ground plane was between the vdivs and the Arduino CPU. Perhaps it's Arduino RF emissions tangling with the signal on the I2S lines?
- The I2S connections, the wires themselves, on either the R3 board or my handmade test, might be a bit thicker than the traces on the R6 board. Maybe thicker traces on the next R7 board?

tfabris, 2018-02-06:
Moving the SCK wire closer to the Arduino produces some pops.

tfabris, 2018-02-06:
Moving WS wire closer to the Arduino did not immediately produce any pops.

tfabris, 2018-02-06:
Moving the SD wire closer to the Arduino did not immediately produce any pops.

Theory:
- Only the SCK wire is the issue, and we merely need to route it as far away from the Arduino as we can and make sure the voltage divider resistors are protected by ground planes.

tfabris, 2018-02-06:
Tried:
- Routing the SCK wire differently and putting all voltage divider resistors on the opposite side of the PCB as the Arduino. Also completely cutting the original SCK trace at both ends so that it doesn't act as an antenna. This didn't fix the problem. My guess is that it's because in the Rev6 design there's not a lot of ground plane shielding between the voltage divider resistors and the Arduino.
- Fashioning a makeshift RF shield out of aluminum foil covered with tape and using it to cover the Arduino chip itself. Didn't really seem to do much, but that might be because I didn't ground it well or because it wasn't properly shaped.
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
tfabris, 2018-02-06:
To do:
- Read the heck out of this:  http://www.ti.com/lit/an/szza009/szza009.pdf

mlord, 2018-02-06:
Good work.  Google this:  "isolation routing", and try applying it to the SCLK line (and others if you can).
I think sn00p even posted some nice photos of such on the BBS.

tfabris, 2018-02-06:
Hey @mlord what do you think of this? This document here....
http://www.ti.com/lit/an/szza009/szza009.pdf
... says something interesting:

> "In the case of an I/O pin in the input mode, the capacitance of the unused output transistors transfers noise from both power rails to the pin. The amount of noise is based on the impedance of whatever is connected to the pin. The higher the impedance, the more noise comes out of the microcomputer. That is why unused inputs should be tied to the lowest-impedance rail: ground, by direct short, if possible."

Do you think it would be worth it to try simply grounding all the unused analog and digital I/O pins on the Arduino? Right now I just leave them untouched.

I could also, in the code (i.e., no physical board changes), change all I/O pins from their default setting of "INPUT" to the alternative "INPUT_PULLUP", but I don't know if that would help. I was worried that changing them all to pullups would require more overall power draw for the Arduino board.

tfabris, 2018-02-06:
I'm reading some stuff on the internet such as this...
https://arduino.stackexchange.com/questions/574/should-all-unused-analog-input-ports-be-tied-to-ground-for-accurate-a2d-measurem
... which says that setting the pins to either "INPUT_PULLUP" or setting them to "OUTPUT" and "LOW" (essentially pulling them to ground) will reduce noise emitted by the Arduino. The Pullup uses a small amount of energy, Output/Low uses the least energy. Does that sound right to you, @mlord?

tfabris, 2018-02-07:
To Do:
- Try grounding the RESET line and holding the Arduino in reset mode to see if that stops the interference. That will narrow it down to be the Arduino for sure. Suggested by Shonky on EmpegBBS.
- Try setting all unused pins to Output/Low or INPUT_PULLUP and see if that stops the interference.

mlord, 2018-02-07:
You are not using the A2D (analog to digital sampling) pins, so there is no need to fuss much about those particular pins.  But setting all of the unused ones to INPUT_PULLUP shouldn't hurt -- the internal pull-up is 10's of K-Ohms, so the power draw/waste ought to be pretty small.

tfabris, 2018-02-07:
Tried the following, none fixed the issue:
- Setting all unused pins, both digital and analog, to OUTPUT/LOW.
- Setting all unused pins, both digital and analog, to INPUT_PULLUP
- Holding Arduino RESET line to ground.

I'm not sure if holding the Arduino reset line to ground truly sleeps the chip or not, so more investigation is needed there.

tfabris, 2018-02-07:
Tried, did not fix the issue:
- Putting arduino chip to sleep with this code:

      set_sleep_mode(SLEEP_MODE_PWR_DOWN);
      sleep_enable();
      sleep_cpu();

tfabris, 2018-02-08:
Tried, based on @mlord suggestion:
- Changing 10k voltage dividers out for lower values to increase S/N ratio on the I2S lines at the expense of increased current draw from the empeg.

Result: With 2.33k of resistance (doubled up 4.7k's) there was a significant reduction in pops, though not completely fixed.

TO DO:
- Try 2.0k resistors and redesign the Betz board to rotate it 180 for shorter I2S runs.
- Check empeg interior for hot components in case the additional current draw is a problem.

tfabris, 2018-02-08:
Tried:
- Going down to about 1.55k ohms on the voltage dividers by tripling up the 4.7k resistors (my PCB is a work of art, I tell ya).

Result:
- Pops are almost completely gone. Down to about one pop per song.
- I'm not noticing any unusual heat from the SA7705H or the WT32i.

To do:
- Order a passel of 1.5k resistors.
- Run it this way for a week or so to see if the empeg fries.
- Decide if that's enough, or if I still need a board redesign, too. Keeping in mind that the pops are not noticeable when the music is loud, they are only noticeable in the quiet passages and only if the headunit stereo volume is turned up to a decent amount.

tfabris, 2018-02-09:
Closing issue. 1.55k resistors seems to work and I have 1.5k on the way. Happy dance!

Closed 2018-02-09.

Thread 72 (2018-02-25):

Very quiet music is beneath the Bluetooth “floor”.

tfabris, 2018-02-25:
Songs which start out very quietly and fade in slowly from nothing, do not immediately make sound.

Bluetooth encoder appears to have a “floor”, below which the chip doesn’t even bother to encode and send audio at all.

This isn’t a noise or gain problem because the audio is a perfect digital bitstream, and also the problem exists regardless of whether you are using digital or analog audio.

The floor is really low. Only the quietest of sounds drops below it. Example tracks would be the beginning of Dark Side of the Moon, or the start of The Camera Eye. In those cases the audio kicks in only a few seconds after the actual track start. So it’s not a particularly bad problem, and isn’t usually noticeable even on the poster child songs.

To do:
- research to find out if this is normal for Bluetooth A2DP audio.
- see if you can get the AAC codec working and if that solves it.
- see if you can find other iWrap commands which maybe lower that floor. Gain commands will not affect it since we are not using the analog gain stages at all. The docs are clear on this point: "In WT32i, the gain setting only affects the internal ADC & DAC and is ignored for I2S and SPDIF interfaces."

tfabris, 2018-03-04:
Looked for other iWrap commands which might affect this, could not find any.

Whether or not this is "normal" for the Bluetooth SBC codec (Sub Band Codec, the default), is not really relevant if there are no commands in iWrap which let me modify it.

To do: Take another stab at APTXLL codec, and if you can get it working, then see if it fixes this issue.

Don't bother with AAC codec since the docs say that only apple devices support it.

tfabris, 2018-03-04:
Awaiting: Arrival of the CSR USB-SPI programmer so that I can configure the address and license of the BlueGiga chip on one of the unfried Betz boards.

tfabris, 2018-03-13:
Received CSR USB-SPI programmer and it works. I have one board which has a test license for APTXLL on it. It seems as though APTXLL is not supported by my Honda car stereo so APTXLL is a non starter. However I need to perform the controlled experiments to determine if the APTXLL solves the "noise floor" problem still. Since APTXLL didn't work on the Honda, I haven't been able to do a controlled test yet. Will need to poke at this a bit more before giving up on it.

tfabris, 2018-03-13:
To Do:
- Do a solid test of the noise floor with APTX-LL codec.
- You can tell which codec is being used because you can see a message like this at connection time:
``` A2DP CODEC SBC JOINT_STEREO 44100 BITPOOL 2-53 ```

tfabris, 2018-03-15:
Nnnnnnnnnnnnope.

I did a good test while connected with APTX Low Latency mode. There is still a significant "floor" to the bluetooth audio. The floor is exactly the same as in the SBC codec. "The Camera Eye" doesn't make any sound until about 3.5 seconds into the track in APTX LL mode.

Though I was able to get APTX-LL working, the entire process of installing it on the chip was so onerous that even if the licenses from Silicon Labs were dirt cheap, it's not even worth the hassle of trying to obtain the licenses at all, it's not even worth the phone call.

It'd be a different story if we were making a gaming system where latency was critical. It's not critical here.

Another reason to leave the existing SBC codec latency is that the track titles take a moment to show up on the car stereo screen, and the codec latency is real nice because it slows down the audio to be closer to the moment the track titles show up most of the time, so that's kind of a plus.

Finally, APTX-LL is not supported on my own Honda car stereo, so this is useless to me overall.

Closing this issue and giving up on APTX-LL for now.

Closed 2018-03-15.

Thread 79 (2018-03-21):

Honda steering wheel and touchscreen controls don't work sometimes (rare)

tfabris, 2018-03-21:
I have only seen this a few times, and I don't know if it's caused by recent versions or not.

Note: this is NOT caused by my issue #71 fix attempt in version 1.1.12 (currently not even checked into Master yet). It happened before that too, and also happened WITH the issue #71 fix attempt, so that's not it.

Symptom is:
- Cold boot of car stereo and empeg.
- Reconnection works normally: The 48k reboot from the issue #70 workaround did NOT occur.
- Audio Connection works.
- AVRCP works and I get track titles, they even work when I change tracks on the empeg front panel.
- Honda touch screen looks fine.
- However honda steering wheel controls and touch screen track transport and play pause commands do not work.
- If I pause, the honda mutes audio but the empeg never gets the pause command and it keeps playing.
- Switching to another input on the Honda does not fix the probem and indeed the empeg keeps playing as if it never got the pause.
- Log shows no attempts to send AVRCP play/pause or track transport commands in the log at all. It's like it's not even trying. This makes me suspect a Honda bug.

Need to analyze logs and compare to baseline to be sure that something weird like a mismatch of the sequence message code number didn't get screwed up.

Logs attached.
[Issue 79 Honda touchscreen controls didn't work.txt](https://github.com/tfabris/BlueGigaEmpeg/files/1832008/Issue.79.Honda.touchscreen.controls.didn.t.work.txt)
[Baseline good reconnect behavior on Honda with 1.1.10 and dumb streaming starts.txt](https://github.com/tfabris/BlueGigaEmpeg/files/1832009/Baseline.good.reconnect.behavior.on.Honda.with.1.1.10.and.dumb.streaming.starts.txt)

tfabris, 2018-03-21:
Another repro happened right away. And I still don't think it's related to issue 71 fix attempt because the logs show that the fix attempt didn't trigger on this repro. Also the LIST function looks correct.

Log attached.

[Issue 79 Honda touchscreen doesn't work - Additional repro.txt](https://github.com/tfabris/BlueGigaEmpeg/files/1832022/Issue.79.Honda.touchscreen.doesn.t.work.-.Additional.repro.txt)

tfabris, 2018-03-21:
Analysis:
- All connection and message registrations are correct.
- There are no differences between a "bad" run and a "good" run in terms of the messages shown in the logs.
- In fact the connection messages and all message registrations are identical across three comparison files:
  - Good baseline
  - Repro 1
  - Repro 2
- The messages were all the same, even down to order in which the A2DP/AVRCP channels connected, and even down to the individual registration sequence numbers.
- After connection, all of the message/responses on the AVRCP channel are correct and the AVRCP back and forth registration messages are identical and the only difference between the files is the track titles.
- Even in the bad case we still see the registrations for GET PLAY STATUS and they all work correctly.
- The only thing missing is that the Honda is not sending the passthrough AVRCP PLAY PRESS commands, etc. They are just not being sent by the Honda.

Conclusion: This is flat out a Honda bug. There is literally nothing I can do about this since the only interface I've got to go on is the iWrap messages, and they all look perfect in the repro cases. If I don't get sent the AVRCP track control commands, there's nothing I can do.

tfabris, 2018-03-22:
Here's another repro if you ever need to revisit this. Fresh powerup of Honda and BGE, iPhone was part of the equation in this case.

I checked to see if tracks changed on the (silent) iPhone but they didn't change.

[Issue 79 repro 1.1.12.txt](https://github.com/tfabris/BlueGigaEmpeg/files/1839201/Issue.79.repro.1.1.12.txt)

tfabris, 2018-03-24:
Here is another repro which went this way:
- Pair up the Honda and the BGE, working fine.
- Power cycle both Honda and BGE
- On the first reconnect after the pair, get the repro.

Does it always only ever happen on the first reconnect after pairing?

Note: in the attached repro the "AVRCP PLAY PRESS" is either the code detcting a connection or me pressing the pause button on the empeg face, it is not from the honda. I tried a bunch of avrcp commands from the honda touch screen and none came through on this log.

[Issue 79 Repro 1.1.13 and Honda - Fresh boot - first fresh boot after pairing.txt](https://github.com/tfabris/BlueGigaEmpeg/files/1844718/Issue.79.Repro.1.1.13.and.Honda.-.Fresh.boot.-.first.fresh.boot.after.pairing.txt)

tfabris, 2018-03-24:
Nope it's not related to first boot after pairing, here it is on the second boot after pairing.

iPhone was present in both of these cases.

[Issue 79 repro with Honda and 1.1.13 - Second boot after pairing.txt](https://github.com/tfabris/BlueGigaEmpeg/files/1844722/Issue.79.repro.with.Honda.and.1.1.13.-.Second.boot.after.pairing.txt)

tfabris, 2018-03-24:
Here is another repro shortly after the last two.

I wonder if this is cause by MICRO TIMING caused by me watching all the messages on the serial console after connect, i.e., I'm heisenberging it by having the serial console hooked up?

[Issue 79 third repro with Honda and 1.1.13.txt](https://github.com/tfabris/BlueGigaEmpeg/files/1844730/Issue.79.third.repro.with.Honda.and.1.1.13.txt)

To do:
- Try it with serial console off, or, with the 1.1.13 connection changes moved up higher. Or both.

tfabris, 2018-03-24:
Repro'd with serial console disconnected, so that's not it.

Try it with the 1.1.13 connection changes moved up higher.

tfabris, 2018-03-24:
Tried several repro attempts with the serial console disconnected and the 1.1.13 connection changes moved up higher. Did not get a repro. Currently working on the assumption that this is micro timing with the Honda only.

tfabris, 2018-03-24:
The output of the LIST command during a bug repro looks like this.

0000019 LIST 3
0000044 LIST 0 CONNECTED A2DP 672 0 0 44 0 0 48:f0:7b:57:15:20 19 INCOMING ACTIVE SLAVE ENCRYPTED 0
0000039 LIST 1 CONNECTED AVRCP 672 0 0 44 0 0 48:f0:7b:57:15:20 17 INCOMING ACTIVE SLAVE ENCRYPTED 0
0000003 ------------------------------------
0000001          AVRCP Channel is:
0000001 1
0000000 ------------------------------------
0000030 LIST 2 CONNECTED A2DP 672 0 0 44 0 0 48:f0:7b:57:15:20 19 INCOMING ACTIVE SLAVE ENCRYPTED 0

tfabris, 2018-03-24:
I have seen this as one possible LIST output when working well (no repro)

0000021 LIST 3
0000044 LIST 0 CONNECTED A2DP 672 0 0 13 0 0 48:f0:7b:57:15:20 19 OUTGOING ACTIVE SLAVE ENCRYPTED 0
0000037 LIST 1 CONNECTED A2DP 672 0 0 13 0 0 48:f0:7b:57:15:20 19 OUTGOING ACTIVE SLAVE ENCRYPTED 0
0000035 LIST 2 CONNECTED AVRCP 672 0 0 12 0 0 48:f0:7b:57:15:20 17 OUTGOING ACTIVE SLAVE ENCRYPTED 0
0000004 ------------------------------------
0000001          AVRCP Channel is:
0000000 2
0000001 ------------------------------------

tfabris, 2018-03-24:
To do:
- See if this ever reproduces at all with version 1.1.13 with no debug cable attached.
- If not, put on the debug cable and see if you can mitigate the potential micro timing problems by moving messages around a bit.

tfabris, 2018-03-25:
I have successfully reproduced the issue with version 1.1.13 and no debug cable attached.

I have also tried to mitigate the micro timing problems by putting the streaming start messages at the top of the handleString routine. That's not it.

I also, on the non-debug-cable-repro, successfully disconnected and reconnected the iPhone from the Honda including a power cycle of the iPhone. This was done while leaving the BGE connected and streaming. This did not fix the issue- Either while the iPhone was disconnected or after it was reconnected. So it's not a question of the messages going to the iPhone connection, it's more like they go into a black hole in the code.
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
tfabris, 2018-03-25:
The most recent version of 1.1.13 has not reproduced this on the Honda without the debug cable (knock on wood). If you don't see a 1.1.13 repro in a few days, close this bug.

tfabris, 2018-03-30:
I got a repro of this last night on 1.1.13. No debug cable attached, but it was the same repro as before: start car, everything is fine but steering wheel and touch screen controls do not work.

tfabris, 2018-03-31:
Since this seems to repro frequently on the debug cable but repros rarely without it, it’s gotta be micro timing.

Need to figure out the exact source of the timing issue.

tfabris, 2018-04-04:
I looked at the logs some more and found:
- My response timing of the various AVRCP and A2DP connection messages, during the connection process, were similar within 1 ms, when compared between repro and non-repro, so I don't think I could speed up the micro timing. I could slow it down, perhaps as an experiment, but I'm not sure that that's what it needs.
- During the connection process, even when I *actually get a repro*, on of the first things that the head unit does is do an "AVRCP PLAY PRESS" at me. It happens here, right around the same time it registers the playback status and track changed notifications:

```
AVRCP 1 PDU_REGISTER_NOTIFICATION 5 PLAYBACK_STATUS_CHANGED 0
--^ AVRCP NFY INTERIM 5 1 1
AVRCP PLAY PRESS
--^ Sending to empeg: C
AVRCP 1 PDU_REGISTER_NOTIFICATION 7 TRACK_CHANGED 0
```

So the Honda knows how to send a "play press" just fine, and it sends it once at start up and message registration time.  Sometimes it registers those two messages in a different order, but the repro doesn't follow the order, the order seems unrelated to the message registration order.

Also sometimes I see it do two PDU registrations in order and the numbers aren't sequential. For example sometimes I see:

AVRCP 1 PDU_REGISTER_NOTIFICATION 5 PLAYBACK_STATUS_CHANGED 0
AVRCP 1 PDU_REGISTER_NOTIFICATION 6 TRACK_CHANGED 0

And sometimes I see:

AVRCP 1 PDU_REGISTER_NOTIFICATION 5 PLAYBACK_STATUS_CHANGED 0
AVRCP 1 PDU_REGISTER_NOTIFICATION 7 TRACK_CHANGED 0

Unfortunately I see either one in both repro and non-repro situations, so that's not related.

All of this is happening during the flurry of initial registration messages. It's initially connecting, and in the process of initially connecting, it tells me to "play" and I do. And that causes me to respond with a "changed track" notification but it is sometimes buried in the flurry of queries for the track information. However I can't see a pattern as to the timing of these. When these happen, they seem to happen equally whether it's a repro or a non-repro situation. Still, this is a tricky area and I should investigate it more.

To do:
- Try to get more live repros on the debug cable and see if it's related to trying to respond with a track change notification happening while the honda is gathering track data from the BGE.

tfabris, 2018-04-09:
ALSO TO TRY:
- I recently experimented a bit, and this code doesn't actually work the way I expect it to work:

```
  // Make sure the main serial port is available before outputting.
  if (Serial)
  {
```

The goal of the the code above was to prevent the BGE from logging to the serial port when the USB cable was unplugged. This turns out to not be the case, it's doing all of its serial port logging to the main Arduino USB port all the time, regardless of the state of the USB cable.

This means that the micro-timing might be affected if I have a boolean flag to add or remove all logging. So it might be worth it to disable all logging behind a boolean flag, and see if that fixes this bug.

tfabris, 2018-04-09:
Nope, turning off all logging does not fix issue #79, I got a repro shortly after.

I might merge in the change with logging defaulting to true anyway though. In case I need to try messing with it to fix other bugs later.

tfabris, 2019-04-10:
Update: I've had a few more repros of this recently, in all cases it was without a debugging cable attached. Just power up the car to go to work, and the steering wheel buttons don't work (track titles are fine though).

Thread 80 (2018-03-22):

No sound comes out of device (rare) possibly related to 1.1.12

tfabris, 2018-03-22:
While experimenting with a way to fix issue #71 (No AVRCP on Onkyo), I encountered two repros of an unusual situation on two different devices (Onkyo and Plantronics): No sound came out of the bluetooth despite the fact that the track was playing and all the audio connection messages looked fine. In fact, all the audio connection messages were identical to baseline "good" behavior where I got sound.

My analysis from the issue #71 thread was:

Onkyo analysis:
The difference in the logs between the "good" and "bad" connections in this case is negligible. There is a slight timing difference in the pairing process, where the pairing was successful during a different stage of the on/off/on/off inquiry process. The "bad" one seemed to respond and connect slightly more quickly (PAIR OK came back at 4.6 seconds instead of 5.2 seconds, and CONNECT 0 A2DP came back at 1.2 seconds instead of 3.2 seconds). But other than that, all messages were identical.

The most confusing part of all this is that the messages AUDIO ROUTE and A2DP CODEC, indicating a good audio stream, were identical between the good and bad repro states, meaning that there is nothing that I could do from my side to have made this any better.

Plantronics analysis:
The messages are all identical down to the last character. There is nothing I can do about this, unless there is some way to prove that this is due to the 1.1.12 attempt.

Consider the possibility that your changes from 1.1.11 to 1.1.12 may have caused this. At the current time 1.1.12 is not yet checked into master, it's on a side branch. Try to get to the bottom of this before you merge 1.1.12 into Master.

To do:
- See if you can get a frequent enough repro of the "no sound" issue to make a determination.
- See if switching back to 1.1.11 fixes the issue once you know the repro.

Attached:
Logs from the analysis

[Issue 71 Onkyo Inititial Pairing with good AVRCP.txt](https://github.com/tfabris/BlueGigaEmpeg/files/1835984/Issue.71.Onkyo.Inititial.Pairing.with.good.AVRCP.txt)
[Issue 71 bad pairing with Onkyo - AVRCP didn't work despite an AVRCP connection (see ending).txt](https://github.com/tfabris/BlueGigaEmpeg/files/1835986/Issue.71.bad.pairing.with.Onkyo.-.AVRCP.didn.t.work.despite.an.AVRCP.connection.see.ending.txt)

[Baseline good behavior on Plantronics reconnect.txt](https://github.com/tfabris/BlueGigaEmpeg/files/1835988/Baseline.good.behavior.on.Plantronics.reconnect.txt)
[Issue 71 No Sound on Plantronics after reconnect (only near end of log).txt](https://github.com/tfabris/BlueGigaEmpeg/files/1835989/Issue.71.No.Sound.on.Plantronics.after.reconnect.only.near.end.of.log.txt)

tfabris, 2018-03-23:
Also to do: double check your repro log examples. Find out if it only repros immediately after pairing, or, if you sometimes get the issue on a simple reconnection.

If it only happens after pairing it’s not a huge deal since the user can simply try pairing again, the user is only expected to pair once in a great while. If the issue happens on reconnections then that’s a bigger deal since reconnections can occur multiple times per day.

tfabris, 2018-03-24:
To do:
- See if you still get this after implementing version 1.1.13 with the new streaming start behavior.
- Make sure that it can be reproduced without the debug cable, since the debug messages can cause micro timing issues.
- Investigate the possibility that this is due to micro timing issues.

tfabris, 2018-03-26:
I did not get a repro on Onkyo or Plantronics when trying them tonight.

I got one non-debug-cable problem immediately after a bad pairing situation on the Onkyo where the BGE sat there for the full 60 seconds as if something had gone wrong in the pairing process. The Onkyo said “empeg Car” but no sound came out. Thing is, an end user would just re-pair in that situation. Which is what I did and then it was fine. After that all reconnects were fine.

Other than that, 1.1.13 has been tested on everything except the Kenwood so once I test that I can close this.

tfabris, 2018-03-27:
Re-analyzing the older logs on this one, and revisiting my older comments, I see the following:
- There is either no difference at all, or, a negligible difference in timing, between "good" and "bad" logs in this case.
- The primary repro is Onkyo right after pairing, and in that log, the LIST command looks fine, and the CODEC and AUDIO ROUTE messages all look correct.
- I haven't had a repro on Plantronics since the final version of 1.1.13, and of the two Onkyo repros I don't see how there's anything I could change, since the logs are all the same between good and bad versions.

Conclusion:
- Close this bug, there's nothing I can do about it.

Closed 2018-03-27.

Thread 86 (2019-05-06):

Investigate: Cutting the "JP4 FTDI UART Enable" jumper might not be needed any more.

tfabris, 2019-05-06:
Currently the assembly instructions for the BlueGigaEmpeg say that JP4 on the BetzTechnik breakout board must be cut, after the WT32i has had its firmware updated.

The intention is to disable the FTDI UART onboard the BetzTechnik breakout board. If this UART is turned on during normal operation, it will interfere with the Arduino's ability to communicate with the WT32i chip directly.

However, reviewing the schematics, I am reminded that the +5v input is not connected to anything in the final version of the BlueGigaEmpeg. It is possible that the cutting of the jumper is not needed. If this is true, it will save time during assembly.

To Do:
- Experiment with closing the jumper on one of the units that you're currently in the process of assembling. You've already cut those jumpers but you could resolder one of them to test this.
- With everything fully assembled, use a multimeter to test if there is any continuity between any power supply pins and the input pin to that UART.
- If that looks OK, connect the unit to power and see if it works in bench tests. If so, this is promising!
- Do the same on your production unit in the trunk of your Honda. Live with it long term, and see if everything continues to work as expected.
- If everything works, edit the README.md and the BlueGigaEmpeg Schematic.pdf to remove the instructions for cutting the jumper.

tfabris, 2019-05-09:
Done:
- Tested one unit with jumper closed, but not yet tested long-term and not yet tested in production vehicle.
- Continuity tested the +5v input on the UART with the jumper closed. The only connections to it were the +5V input and the CHG input, neither of which are connected to anything else in this design/configuration.
- Made sure all functions worked when paired with Etekcity bluetooth adapter. Pairing, play/pause, all serial I/O, music playback, all seemed fine.

To do:
- Close the jumper on the unit in your Honda and see if it works long term.
- Update the instructions regarding all references to cutting the jumper.

Note: I have not shipped any units with the jumper closed yet. Currently I'm sitting on three completed units and all of them still have the jumper cut. I have no reason to change them at this time.

tfabris, 2019-05-16:
I have:
- Soldered the JP4 jumper on my daily driver unit.
- Tested that the UART works, by checking that the SerialDFU tool sees the WT32i correctly.
- Tested that the BlueGigaEmpeg works, by checking that I can see all information clearly on the USB cable when plugging the BGE into it.
- Updated the

To do:
- Put the daily driver unit back into the car and live with it for a while.

I am closing this bug. If everything works fine, this bug is done. If not, reopen it.

Closed 2019-05-16.

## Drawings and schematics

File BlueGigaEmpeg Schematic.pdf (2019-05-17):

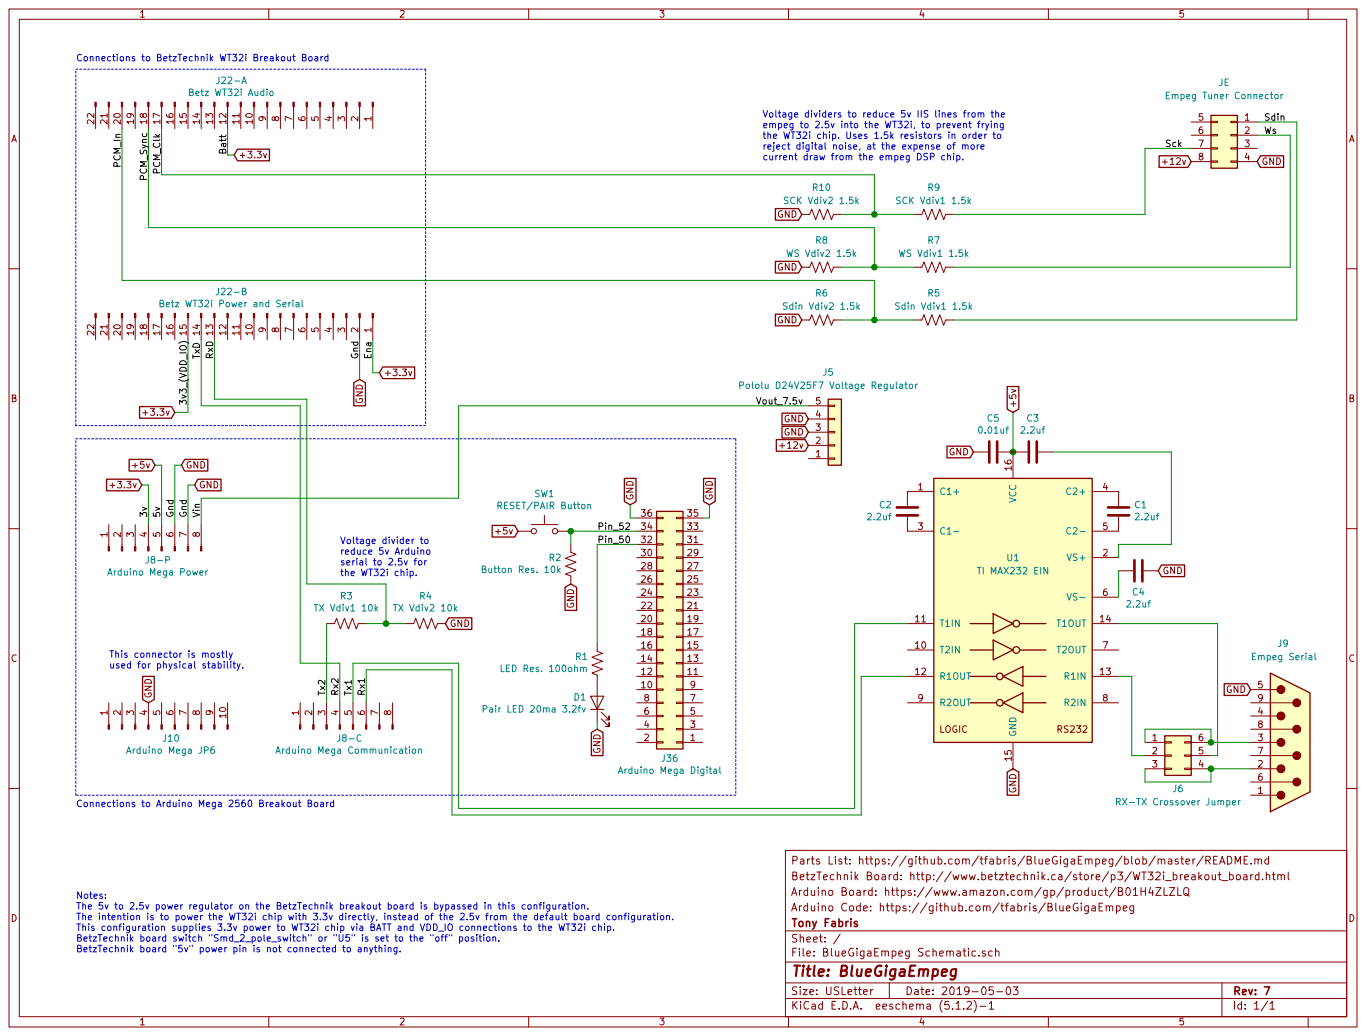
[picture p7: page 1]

2.2uf Connections to BetzTechnik WT32i Breakout Board

empeg to 2.5v into the WT32i, to prevent frying
the WT32i chip. Uses 1.5k resistors in order to
reject digital noise, at the expense of more
current draw from the empeg DSP chip.

Betz WT32i Power and Serial 1

J36 Arduino Mega Digital SW1 RESET/PAIR Button

This connector is mostly

used for physical stability. Notes: The 5v to 2.5v power regulator on the BetzTechnik breakout board is bypassed in this configuration.

Parts List: https://github.com/tfabris/BlueGigaEmpeg/blob/master/README.md
BetzTechnik Board: http://www.betztechnik.ca/store/p3/WT32i_breakout_board.html
Arduino Board: https://www.amazon.com/gp/product/B01H4ZLZLQ
Arduino Code: https://github.com/tfabris/BlueGigaEmpeg
File: BlueGigaEmpeg Schematic.sch Sheet: / Tony Fabris

The intention is to power the WT32i chip with 3.3v directly, instead of the 2.5v from the default board configuration.
This configuration supplies 3.3v power to WT32i chip via BATT and VDD_IO connections to the WT32i chip.
BetzTechnik board switch "Smd_2_pole_switch" or "U5" is set to the "off" position.
BetzTechnik board "5v" power pin is not connected to anything.

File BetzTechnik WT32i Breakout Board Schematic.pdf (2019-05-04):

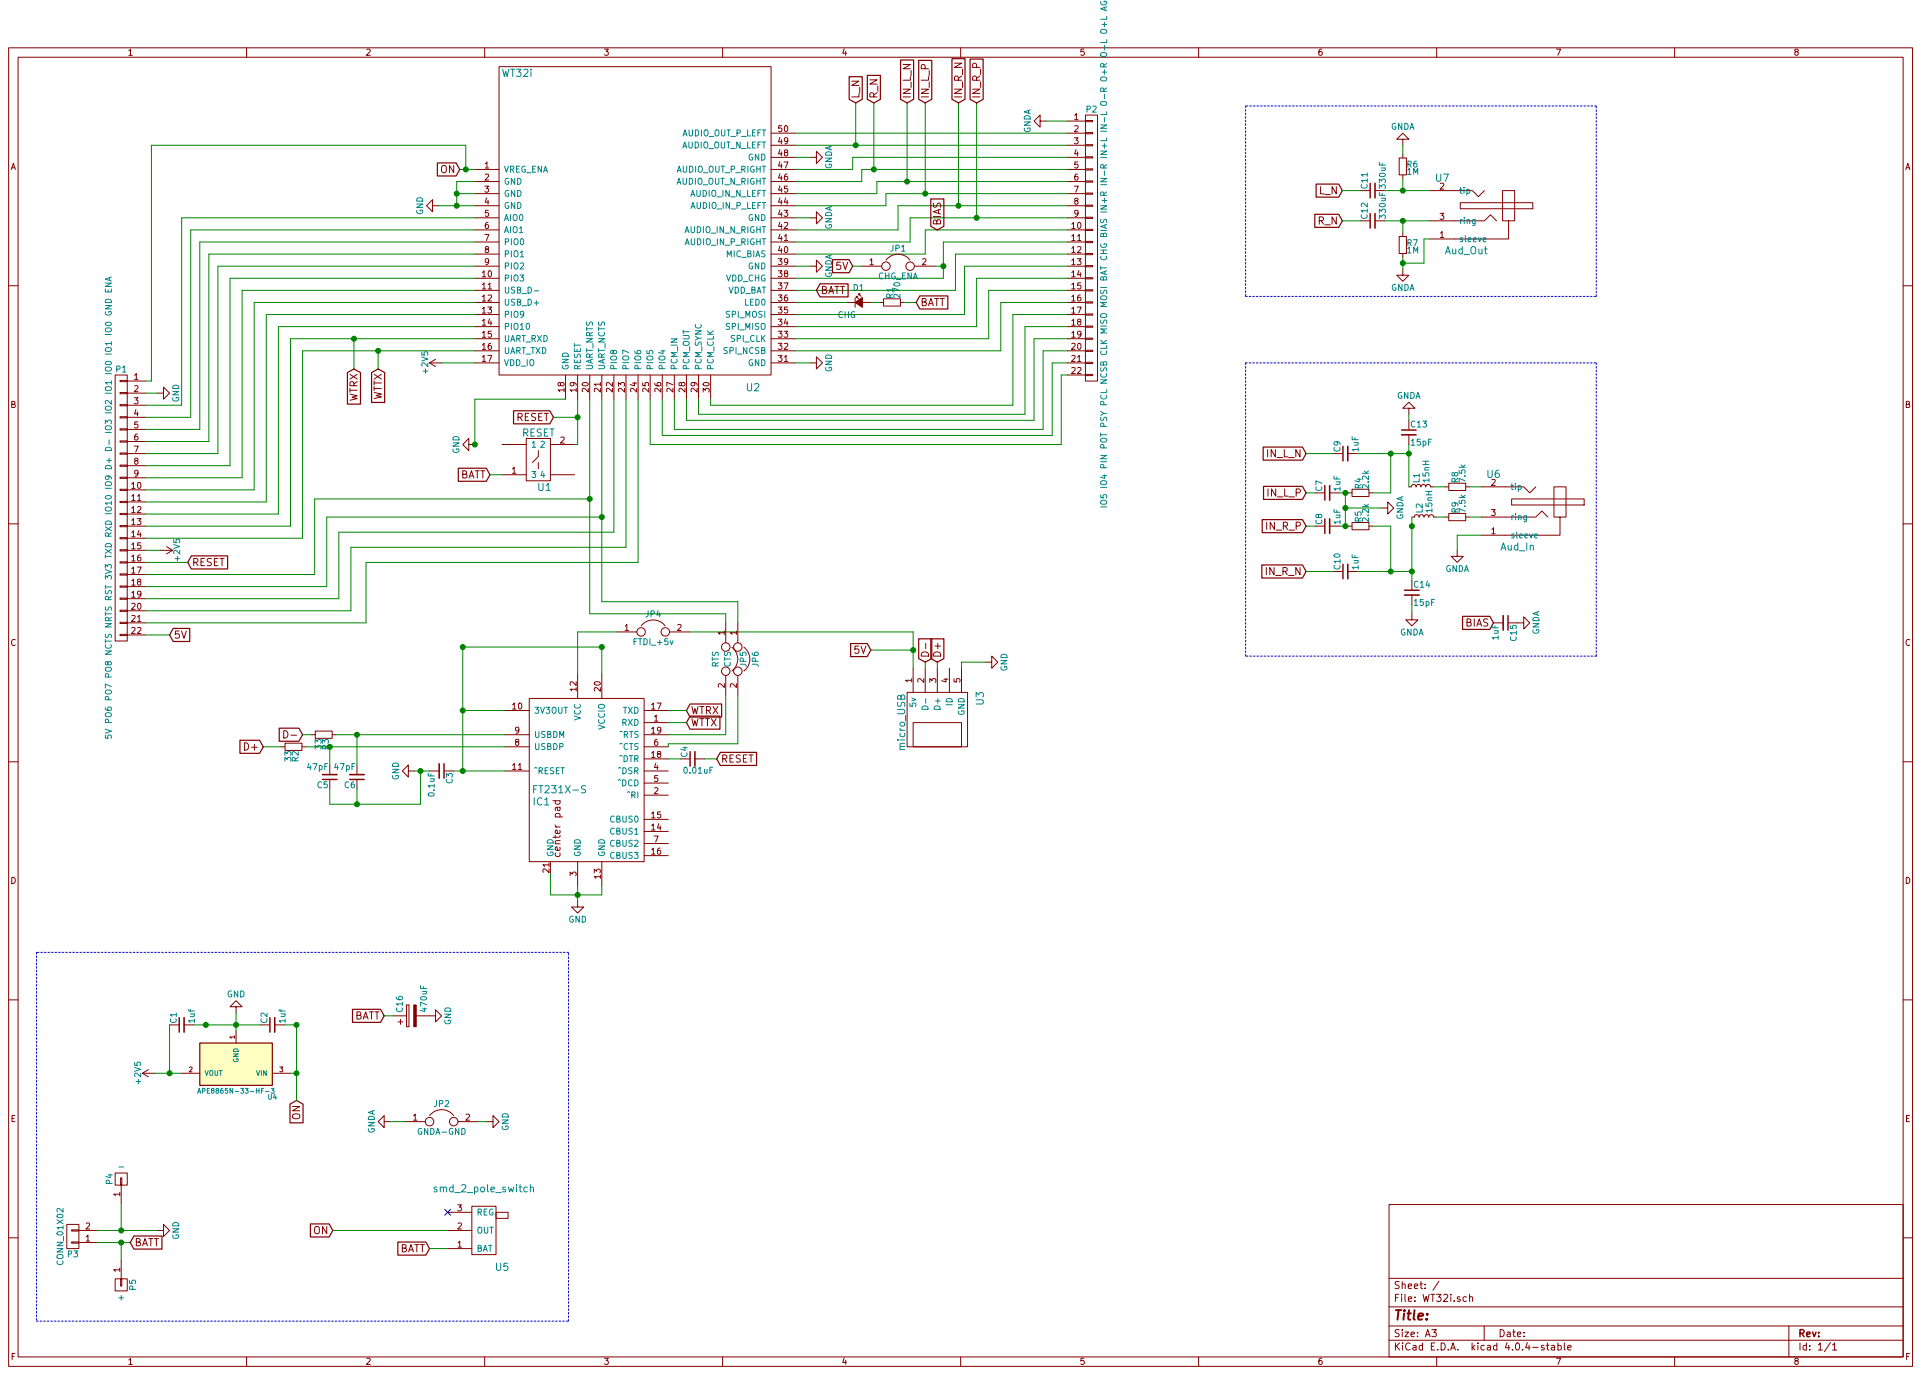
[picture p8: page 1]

19 P2 IO5 IO4 PIN POT PSY PCL NCSB CLK MISO MOSI BAT CHG BIAS IN+R IN-R IN+L IN-L O-R O+R O-L O+L AGND 123456789

Id: 1/1 Title: File: WT32i.sch Sheet: /

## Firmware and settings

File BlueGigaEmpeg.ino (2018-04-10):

// --------------------------------------------------------------------------
// BlueGigaEmpeg
// by Tony Fabris
// --------------------------------------------------------------------------

// A project to use a Silicon Labs BlueGiga WT32i Bluetooth chip, combined
// with an Arduino Mega board with an added RS232 port, to act as an
// intermediary between the empeg Car stereo and a modern car.
//
// Please refer to the accompanying README file for details about the
// electronics interface, and how to modify and configure your empeg Car to
// work with this code.


// ------------------------------------
// Global variables and definitions
// ------------------------------------

// Flag to control whether or not the BlueGigaEmpeg module logs any output to
// its USB debug port. Should be enabled for any debugging session.
//   Setting true:
//   - Connecting a USB cable between the computer and the USB "Type B"
//     connector on the BlueGigaEmpeg module, then running the Arduino Serial
//     Monitor utility, will display useful logging information and allow
//     interaction. It will also slightly slow down the module and affect the
//     micro-timing of command messages which control the Bluetooth chip.
//   Setting false:
//   - No output will appear on the Arduino Serial Monitor and no interaction
//     can occur. This is the fastest operating state of the module.
boolean usbLogging=true;

// String to control the type of Bluetooth authentication that you want to
// use.
//
// Uncomment this line for "just works" pairing with no PIN code, with a
// fallback to the PIN code if the "just works" mode fails. Use this one if
// you are having trouble with the default security scheme below.
//
//        const String btAuthTypeString = "SET BT SSP 3 0";
//
// Default security scheme for "yes/no prompt" security type, required for
// Mark Lord's car stereo. The BlueGigaEmpeg module (this code) will respond
// with a "yes" automatically. You will see your stereo prompt with a
// confirmation number on its touch screen and then it will magically get
// answered automatically and the prompt will go away and you'll be paired.
const String btAuthTypeString = "SET BT SSP 1 0";

// If the device falls back to using a PIN code, here is where to set the PIN.
// Change "0000" to your correct PIN code for your stereo. It can accept PIN
// codes up to 16 digits long.
const String btPinCodeString = "SET BT AUTH * 0000";

// Choose whether or not to display the empeg Serial Port outputs (for
// instance the empeg boot up messages) on the serial debug console of the
// Arduino. Only needed for debugging, not needed for final build runtime.
//   Setting true:
//   - Characters received from the empeg Car serial cable are displayed
//     on the Arduino main serial port debugging console terminal screen.
//     It is mixed in with all the other serial output from the Bluetooth
//     chip all at the same time, so it might be messy if the Bluetooth
//     chip and the empeg are saying things at the same time.
//   Setting false:
//   - No echoing of the empeg Car serial cable output occurs on the debug
//     screen (though the empeg output is still interpreted and acted upon
//     by the software, it's just not displayed on the debug screen).
// This should be set to false most of the time, and only set to true during
// debugging sessions, since it slows down processing to put out too much data
// on the serial port when it is not needed.
boolean displayEmpegSerial=false;

// Variable to control whether output from the empeg and Bluetooth serial
// ports are logged to the debug console character-by-character or line-by-
// line. Here's the trade-off: If you log character-by-character you have a
// clearer picture of exactly when various messages were received from each of
// those devices in relation to each other, but the debug console gets hard to
// read. For instance, if logging character-by-character, the output will look
// like:
//     Bluetooth sends "GOODBYE" 
//     Empeg sends "hello" a microsecond later
//     Debug console output looks like this:
//        GhOeOlDlBoYE
// However if you log line-by-line, it's more readable but you might get the
// wrong idea of who sent what first. It might look like this:
//     hello
//     GOODBYE
// Even though GOODBYE was the first one to start sending characters, he ended
// his transmission last so he gets logged last. This usually isn't a big
// deal. Usage:
//    Setting true:
//      - Output from the empeg and the Bluetooth are logged a line
//        at a time, for additional readability, but order may be wrong.
//    Setting false:
//      - Output from the empeg and the Bluetooth are logged a character
//        at a time, which is less readable but slightly better timing.
// Special note: This isn't fully implemented for every single possible line
// of output on the debug port. There are still a couple places in the code
// where it still logs character by character. If this becomes a problem then
// I will address it at that time later. In the meantime, this handles most of
// the situations where we'd want to see it log line by line.
boolean logLineByLine=true;

// Choose whether or not to display millisecond deltas with each log line.
//      Setting true:
//           - Each logged line of output prints a delta, in milliseconds,
//             which is the difference from the last logged line of output,
//             for profiling.
//           - Logged output is not accompanied by a milliseconds number.
// Note: Recommend turning on this feature only when "logLineByLine" is true.
boolean outputMillis=true;

// Choose whether or not to display the interpreted track metadata on the
// Arduino debugging serial/USB console port.
//      Setting true:
//           - Each time there is new track metadata collected, a block of
//             text displaying all of that metadata gets displayed on the
//             Arduino debugging console.
//      Setting false:
//           - Track metadata is processed normally but the text blocks
//             listing all the metadata in one group is not displayed on
//             the Arduino debug serial/USB console.
// This should be set to false most of the time, and only set to true during
// debugging sessions, since it slows down processing to put out too much
// data on the serial port when it is not needed.
boolean displayTracksOnSerial=false;

// Variable to control whether or not this program performs a conversion of
// High ASCII to UTF-8 in the code. For instance, on the empeg, you might have
// a track by "Blue Öyster Cult", with the "Ö" being represented by a High
// ASCII character (a single ASCII byte with a value greater than 127). In
// that situation, you might see the the car stereo's LCD touchscreen display
// say "Blue ?yster Cult". With this variable set to "true" it will instead
// convert that to UTF-8, which should be readable by your car stereo touch
// screen. If you encounter problems with some track titles which might
// already be encoded as UTF-8 on your empeg, then try setting this value to
// "false" and see if that fixes it.
//   Setting true:
//      - Character values between ASCII 128 and ASCII 255 in the track metadata
//        on the empeg will be converted to their UTF-8 equivalents before being
//        sent up the Bluetooth chain to the car stereo.
//   Setting false:
//      - No UTF-8 conversion will be performed and the track metadata is sent
//        from the empeg to the car stereo without any changes.
boolean PerformUtf8Conversion = true;

// Configure the mode that the BlueGigaEmpeg uses to reconnect to the host
// stereo. Chooses the main reconnection string that commands the Bluetooth
// module how to behave at power-on, in terms of how it attempts to reconnect
// to its previously-connected pairing buddy (if any).
//      Setting 0:
//           - Disable reconnection. A blank string is sent to the Bluetooth
//             chip instead of sending a command to automatically reconnect.
//             This prevents the BlueGigaEmpeg from automatically connecting
//             again after having been previously paired. It will be up to the
//             host stereo to initiate automatic reconnection in this case.
//             Note: If you want to use this non-default setting, you must do
//             the following: You must upload the modified code to the
//             BlueGigaEmpeg, then with the BlueGigaEmpeg running, you must
//             reset and re-pair the BlueGigaEmpeg unit by pressing the
//             RESET/PAIR button.
//      Setting 1:
//           - Default setting. The Bluetooth chip is commanded to attempt
//             automatic reconnection to the previously-paired host stereo at
//             any time that it is disconnected, including at power-on. It
//             will continuously attempt reconnection in all cases at all
//             times when it is not connected, if there is any previous
//             pairing buddy in its memory.
// This setting should be left at the default value of "1" in most cases.
const int autoReconnectMode = 1;
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
void loop()
{
  // The MainInputOutput returns a CHAR variable. I'm not using it here but I
  // use it elsewhere so it's just a placeholder here.
  static char mainLoopChar = 0;

  // Read and handle all main input/output functions on all serial ports, one
  // character at a time. This runs as quickly as we let it run, since it
  // simply happens each time we go through the main Arduino "loop" function.
  mainLoopChar = MainInputOutput();

  // Read and handle all digital pushbutton I/O's such as the reset/pair
  // button.
  MainPushbuttonHandler();
}


// ---------------------------------------------------------------------------
// Report Chip Type
//
// This is a function to log the type of Arduino Mega chip that this program
// is running on. This is oversimplified and does not show all chip types,
// just a subset of them.
// ---------------------------------------------------------------------------
void reportChipType()
{
  // Check to see if this is an AT Mega type of chip
  if ( SIGNATURE_0 == 0x1E || SIGNATURE_0 == 0x00)
  {
    // Chip is one of the AT Mega type of chip, so
    // check to see which one it is and report it 
    if ( SIGNATURE_1 == 0x95 && SIGNATURE_2 == 0x0F)
    {
      Log(F("Arduino chip type: AT Mega 328p - Warning: This chip may have low memory."));
    }
    else if ( SIGNATURE_1 == 0x98 && SIGNATURE_2 == 0x01)
    {
      Log(F("Arduino chip type: AT Mega 2560 - Good."));
    }
    else
    {
      Log(F("Arduino chip type: Some unknown type of ATMel chip - Warning: This chip may not meet recommended spec."));
    }
  }
  else
  {
      Log(F("Arduino chip type: Some type of Non-ATMel chip - Warning: This chip may not meet recommended spec."));
  }
}


// ---------------------------------------------------------------------------
// Verify Serial Buffer
//
// Report a problem if the serial buffer is not large enough. The Arduino
// header libraries must be edited in order for this program to work, and this
// code pre-checks to make sure that this program was compiled with correctly
// modified header libraries to make sure there is enough buffer space.
// ---------------------------------------------------------------------------
void verifySerialBuffer()
{
  // Create variable to use in this function.
  String myTxBufferSizeString;
  int myTxBufferSizeInt;
  String myRxBufferSizeString;
  int myRxBufferSizeInt;

  // Retrieve variable which was defined in compiler header file.
  myRxBufferSizeString = (String)SERIAL_RX_BUFFER_SIZE;
  myTxBufferSizeString = (String)SERIAL_TX_BUFFER_SIZE;
  myRxBufferSizeInt = myRxBufferSizeString.toInt();
  myTxBufferSizeInt = myTxBufferSizeString.toInt();
  
  // Verify serial buffer size
  if ((myRxBufferSizeInt < 256) || (myTxBufferSizeInt < 128))
  {
    Log("Serial receive buffer size: " + (String)myRxBufferSizeInt);
    Log("Serial xmit buffer size:    " + (String)myTxBufferSizeInt);
    Log(F("------------------------------------------------------------------------------"));
    Log(F("         Compilation problem has occurred with this Arduino sketch.           "));
    Log(F(" "));
    Log(F("  This program requires a larger serial buffer size than standard size.       "));
    Log(F("  The Arduino compiler's header files must be edited to make this possible.   "));
    Log(F("  Please edit the following file, recompile and re-upload this sketch:        "));
    Log(F(" "));
    Log(F("     (install location)/hardware/arduino/avr/cores/arduino/HardwareSerial.h   "));
    Log(F(" "));
    Log(F("  Increase SERIAL_RX_BUFFER_SIZE to 256 and SERIAL_TX_BUFFER_SIZE to 128,     "));
    Log(F("  recompile, and reupload your sketch to the Arduino module.                  "));
    Log(F("  Please refer to the README file accompanying this sketch for details.       "));
    Log(F(" "));
    Log(F("------------------------------------------------------------------------------"));
  }
  else
  {
      Log("Serial receive buffer size: " + (String)myRxBufferSizeInt + " - Good.");
      Log("Serial xmit buffer size:    " + (String)myTxBufferSizeInt + " - Good.");
  }
}


// ---------------------------------------------------------------------------
// MainPushbuttonHandler
//
// Workhorse for handling digital pushbuttons implemented in this assembly,
// for example this routine implements the reset/pair button I made. Includes
// debouncing logic so that you don't try to run the same command multiple
// times from a single button press.
// ---------------------------------------------------------------------------
void MainPushbuttonHandler()
{
  // Record the timestamp of the moment in time that we started this function.
  // This timestamp counts up from the moment the Arduino is powered up. The
  // unsigned long can be up to 4,294,967,295, which in milliseconds is over
  // 1100 hours. So if this value wraps around, I don't know what will happen,
  // but I hope you're not running your car for 1100 hours without turning it
  // off once in a while.
  static unsigned long currentMillis = 0;
  currentMillis = millis();

  // Read the state of the reset/pair button at the time we started this
  // function.
  static int pairButtonCurrentReading = LOW;
  pairButtonCurrentReading = digitalRead(pairButtonPin);

  // Check to see if the state of the button changed since our last reading of
  // it.
  if (pairButtonCurrentReading != lastPairButtonState)
  {
    // If the state was different, then reset the debouncing timer
    pairButtonLastPressedMs = currentMillis;
  }

  // Check to see how long it has been since the last time we got a state
  // change. Only consider the button state to have changed if our time range
  // is outside the time range of our debounce timer.
  if ((currentMillis - pairButtonLastPressedMs) > pairButtonDebounceTimeMs)
  {
    // In here, these actions only take place if the time range is outside of
    // the range of our debounce timer.

    // If the button state has changed, AND we are outside of our time range,
    // then we can take action.
    if (pairButtonCurrentReading != pairButtonState)
    {
      pairButtonState = pairButtonCurrentReading;

      // Only take action if the new button state is HIGH
      if (pairButtonState == HIGH)
      {
        // Okay, we can execute the function that we are supposed to execute
        // if the reset/pair button has been pressed. This function will reset
        // the pairing data, put the device back to defaults, and then go into
        // pairing mode for a short period of time.
        PairBluetooth();
      }
    }
  }

  // Save the current button reading into the last button state, for use in
  // the next run through this loop.
  lastPairButtonState = pairButtonCurrentReading;
}
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

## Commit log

2017-12-09 Updated code comments.
    Updated code comments related to bad PDU Register Notification events that I am unable to respond to correctly. Issue still exists.
    [BlueGigaEmpeg.ino]
2017-12-09 Experimental bluetooth reset in Setup() routine
    Experimental reset of the bluetooth chip when the Arduino starts up. Not enabled yet, but ready to go if I get a repeat of the issue. See issue #2 for details.
    [BlueGigaEmpeg.ino]
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2017-12-11 Fix track number to be 1 based, change reset timings, add pin confirmation
    Track number on empeg serial port is zero-based, so make it 1-based when we interpret it.
    Change around the reset timings to try to fix some pairing bugs.
    Try to work around GitHub issue #2 by resetting the bluetooth if the arduino resets, and resetting the global variables if the bluetooth resets. Experimental.
    Add PIN confirmation "OK" command to pairing process to help Mark Lord's connection issue which is GitHub issue #7 though this will probably not fix it completely.
    [BlueGigaEmpeg.ino]
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2017-12-12 Increase timeout to auto reconnect
    This seems to help the problem described in issue #5 where the host stereo repeately queries for new track titles constantly.
    Still the track title updates on the touchscreen are not as quick as I'd like them to be. Still investigating.
    [BlueGigaEmpeg.ino]
2017-12-14 Different method of reconnecting to host stereo at power on.
    Experimenting with SET CONTROL AUTOCALL instead of SET CONTROL RECONNECT. Also add logging of the RX and TX buffer sizes when they are wrong and need to be fixed.
    [BlueGigaEmpeg.ino]
2017-12-14 Hijack Deduplication Changes
    Update so that it always tells the host stereo about track change data with every change of every line. Because of Hijack's new deduplication fix, "Genre" won't always come out. Seems to work in intial tests but needs more bake time to be sure.
    Also switch back to SET CONTROL RECONNECT and give up on SET CONTROL AUTOCALL because of other problems.
    [BlueGigaEmpeg.ino]
2017-12-15 V523 changes and ResetBluetoothPin routine (provisional)
    This version contains a change in behavior to compensate for the deduplication change in Hijack V523. Instead of waiting for a "trigger" to flag the host stereo for new metadata, it flags the host stereo for every single new line of metadata received. This causes some problems, though, discussing with mark maybe going back to non-deduplication mode.
    This version also contains a routine to use Pin 51 to physically reset the bluetooth module from its RST line, though it is currently disabled due to my board getting fried when I tried it.
    [BlueGigaEmpeg.ino]
2017-12-16 Remove KillAllLogging
    Remove the KillAllLogging variable. It turns out this was already being handled by the "if(Serial)" statements that I already had surrounding the logging points.
    This solves issue #18.
    [BlueGigaEmpeg.ino]
2017-12-16 Move explanatory text into a README.txt file (Step 2)
    Remove explanatory text from the code comments of the main code file.
    Touch up the text in both the main code file and README.txt.
    This completes issue #16.
    [BlueGigaEmpeg.ino]
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2017-12-17 Experimental faster method for ForceQuickReconnect.
    This is intended to address issue #20 but I'm not certain it will be truly faster or if it will even work. Need to test it.
    [BlueGigaEmpeg.ino]
2017-12-17 Reset line code is controlled by a boolean flag.
    This addresses issue #13.
    [BlueGigaEmpeg.ino]
2017-12-17 Analog or digital audio is controlled by boolean variable digitalAudio
    This is intended to address issue #12.
    [BlueGigaEmpeg.ino]
2017-12-17 Fix pairing regression, line by line logging.
    Fix regression caused by recent changes to the pairing address retrieval code.
    Also optimize the code which searches for pair buddy addresses so that it does not need to repeat the same code twice.
    Additional optimizations to the ForceQuickReconnect command.
    Add feature to log bluetooth and empeg output line by line instead of character by character. Addresses issue #11.
    [BlueGigaEmpeg.ino]
2017-12-18 Force Reset, timing, and other bugfixes.
    This set of changes addresses issues #20 and #22 in partial ways. Issue #22 seems to be doing better but issue #20 can't be fixed, so it's closed now.
    Also this update changes the code in the functions DisplayAndProcessCommands and DisplayAndSwallowResponses so that they are based on an actual timer instead of a "Delay(1)" command. Hoping that this will improve the serial buffer overflows in situations where it overflows during these functions running.
    [BlueGigaEmpeg.ino]
2017-12-18 Fix issue 22 and add timer profiling.
    Fix issue 22: Bluetooth headset always comes up in pause mode.
    Add timer profiling to each output line - each output line (in line by line mode) displays a delta from the last line in milliseconds.
    [BlueGigaEmpeg.ino]
2017-12-18 Minor text changes to code comments.
    In code comments, attempt to correct the capitalization of all instances of the name "empeg" which should be the lower-case trademark version except when starting a sentence.
    [BlueGigaEmpeg.ino]
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2017-12-19 Increase serial RX buffer to 256
    Hopefully will help with issue #8 but I have observed it does not fix the issue completely.
    I have been doing some profiling and the track title processing only uses a few milliseconds per line, though maybe I can optimize it more. Still working on issue #8.
    [BlueGigaEmpeg.ino]
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2017-12-19 Reopen issue #14 - Needs more work.
    Reset back to "Just Works" pairing mode. I will need to do some more code work before I can correctly respond to the yes/no in all cases.
    [BlueGigaEmpeg.ino]
2017-12-20 Partial fix to issue #25.
    Partial temporary fix to issue #25, which is caused by a string in Arduino running out of memory. Temporarily fix the issue by passing the string as a reference instead of as a value. This fixes that instance of that string but now there are issues where the logging has some string mangling. More work needed on issue #25.
    Begin experimenting with problems with EmpegStartPause as described in issue #26.
    [BlueGigaEmpeg.ino]
2017-12-21 Fix issue #25
    Hopefully this is a full proper fix for issue #25. This converts many of the global heap variables to local variables, to reduce heap usage.
    Also includes some minor tweaks to code comments and boolean flag placement, and some tweaks to logging.
    [BlueGigaEmpeg.ino]
2017-12-21 Default to Yes/No prompt security.
    This fixes issue #14. The BlueGigaEmpeg module now defaults to the security scheme where the head unit prompts for a particular number on the stereo and the bluetooth module must respond with a yes/no answer. The code will always respond with the "yes" answer to this question.
    This security scheme was required by Mark Lord's car stereo, it wouldn't work with "Just Works" pairing mode.
    [BlueGigaEmpeg.ino]
2017-12-21 Experimental changes to address play/pause issues.
    Experimental changes in logging and play/pause state transitions in an attempt to get more information for Issue #26.
    [BlueGigaEmpeg.ino]
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2017-12-25 Change "send" indicator from --> to --^
    In the debug serial log output, sent commands used to be logged as --> and now I am changing them to --^ because the first one would cause formatting problems when I pasted logs into a GitHub comment.
    [BlueGigaEmpeg.ino]
2017-12-25 Do not send a CALL 17 AVRCP on the first A2DP connection.
    Bugfix, related to but not solving issue #21, and maybe hopefully solving issue #29 (still need to test). When first pairing up with the host stereo, I was originally jumping in and doing a CALL (addr) 17 AVRCP as soon as I got the first CONNECT A2DP message. This is a problem because that means it's trying to set up an AVRCP connection while the host stereo is in the middle of setting up its second (stereo) A2DP channel. This is a problem because it causes security errors during the pairing process. The resulting connection seems to work OK but there was an error message in the process. So fix that by only asking for an AVRCP connect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
    [BlueGigaEmpeg.ino]
2017-12-25 Reword code comments about "experimental"
    Most comments about "experimental" code is no longer experimental. Make a pass through the comments and change the wording so it no longer indicates that these particular things are experimental.
    There are a couple of comments in there still which are still experimental. Those are still in there.
    [BlueGigaEmpeg.ino]
2017-12-26 Change codec back to SBC by default.
    My Honda stereo, despite supporting Apple devices, didn't enjoy having it set to AAC and had problems. Set it back to SBC.
    [BlueGigaEmpeg.ino]
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2017-12-29 Fix compilation error occurring for Mark Lord.
    Mark's compiler didn't like the way I was passing strings by reference to the Log function. My compiler didn't care, but adding "const" to the parameters fixed it for him.
    [BlueGigaEmpeg.ino]
2017-12-30 Additional fixes to hardware reset line.
    Returning hardware reset line behavior to something more sane now that I have discovered that the root cause of the reset line problems was a bad via on the Betz board.
    [BlueGigaEmpeg.ino]
2017-12-30 Fix issue #32 and #38
    This update fixes these issues:
    #32 "Fast forward runs away and gets stuck".It fixes it by canceling fast forward or rewind whenever the player crosses a track boundary and gives us new track data. It only does this if the ff/rew was issued from the bluetooth, otherwise it works normally. This allows the user to do long multitrack fastforwards from the empeg front panel but prevents the runaway from the bluetooth.
    Issue #38 "Track number changes before everything else". This is fixed by merely not sending a track change notification to the bluetooth just because we pressed a steering wheel control. Instead we wait until the empeg tells us something has changed and THE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
    [BlueGigaEmpeg.ino]
2017-12-30 Fix issue #26 - EmpegStartPause
    Fix the issue #26 - "EmpegStartPause does not work as expected".
    There were several other cases and situations where the BlueGigaEmpeg module should be telling the empeg to be paused. Plugged as many of those holes as I could.
    Now that this is complete, the next task is to fix issue #42 - Detect when bluetooth is connected. Then we could do away with the EmpegStartPause flag altogether.
    [BlueGigaEmpeg.ino]
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2018-01-01 Candidate fix for issue #45
    Don't do as many unneccesary "A2DP Streaming Start" commands. These might be confusing and inducing bugs in the host stereo's bluetooth operating system. One of the first things that happens after initial connection is that the host stereo sends a play command to the player, and it's possible that the extra "streaming start" is causing undefined behavior at that crucial time.
    This is just a theory that needs to be borne out over time/testing.
    [BlueGigaEmpeg.ino]
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2018-01-01 Update APTX string in case we use it.
    Related to Issue #30 - Updated the APTX codec enablement string and tested it. We don't have a license for APTXLL yet so, though the strings work, the connect with APTXLL cannot work yet unless we buy a license.
    Also continuing to do code comment reformatting. More to come.
    [BlueGigaEmpeg.ino]
2018-01-01 Slightly increase ignore timeout on physical reset.
    Slightly increase the amount of time that the program will wait and ignore stuff after the physical reset of the chip has been performed. This gets both lines of output instead of just one.
    Also more major reformatting of code comments. Done with this reformatting for now.
    [BlueGigaEmpeg.ino]
2018-01-02 Update codec commands because codecs were being weird.
    There were problems where codecs weren't working right and I saw it was setting more than one codec to priority 0 so I 'm trying to make it forget all codecs except the one I want. That isn't working so I'm trying to set the other codecs to lower prioroties. Not understanding how this works, the dox are bad on this topic. Possibly related to issue #45 but I'm not certain.
    [BlueGigaEmpeg.ino]
2018-01-02 More fixes to codec strings.
    More experimentation shows how to delete codecs from the priority list. I am hoping this will help issue #45 .
    [BlueGigaEmpeg.ino]
2018-01-02 More changes to streaming start.
    Trying to fix issue #45 - One fewer instance of streaming start and changing which channel the other streaming start starts upon.
    [BlueGigaEmpeg.ino]
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2018-01-04 Remove physical reset line from code.
    Wiring for 3v alleviates the need for reset line.
    [BlueGigaEmpeg.ino]
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2018-01-06 Fix issue #43.
    Reduce excessive data messaging during play state and track changes by only sending the state change message needed. Send either TRACK changed or PLAYBACK STATUS changed, instead of always sending both of them together.
    Revamp the HandleEmpegStateChange function and various code comments associated with it.
    [BlueGigaEmpeg.ino]
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2018-01-07 Fix flickering play/pause indicator on head unit touch screen.
    Fix issue #57, where the play/pause indicator is flickering when the player gets play/paused sometimes. Prevent double notifications of play/pause state under some circumstances. Also required that my fix for issue #26 be modified.
    [BlueGigaEmpeg.ino]
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2018-01-08 Only send data up the Bluetooth if there is new data to send.
    Fix issue #56, only send data up the Bluetooth if the data is new data. Optimizes the use of bandwidth and serial clog time on the Bluetooth.
    [BlueGigaEmpeg.ino]
2018-01-08 Fix equality/inequality bug.
    Fix bug in the implementation for issue #56 .
    [BlueGigaEmpeg.ino]
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2018-01-10 Remove ResetLine code and fix issue #42 .
    New design with 3v3 constant power does not require the reset line pin on the Arduino, remove the corresponding code.
    Fix issue #42, create a flag to detect when bluetooth is connected and streaming, and perform different behaviors depending on whether or not it is streaming. First behavior is to pause the player at bootup only if bluetooth is not detected as being paried+streaming. Other behaviors may come later.
    [BlueGigaEmpeg.ino]
2018-01-11 Add Monkey reconnect and TypeZToPair
    Partial fixes for issue #60 but they need some bake time to be sure.
    Add a different reconnect method, Monkey Reconnect, which uses my own code to reconnect instead of the automatic ones built into iWrap6.
    Add feature TypeZToPair which will, if enabled, go into pair mode if you type a Z on the console. Helpful for debugging if the pair button is in the boot.
    A good bug fix for pair mode: Turns out it never clears the prior address if it's currently connected. Fix that.
    Some other minor tweaks and bug fixes, code comment cleanup.
    [BlueGigaEmpeg.ino]
2018-01-12 Experimental fixes to pairing and connection steps.
    Attempting experimental fixes to issues #60 and maybe even #21.
    [BlueGigaEmpeg.ino]
2018-01-12 Perform some memory-saving refactors.
    Since some of my output logging strings were coming out blank, I wonder if this will solve any of the problems I was having when trying to debug issue #60. Not sure. Give it some bake time.
    [BlueGigaEmpeg.ino]
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2018-01-12 Fix regressions introduced by bugfix attempts
    Several regressions were introduced when I did some attempted bug fixes for issue #60 recently. This fixes the regressions that I noticed, and also disables the Monkey Reconnect for now. More work is needed on the Monkey Reconnect before I can do that.
    [BlueGigaEmpeg.ino]
2018-01-13 Attempt AVRCP channel bounce.
    Added routine to bounce AVRCP channel to see if it fixes issue #60. It didn't fix it. Sigh.
    Also change the AVRCP mode type back down from 3 to 1 because 3 wasn't helping anything.
    [BlueGigaEmpeg.ino]
2018-01-13 Fix auto reconnect parameters.
    I think I finally found the root cause of issue #60. The parameters to SET CONTROL RECONNECT were wrong all along. Fixing the parameters seems to take care of the bad PDU registration messages by not making it connect extra channels at the wrong times.
    [BlueGigaEmpeg.ino]
2018-01-13 Tweaking reconnect timing.
    Attempting to make a bug in the Honda stereo go away where the screen says "no device conneted" when the device is connected fine.
    [BlueGigaEmpeg.ino]
2018-01-14 Implement Shuffle, attempt to fix issue #61
    Implemented a response to "GET APPLICATION SETTING ATTRIBUTES" which is simultaneously an attempt to fix issue #61 and also happens to attempt to implement shuffle (since I had to respond with something, I chose Shuffle as the thing to respond with).
    Does not fix issue $61 but I now think that's not fixable on my and.
    Can't test Shuffle just now.
    [BlueGigaEmpeg.ino]
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2018-01-21 Limit number of paired devices to 1.
    Attempt to fix issue #63 by limiting the number of paired devices to 1.
    [BlueGigaEmpeg.ino]
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2018-02-03 Debugging values for Volume
    Added empeg serial debugging values for volume up and down. Helpful for debugging issue #69. Debug console only, works only when EmpegSendcommandDebug is activated.
    [BlueGigaEmpeg.ino]
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2018-02-09 Updates to README and to code comments.
    Code comment fixes and corrections, spell corrections, updates to README, and fixes to some serial port debug text messages.
    No functional changes in this version, just text.
    [BlueGigaEmpeg.ino]
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2018-02-24 typeZToPair and hard-to-reach mounting locations
    Add information about mounting your BlueGigaEmpeg module in hard to reach locations, and how to pair if you can't reach the RESET/PAIR button.
    [BlueGigaEmpeg.ino]
2018-02-28 Failed attempts to fix Onkyo
    Failed attempts to fix issue #71 - Onkyo AVRCP commands do not work. Need to have a rethink about this. Something is still wrong with the reconnect command.
    [BlueGigaEmpeg.ino]
2018-03-01 Continued work on reconnect feature
    Reorganized notes on the reconnect feature and the various things I tried in an attempt to fix issue #71 "No AVRCP on Onkyo".
    This includes many comment updates listing everything wrong with all other possible configurations of the reconnect command.
    Need to test this current version on Onkyo to see if it fixes issue #71.
    [BlueGigaEmpeg.ino]
2018-03-01 Add configurable auto-reconnect modes.
    This contains a work-around for issue #71 "Onkyo AVRCP Commands Do Not Work". If a user encounters a problem where the device does not reconnect to AVRCP, then they can set this to mode "2" which uses an alternate reconnection string.
    There is also an outside ghost of a chance that the newest default reconnection string might also fix the Onkyo problem. But even if it does I want the alternate string option in the code anyway.
    [BlueGigaEmpeg.ino]
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2018-03-06 Boot chip in analog mode then switch to digital
    Attempt to fix issue #70 (Broken up high pitched playback on cold boot) by booting the module into analog mode, then changing it to digitan and doing another reset. This happens in two places: At boot, and at pairtime.
    The issue is so rare that I need to just check this in and live with it a while to see if it fixes it.
    [BlueGigaEmpeg.ino]
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2018-03-06 Revert the analog-then-digital mode changes.
    My attempts to fix issue #70 did not work. Booting the module into Analog mode, then switching to digital, did not successfully fix issue #70, and in fact caused other problems which I ended up having to work around anyway.
    Revert those changes and let's continue to think about how to fix issue #70.
    [BlueGigaEmpeg.ino]
2018-03-14 Reset WT32i if stereo connects at 48khz
    Attempt to work around issue #70 (crackling chipmunk) by rebooting the module if I detect that the stereo connected at 48khz.
    Also experimentally rebooting twice, to see if it will also fix the secondary side effect of AVRCP problems in that case.
    [BlueGigaEmpeg.ino]
2018-03-15 Experimental changes to pairing and discoverability.
    Attempts to find a happy medium betweeen issues #28 and #37 by making the BGE less discoverable when it has an existing pairing buddy, and more discoverable when it doesn't have a pairing buddy yet, or when you have pressed the RESET/PAIR button.
    Make the pairing system alternate between 5 seconds of searching and 5 seconds of listening during the pairing procedure. This hopefully solves issue #37 without breaking anything else, which allows me to pair in the Honda either when I have pressed the pairing button or when I have not pressed the pairing button.
    Update code comments in several places.
    Small changes related to issue #70 and #6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
    [BlueGigaEmpeg.ino]
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2018-03-17 Improve reconnecting when 48khz issue occurs during pairing.
    When working around issue #70 (crackling chipmunk), if you encountered the issue during pairing, the BGE would reboot without any reconnect policy set, causing an even worse UX than originally intended by the work around. Fix this by issuing the reconnect policy string right before forcing the reboot.
    Also this update has some typo fixes and some notes in the code comments related to my attempts to fix issue #70 and #67. More work still needed on those.
    [BlueGigaEmpeg.ino]
2018-03-18 Add intelligent streaming start commands.
    Use more intelligence for the correct time to issue a Streaming Start command. This was an attempt to improve the behavior around issues #67 (silent playback) and issue #70 (48khz cracking chipmunk playback). I believe that it should theoretically completely fix issue #67, though it hasn't put a dent in issue #70 (though it didn't make it any worse).
    There are some other minor code tweaks and improvements in this version as well.
    [BlueGigaEmpeg.ino]
2018-03-18 Version 1.1.9 - Improve Streaming Start behavior further.
    Additional tweaks and bug fixes to the behavior of the code which issues the Streaming Start commands.
    Update a lot of code comments too.
    [BlueGigaEmpeg.ino]
2018-03-18 Version 1.1.10 - Revert streaming start behavior back to old "dumb" method.
    The "smart" streaming start code turns out to induce issue #70 more frequently instead of decreasing it.
    Reverting back to prior method of issuing streaming starts, which is a "dumb" method based on the scFixMessageMatrix table.
    This will re-induce issue #67 but that issue was very rare so I will live with it until I can figure out what exactly is going on with these streaming start commands.
    [BlueGigaEmpeg.ino]
2018-03-21 Version 1.1.11 - Increase pairing time and remove LIAC.
    Attempted several experiments to help issues #37, #28, #70, and #67. None of them fixed the issues and I am rolling them all back. Not using LIAC (SET BT LAP) to limit visibility, and not using the page mode to clamp down on visibility or RING receipts (SET BT PAGEMODE). These things didn't solve any of the problems, I'll try other stuff.
    In the meantime, I have increased the time period that the device stays in pairing mode, from about 30 seconds to about 60 seconds. Updating docs with that information.
    [BlueGigaEmpeg.ino]
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
